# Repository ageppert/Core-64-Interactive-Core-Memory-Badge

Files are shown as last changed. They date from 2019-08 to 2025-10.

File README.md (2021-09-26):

# Core-64-Interactive-Core-Memory-Badge
Weave your own 64 bits of core memory over the top of LEDs to interact with directly using a magnetic wand.



Purchase: https://www.Core64.io

Follow this project at: https://hackaday.io/project/166155-core-64-interactive-core-memory-badge

You are in the development repository. Beta Kits and production version firmware is at https://github.com/ageppert/Core64/

# Hardware Version History (latest on top)

v0.5 Triple Board (added custom LED Matrix) - Beta Test Kits. Beta Kit Repo at https://github.com/ageppert/Core64/

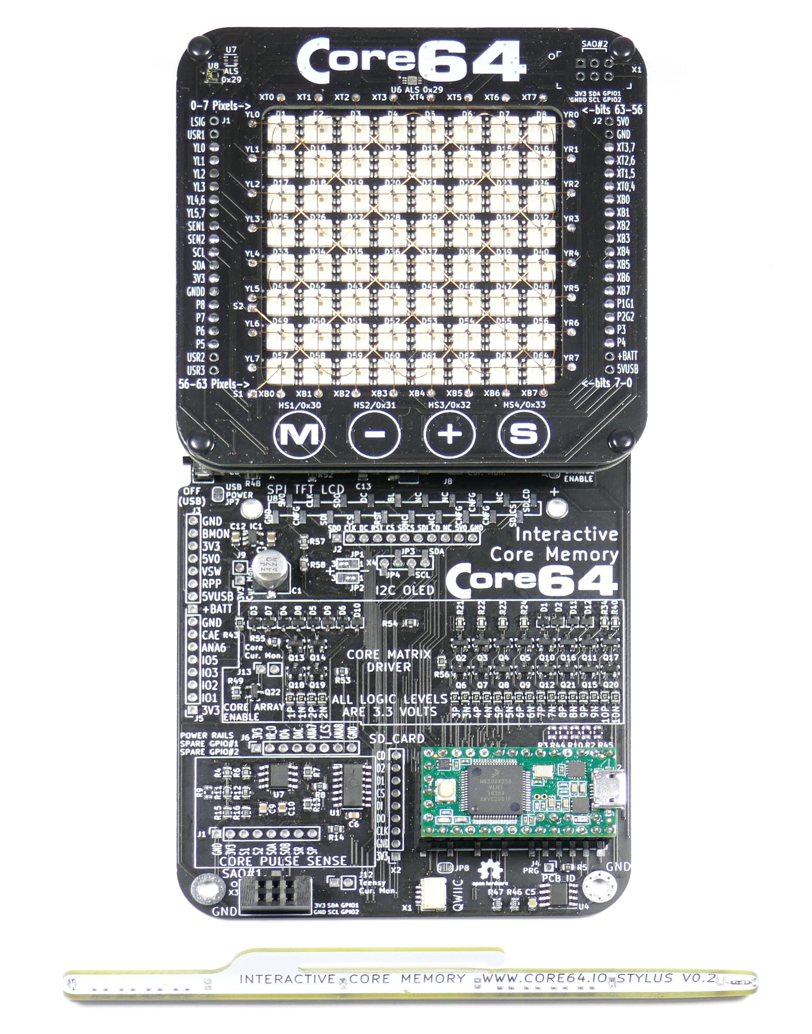
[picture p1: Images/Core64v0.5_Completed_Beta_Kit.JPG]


v0.4 Core Board - Neon Pixel Edition. Expanded Core Grid Array to work with [Neon Pixels](https://pierremuth.wordpress.com/2020/07/08/neon-pixel/)!

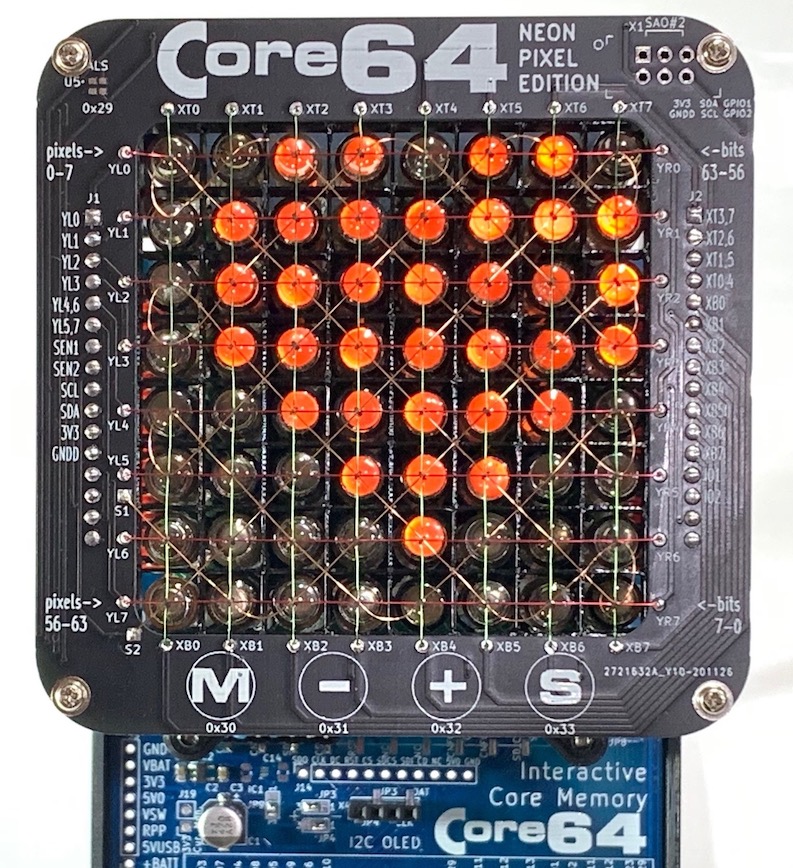
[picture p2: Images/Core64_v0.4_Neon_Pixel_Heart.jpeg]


v0.4 Dual Boards (Blue LB + Yellow CB), moved up to Teensy 3.2, removed IO Expanders, added more expansion/hacking headers.

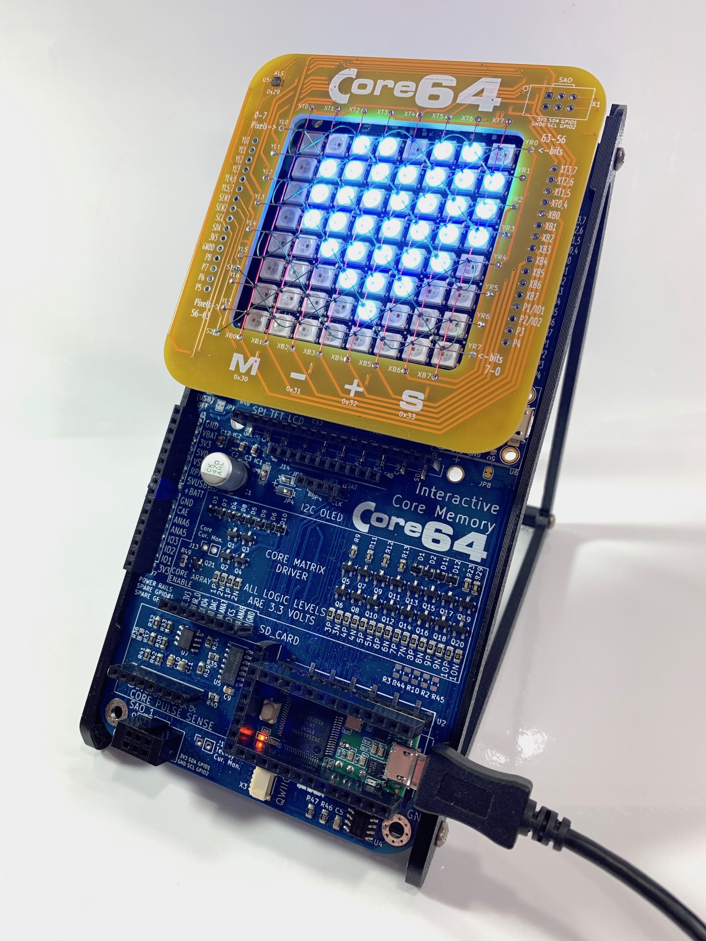
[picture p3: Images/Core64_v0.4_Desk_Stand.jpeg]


v0.3.1 Hand re-worked v0.3 with 5V0 and 3V3 regulators each seperately sourced after power switch to provide improved power supplies.

v0.3 Dual Boards (both Red) with Teensy LC. One core board, one logic board. Used IO Expanders to drive the Core matrix, which ended up being way too slow.

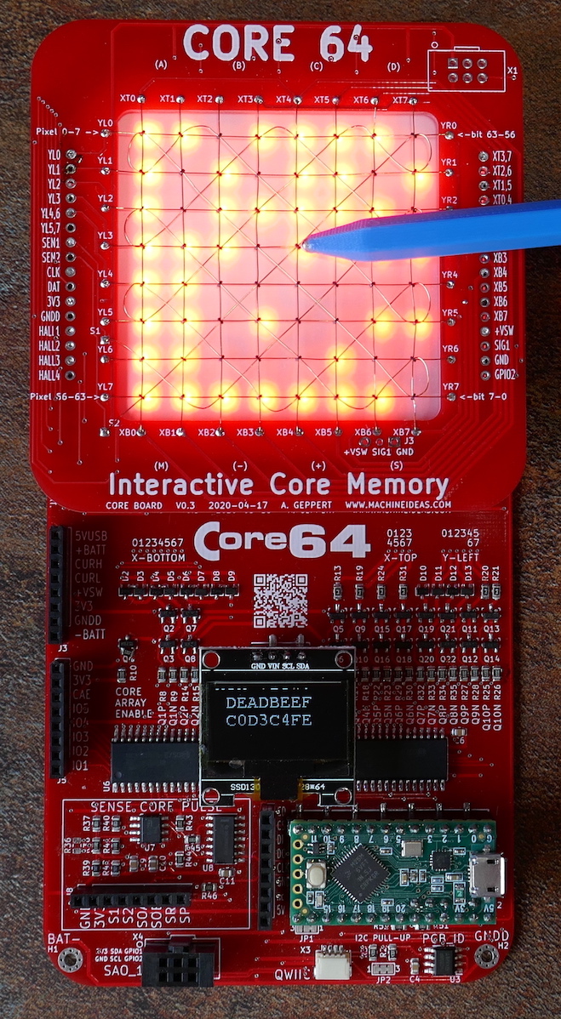
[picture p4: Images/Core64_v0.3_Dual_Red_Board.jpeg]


v0.2 Bug fixes learned from v0.1 applied. This version has not been made or tested, but should work.

v0.1.1 Single Green Board worked after I added missing OR gate circuitry!

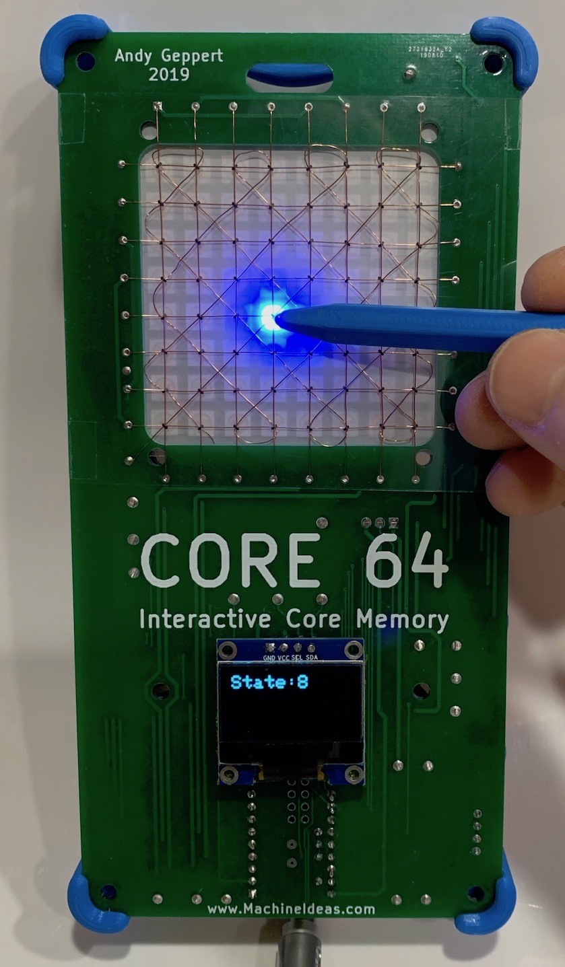
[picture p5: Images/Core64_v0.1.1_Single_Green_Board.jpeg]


v0.1 Single Green Board with Teensy LC. The first hand assembled prototype. Made one and it worked after I added missing circuitry!

Share-A-Hack version

Proof-Of-Concept version

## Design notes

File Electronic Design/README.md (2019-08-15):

# Electronic Design

Datasheets

Native KiCad files for the schematic and PCB. (KiCad Version: (5.1.2-1)-1, release build)

Teensy LC Pin Usage Mapping

BOM

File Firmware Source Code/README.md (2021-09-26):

# Firmware Source Code
Arduino project folder, sketches, libraries.

This firmware was used for development of Core64 V0.1 to V0.5.

It is now dead-ended here with V0.5, and further development is in https://github.com/ageppert/Core64/tree/master/Firmware

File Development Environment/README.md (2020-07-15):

# Development Environment
Everything is being run on a Mac
Arduino IDE 1.8.9 (firmware, see Core-64-Interactive-Core-Memory-Badge.ino for library dependencies)
Teensy Loader (interface between Arduino and Teensy development board)
Sublime Text (source code editor)
KiCad 5.1.2 (Schematic, PCB, BOM)
Inkscape (design sketches and silkscreen graphics)
Sourcetree 4.0.1 (local client for Github repository manager)

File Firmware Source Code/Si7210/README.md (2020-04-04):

# Si7210 Hall-effect sensor driver API
A portable driver written in C for Silicon Lab's Si7210 hall-effect sensor.

## Introduction
This package contains the Si7210 sensor driver.
The driver includes si7210.c, si7210.h, and si7210_defs.h files.

## Integration details
* Integrate si7210.c, si7210.h, and si7210_defs.h files into the project
* Include the si7210.h file in your code like below.

``` c
#include "si7210.h"
```

## File information
* si7210_defs.h : This header file contains definitions used by both the user and driver APIs.
* si7210.h : This header file contains the declarations of the driver APIs.
* lmt01.c : This source file contains the definitions of the driver APIs.

## Supported interfaces
* I2C

## User Guide

### Initialising the device
To intialise the device, the user must create a device structure. The user can do this by creating an instance of the structure si7210_dev. The user must then fill in the various parameters as shown below to initialise the device. THe usermust then choose the particular settings they wish to use, by filling in the 'settings' member of the device struct.

``` c
si7210_status rslt = SI7210_OK;

struct si7210_dev dev = {
    .dev_id   = SI7210_ADDRESS_0;
    .read     = usr_i2c_read;
    .write    = usr_i2c_write;
    .delay_ms = usr_delay_ms;
    .callback = callback;
};

if((rslt = si7210_init(&dev) != SI7210_OK)
    return rslt;

dev.settings.range        = SI7210_20mT;
dev.settings.compensation = SI7210_COMPENSATION_TEMP_NEO;
dev.settings.output_pin   = SI7210_OUTPUT_PIN_HIGH;
 
if((rslt = si7210_set_sensor_settings(&dev)) != SI7210_OK)
    return rslt;

if(rslt == SI7210_OK)
{
    float field;
    float temperature;

    /* Obtain field strength reading from device */
    si7210_get_field_strength(&dev, &field_strength);

    /* Obtain a temperature reading from the device */
    si7210_get_temperature(&dev, &temperature);

    printf("Field: %fmT\tTemperature: %f*C", field, temperature);
}
````

### Templates for function pointers
``` c
si7210_status usr_i2c_read(uint8_t dev_id, uint8_t reg_addr, uint8_t *data, uint16_t len)
{
    si7210_status rslt = SI7210_OK;

    /* User implemented I2C read function */

    return rslt;
}

si7210_status usr_i2c_write(uint8_t dev_id, uint8_t reg_addr, uint8_t *data, uint16_t len)
{
    si7210_status rslt = SI7210_OK;

    /* User implemented I2C write function */

    return rslt;
}

void usr_delay_ms(uint32_t period_ms)
{
    /* User implemented delay (ms) function */
}

```

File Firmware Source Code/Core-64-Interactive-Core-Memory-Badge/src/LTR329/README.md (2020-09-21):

thingTronics LTR303 Arduino Library
========================================
This is a Arduino Library for the LTR303ALS Luminiosity sensor.
This illumination sensor has a flat response across most of the visible spectrum and has an adjustable integration time. 
It communicates via I2C and runs at 3.3V. 

Repository Contents
-------------------

* **/examples** - Example sketches for the library (.ino). Run these from the Arduino IDE. 
* **/src** - Source files for the library (.cpp, .h).
* **library.properties** - General library properties for the Arduino package manager.
* **library.json** - General library properties for the Arduino package manager in JSON format
* **keywords.txt** - Contains the keywords for Arduino IDE.

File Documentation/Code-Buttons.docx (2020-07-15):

Code-Buttons

Core 64: Interactive Core Memory Badge, V0.3, Andrew Geppert, 2020-05-31

User Application

Use the cores to do something interesting

FreeRTOS

Facilitate running all task threads

HAL : Buttons.h

Buttons_Setup

Button1State

TODO:

HAL: Interact with the hardware in an abstract and conceptual way, using high level perspective. Such as visual and logical arrangements.

DRIVER: Control the signals to the hardware and the hardware itself. Control the pins of the microcontroller

Digital Write Fast

Sub-Functions

Digital Write Fast

Controls the electronics through #include HardwareIOmap.h, Arduino.h. Translates active/inactive to low/high for the IO signals.

BSP: Abstraction of MCU pin reference number to the physical pin on the chip

Arduino.c and .cpp in the Arduino IDE

Abstraction of MCU pin to integer pin reference number

Arduino.h

HAL

DRIVER

Hardware V0.1.0 through V0.2.0 the Digital Read Fast library in the LIBRARIES folder.

Hardware V0.3.0 IO Expander MCP2017

This is implemented to talk to the hardware and has many of its own layers and BSPs.

BSP

Combination of files buried in the FastLED Library, and Arduino.

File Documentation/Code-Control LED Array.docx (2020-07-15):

Code-Control LED Array

Core 64: Interactive Core Memory Badge, V0.1, Andrew Geppert, 2020-01-23

User Application

Use the cores to do something interesting

FreeRTOS

Facilitate running all task threads

LED_Array_HAL.h (with new API)

LED_Array_Init (create an instance)

LED_Array_Memory_Clear (all buffers)

LED_Array_Monochrome_Set_Color (color)

LED_Array_Test_Count_Binary

LED_Array_Test_Pixel_String

LED_Array_Test_Pixel_Matrix

LED_Array_Display_Binary ()

LED_Array_Write_Binary()

TODO:

Convert old write/display to new API

Cleanout unused functions

LED_Array_HAL.cpp

Interaction with the abstract memory buffers which define the LED Array for the user to view:

BINARY [64 bit data word, monochrome]

STRING [1D 64 pixel string, monochrome]

MATRIX_MONO [2D 8x8 pixel matrix, monochrome]

MATRIX_COLOR [2D 8x8 pixel matrix, color]

When the buffer is requested for display on the LED Array, appropriate translations are applied for correct orientation of the view to the user.

Enables user application to interact with any abstract LED Array (as a memory buffer) in order to set each real LED as desired.

Interaction is done in one of layouts:

Visual, 1D string, 2D matrix (x,y)

Binary, logical (bits, bytes, word)

And one of two color modes:

Monochrome

HSV

These functions ask the driver (in this case the FastLED library) to do the detailed work.

HAL: Interact with the hardware in an abstract and conceptual way, using high level perspective. Such as visual and logical arrangements.

FastLED.h

src/FastLED Library

Sub-Functions

Bit Banged SPI

FastLED_Config.h

Define my custom LED array params for the FastLED library.

DRIVER: Control the signals to the hardware and the hardware itself. Control the pins of the microcontroller

FastLed.c

Controls the electronics through #include HardwareIOmap.h, Arduino.h. Translates active/inactive to low/high for the IO signals.

BSP: Abstraction of MCU pin reference number to the physical pin on the chip

Arduino.c and .cpp in the Arduino IDE

Abstraction of MCU pin to integer pin reference number

Arduino.h

HAL

LED_ARRAY_HAL.h (defines the API)

LED_ARRAY_HAL.cpp (was LED_Array.cpp).

The application accesses the driver by calling API functions in the driver library.

Set each LEDs on/off or color state in a memory buffers.

Read each LEDs state from the memory buffers.

Clear the memory buffers.

Request a memory buffer to be displayed on the LEDs.

Test functions: cycle through all LEDs in order of 1D and 2D arrangements to confirm expected order of the LEDs.

The driver contains the LED Array memory buffer.

Monochrome 2D 8x8 image as viewed by the user.

Monochrome 1D 64 bit word, with LSB on lower right, MSB on left. First row is low byte of 64 bit word, top row is highest byte.

Color 2D 8x8 image as viewed by the user.

DRIVER

In this case, the FastLED-3.3.2 library in the LIBRARIES folder. Nothing I have to write custom.

This is implemented to talk to the hardware and has many of its own layers and BSPs.

BSP

Combination of files buried in the FastLED Library, and Arduino.

DEFINITIONS

THREE MONOCHROME SCREEN MEMORY BUFFERS

LED SCREEN MEMORY MONOCHROME 2D IMAGE: The LED array as viewed by the user with badge in hand, or looking at C source code array definitions, for the case of symbols drawn on the screen.

Was LEDArrayMonochromeMemory [y][x] : Monochrome version of the LED Screen RAM. Easy to visualize screen memory in the form of C Syntax array. Just make sure to use the proper y, x order because of the C syntax. Upper left is 0,0 and lower right is 7,7.

LED SCREEN MEMORY MONOCHROME 1D PIXEL STRING: A one-dimensional array addressable 0 to 63. Upper left is 0, lower right is 63. Ordered from left to right, then top to bottom.

LED SCREEN MEMORY MONOCHROME 1D DATA: The LED array as viewed by the user, representing 64 bits of data as 8 rows of 8 bits (or 8 rows of bytes) with the least significant bit on the right, and the least significant byte on the bottom. In other words, the whole data value is 64 bits and bit 0 is in the lower right, and bit 63 in the upper left. This is opposite of the LED SCREEN MEMORY MONOCHROME 1D STRING.

DISPLAY ONE OF THE MONOCHROME SCREEN MEMORY BUFFERS USING CORRESPONDING FUNCTIONS

DISPLAY LED SCREEN MONOCHROME 2D IMAGE: Copies the associated screen memory into the appropriate position of the leds[63] array and sends it to the LED array.

DISPLAY LED SCREEN MONOCHROME 1D PIXEL STRING: Copies the associated screen memory into the appropriate position of the leds[63] array and sends it to the LED array.

DISPLAY LED SCREEN MONOCHROME 1D DATA: Copies the associated screen memory into the appropriate position of the leds[63] array and sends it to the LED array.

LED SCREEN ARRAY FASTLED: A virtual two-dimensional array addressable as in the form of y, x with a range of 0 to 7 for both values. This is part of the FastLED example library (/Examples/FastLED/XYMAtrix), and this arrangement is converted to leds[63] with awareness of the serpentine electrical arrangement of the string of LEDs using the functions XY() or YX().

LED ARRAY PIXEL: A single pixel

leds[63]: The one-dimensional array that holds color values for the FastLED library to send to the string of LEDs. The lowest LED Array data level that is easily user accessible. This arrangement follows the serpentine electrical arrangement of the LEDs on the Pimoroni Unicorn Hat.

VisualLED2DMatrix, User LED Matrix [x,y] : The orientation of the LED array for the user.

*** To convert Array to Matrix use function YX(y,x). ***

CSyntaxCORELEDArray, C Syntax LED Array [y,x] : The orientation of the array which aligns with the C language array definition. Note the y position (row) is written first, followed by x position (column). The core matrix wires are labeled this way.

CSyntaxBINARYArray, Binary LED Array [y,x] : The orientation of the array which aligns with LSB in the lower right.

WriteOneBitToMonochromeLEDArrayMemory(uint8_t bit, bool value) : Update a single bit of LED screen Memory. Bit position is defined

LEDArrayMonochromeUpdate() : Read 64 bits of monochrome LED Screen memory and update the LED Array.

FastLED2DMatrix, FastLED (Unicorn Hat) LED Matrix [x,y] : The ordering of the LEDs defined in the FastLED library.

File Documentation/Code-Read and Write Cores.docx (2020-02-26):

Code-Read and Write Cores

Core 64: Interactive Core Memory Badge, V0.1, Andrew Geppert, 2020-02-17

User Application

Use the cores to do something interesting

FreeRTOS

Facilitate running all task threads

Core_Mem_HAL.h (with new API)

IMPLEMENTED

Core_Mem_Bit_Write (bit 0-63, 0/1)

Core_Mem_Bit_Read (bit 0-63)

Core_Mem_Array_Write()

Core_Mem_Array_Read()

Core_Mem_Array_Write_Test_Pattern()

Core_Mem_Monitor()

NOT YET FULLY IMPLEMENTED

Core_Mem_Init (create an instance)

Core_Mem_Test (read all, clear all, verify clear, rewrite original state, verify rewrite, return 0-no test pass, 1st passed, 2nd passed)

Core_Mem_Wipe (set all to 0 or 1)

Core_Mem_Visual_Write (x, y)

Core_Mem_Bit_Toggle (bit 0-63)

Core_Mem_Byte_Write (Byte 0-7, 0-255)

Core_Mem_Byte_Read (Byte 0-7)

Core_Mem_Word_Write (0x0-FFFFFFFF FFFFFFFF)

Core_Mem_Word_Read ()

Core_Mem_HAL.c

Enables user application to interaction with the abstract core memory space (as a buffer) and request read/write to the real core memory.

Interaction is done in one of two modes: Visual (x,y)

logical (bits, bytes, word).

These functions ask the driver to do the detailed work.

HAL: Interact with the hardware in an abstract and conceptual way, using high level perspective. Like visual and logical arrangements.

Core_Mem_Driver.h

AllDriveIoSafe()

AllDriveIoRead()

AllDriveIoWrite()

AllDriveIoSetBit(bit)

AllDriveIoClearBit(bit)

AllDriveIoEnable()

AllDriveIoDisable()

HAL: Control the logical array to access the array of cores

Core_Mem_Driver.c

Translate bit # to row/col position.

Functions to control the array of wires.

Function to read sense signal.

Indirectly controlling hardware as active and Inactive.

Core_Mem_Driver.h

AllDriveIoSafe()

AllDriveIoRead()

AllDriveIoWrite()

AllDriveIoSetBit(bit)

AllDriveIoClearBit(bit)

AllDriveIoEnable()

AllDriveIoDisable()

Sub-Functions

MatrixEnableTransistorInactive()

MatrixEnableTransistorActive()

MatrixDriveTransistorsInactive()

SetRowAndCol (uint8_t row, uint8_t col)

ClearRowAndCol (uint8_t row, uint8_t col)

Translate to New discrete functions:

Core_IO_Enable_Line (on, off)

Core_IO_XY_Lines_All_Safe

Core_IO_XY_Line_Pair (north, south)

Core_IO

DRIVER: Control the pins of the microcontroller

Core_Mem_Driver_Config.h

Define the size, layout, matrix to drive transistor to wire mapping, maybe the MCU memory buffer.

Core_Driver.c

Accesses the core memory bits by directly twiddling the IO lines in the core matrix. Controls the electronics (enable/drive transistors, read sense signal) through #include HardwareIOmap.h, Arduino.h. Translates active/inactive to low/high for the IO signals.

BSP: Abstraction of MCU pin reference number to the physical pin on the chip

Arduino.c and .cpp in the Arduino IDE

Abstraction of MCU pin to integer pin reference number

Arduino.h

2020-01-06 updated thinking on the layers above.

Top Levels as User Application and the FreeRTOS is OK.

Next level down is the DRIVER which has an API defined in it, and accessible from the Application.

Layer below that is the HAL and it reads and writes to the IO lines. But not directly.

BSP is the bottom layer of firmware, and it maps the friendly names of the IO lines in the HAL to the MCU specific pins. To keep things simple, this is effectively the Arduino layer.

Then there is the hardware.

EXAMPLE WITH LED ARRAY

DRIVER

LED_ARRAY_DRIVER.cpp (was LED_Array.cpp) and is in the DRIVERS folder. Includes LED_ARRAY_DRIVER.h.

The application accesses the driver by calling API functions in the driver.

Set each LEDs on/off or color state in a memory buffers.

Read each LEDs state from the memory buffers.

Clear the memory buffers.

Request a memory buffer to be displayed on the LEDs.

Test functions: cycle through all LEDs in order of 1D and 2D arrangements to confirm expected order of the LEDs.

The driver contains the LED Array memory buffer.

Monochrome 2D 8x8 image as viewed by the user.

Monochrome 1D 64 bit word, with LSB on lower right, MSB on left. First row is low byte of 64 bit word, top row is highest byte.

Color 2D 8x8 image as viewed by the user.

HAL

Hardware Abstraction Layer, or in this case, Library.

The FastLED-3.3.2 library in the LIBRARIES folder.

This is implemented to talk to the hardware and has many of its own layers and BSPs.

BSP

Combination of files buried in the FastLED Library, and Arduino.

Set – top end of the column wire and left end of row wire are positive (VMEM). Other ends negative (GNDPWR).

Clear - top end of the column wire and left end of row wire are negative (GNDPWR). Other ends positive (VMEM).

Each end of a single row or column wire can be connected to either VMEM (3-4V) or GNDPWR (0V). That means that two transistors must be enabled for a row or column wire to be energized. Since a core is set or cleared by the current from TWO wires, a total of 4 transistors must be enabled .

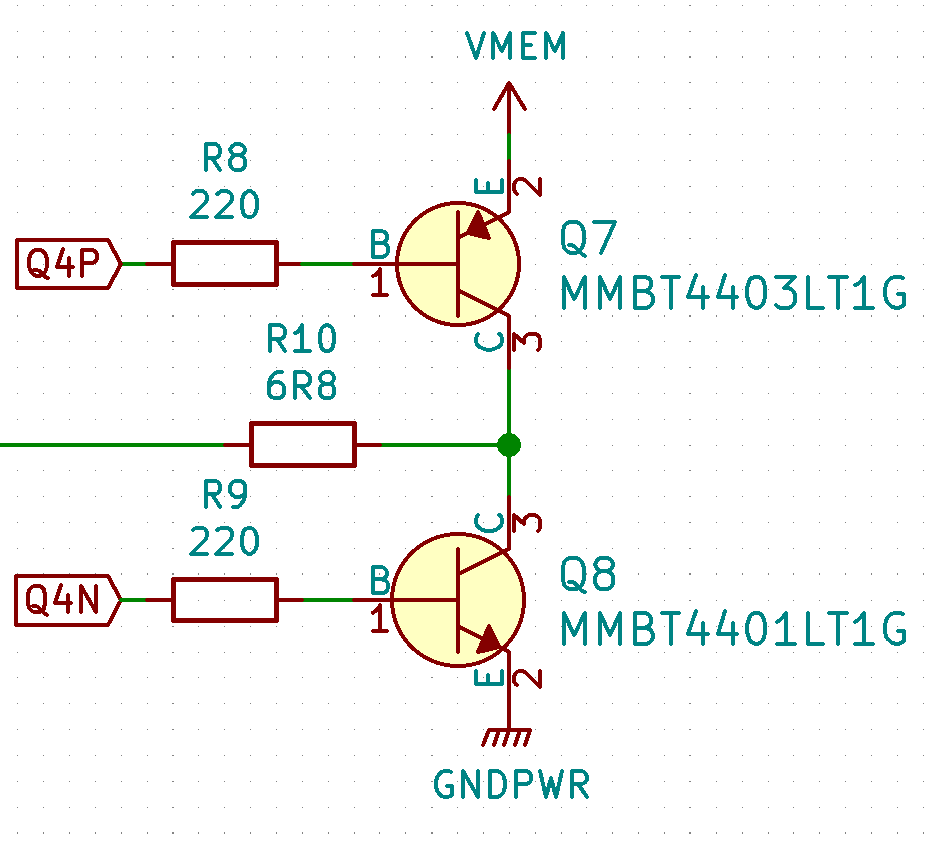
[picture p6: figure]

4403 PNP – Enabled with base LOW, or negative.

High side (sourcing) odd numbered matrix drive pins (7) with P suffix (Q4P). The load is connected to negative and the PNP transistor switches the positive voltage.

4401 NPN – Enabled with base HIGH, positive.

Low side (sinking) even numbered matrix pins (8) with N suffix (Q4N). The load is connected to positive and the NPN transistor switches the negative (low) side.

Safe state, all transistors inactive:

Enable Pin = LOW

Matrix Drive 1, 3, 5, 7, 9, 11, 13, 15, 17, 19 = HIGH

Matrix Drive 2, 4, 6, 8, 10, 12, 14, 16, 18, 20 = LOW

This outline of how it works could be shown as three indented levels. Level one is DRIVER, level two is HAL, level three is HARDWARE.

1. Since the output lines used to address the matrix may have other functions (like 17 is shared with the onboard Teensy LC LED), need to check all of the lines to see if any are not in the safe state for addressing the matrix.
  1.1. If a line is set other than safe [future work]
  1.2. save the state for later reference [future work]
  1.3. set all matrix lines and the enable line to safe states.
2. Set a core to 1 (bit 0, upper left corner)
  2.1. Set column (X0)
    2.1.1. Connect top end of column (XT0) to VMEM
      2.1.1.1. Activate top transistor (Q3P), Pin_Matrix_Drive_5, LOW
    2.1.2. Connect bottom end of column (XB0) to GNDPWR
      2.1.2.1. Activate bottom transistor (Q1N), Pin_Matrix_Drive_2, HIGH
  2.2. Set row (Y0)
    2.2.1. Connect left end of row (YL0) to VMEM
      2.2.1.1. Activate left transistor (Q7P), Pin_Matrix_Drive_13, LOW
    2.2.2. Connect right end of row (YR0=YR4=YL4=YL6) to GNDPWR
      2.2.2.1. Activate right transistor (Q9N), Pin_Matrix_Drive_17, HIGH
  2.3. Set Enable
    2.3.1. HIGH
    2.3.2. Wait ?? ns to lock in the magnetized state.
    2.3.3. Clear enable
  2.4. Return 4 transistors to safe states
  2.5. Return any other shared lines that weren’t initially safe, to the state they were at.
  2.6. End
3. Clear a core to 0 (bit 0, upper left corner)

Decode bit position (0…63) to matrix drive transistors (1…20)

Each row of this array corresponds to the bit #. First row is bit 0, last row is bit 63.

Row contains four matrix drive #s, each followed by the corresponding low/high needed to activated the transistor.

Odd numbered drive line transistors are active LOW

Even numbered drive line transistors are active HIGH

uint8_t CoreMemoryMatrixDriveSetBitTransistors[] = {

{ 5,0,2,1, 13,0,17,1},

…

{ }

};

Store core value as:

uint64_t CoreMemorySixtyFourBit = 0b0000…1111;

-AND-

bool CoreMemoryArray[] = {

{ 0, 1, 2, 3, 4, 5, 6, 7, 8},

…

{55,56,57,58,59,60,61,62,63}

};

Core Library Basics

1. CoreWriteBit (position #, value)
  1.1. Position # is 0 to 63 for the 64 bits. Starting upper left as 0, left to right, top to bottom, ending with bit 63 in the lower right.
  1.2. Value is Boolean 0 or 1
  1.3. Returns nothing
2. CoreReadBit (position #)
  2.1. Returns value Boolean 0 or 1
3. CoreWriteByte (position #, value)
  3.1. Position # is 0 for the top row, 7 for bottom row. MSb is left.
  3.2. Value is uint8_t 0-255
  3.3. Returns nothing
4. CoreReadByte (position#)
  4.1. See above
5. CoreWrite64bits (value)
  5.1. Value is uint64_t
  5.2. Returns nothing
6. CoreRead64bits (void)
  6.1. Return uint64_t

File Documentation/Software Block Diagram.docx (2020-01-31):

Core 64: Software Block Diagram

User Application

Speaker

Expansion Port

FreeRTOS

Process Monitor

Serial Debug Port Update

Memory Monitor

Button Detect

Battery Voltage

Heartbeat Blink

LED Array

HAL

Core Memory

HAL

LED Array

Driver

Core Memory

Driver

OLED

3rd Party Libraries (FastLED …)

Arduino Libraries

Hardware

LAYERS | SYSTEM | LED ARRAY EXAMPLE | CORE MEMORY EXAMPLE
Application | Task_Top_Level_State_Machine: The user application. Initially this a few different demo and test modes of operation, using different combinations of Middleware Functionality.
RTOS | Arduino_FreeRTOS.h: manages everything else which are all running as tasks in the RTOS.
Middleware
HAL | | | Core_Mem_Driver (rename this to Core_Mem_HAL):
Drivers and Board Support | Arduino hidden includes HardwareIOMap.h
Hardware | Teensy MCU GPIO | Teensy MCU GPIO

Considering changing the paradigm to HAL over DRIVER instead of the other way I was thinking about it.

Reading the book: Reusable Firmware Development by Jacob Beningo

HAL over DRIVER

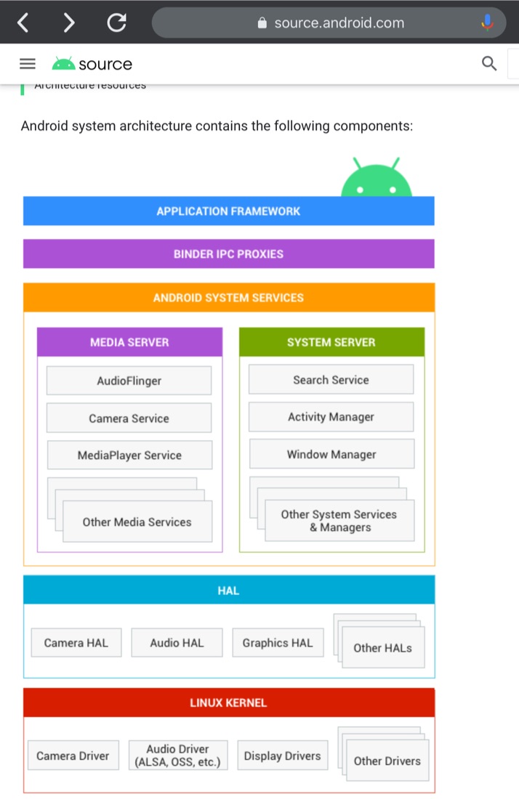
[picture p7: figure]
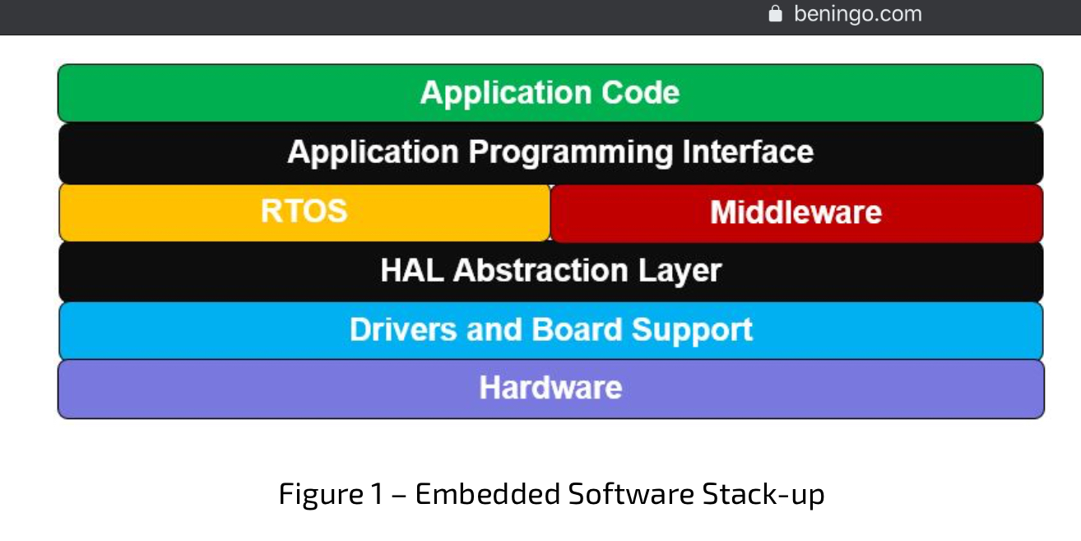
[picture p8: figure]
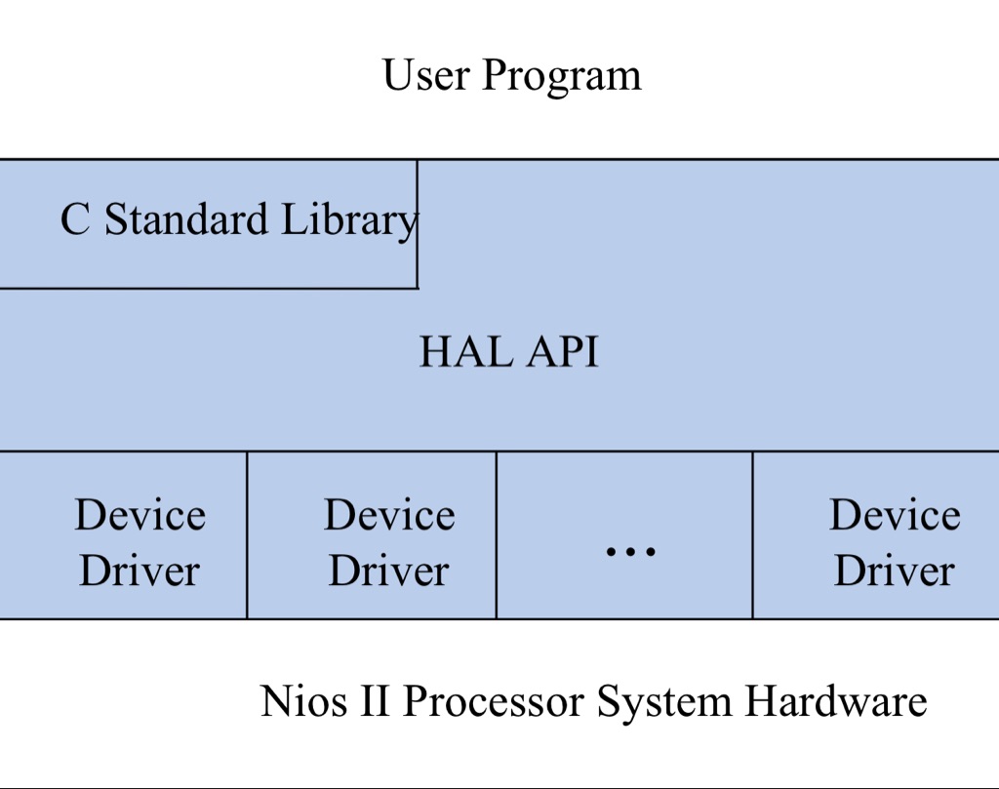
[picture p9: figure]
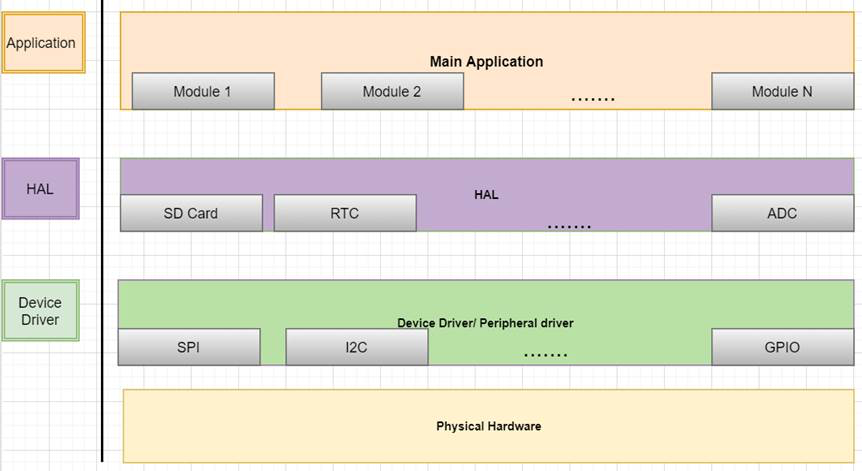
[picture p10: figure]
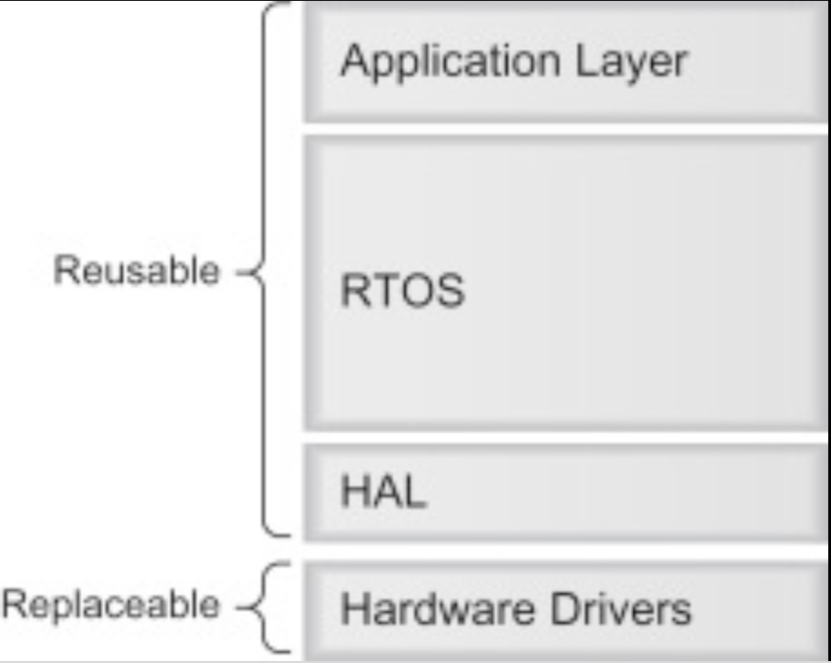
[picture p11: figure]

DRIVER over HAL

DRIVER IN the HAL

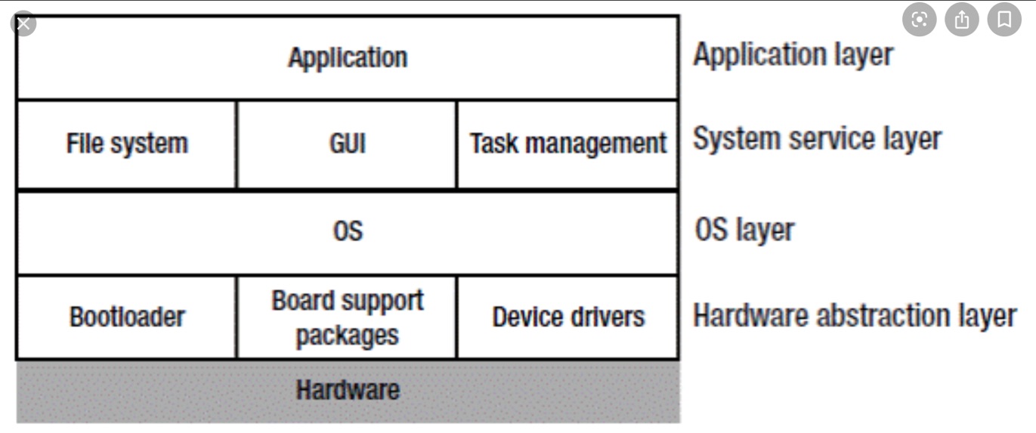
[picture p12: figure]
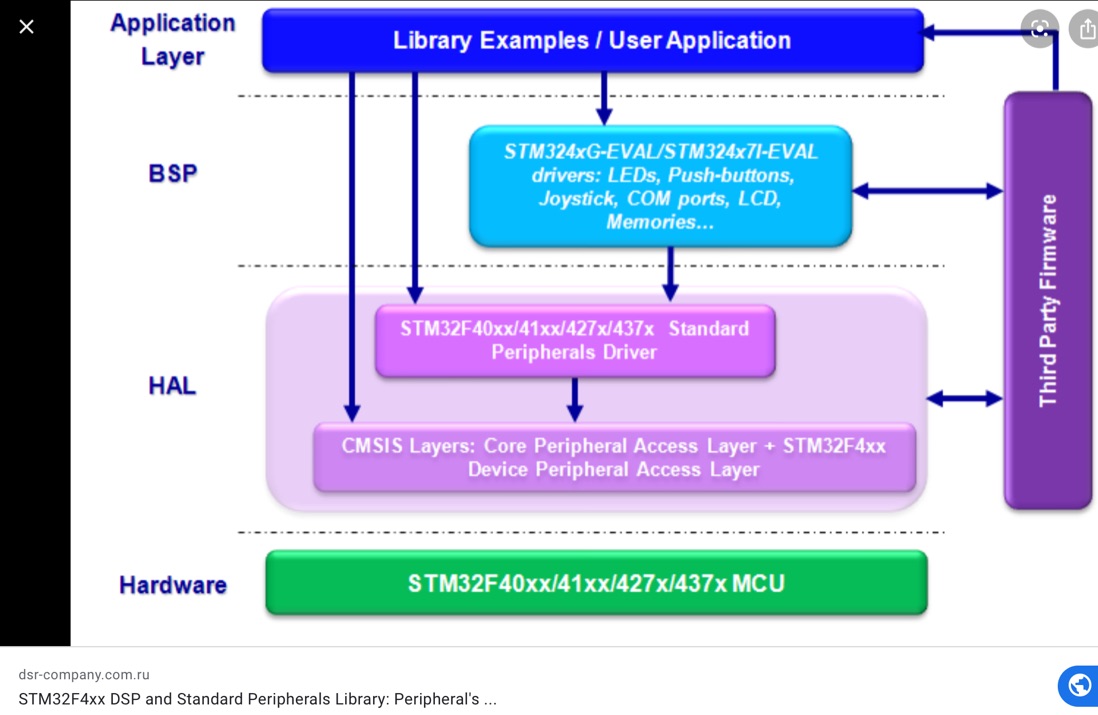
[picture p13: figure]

NO DRIVER

NO HAL

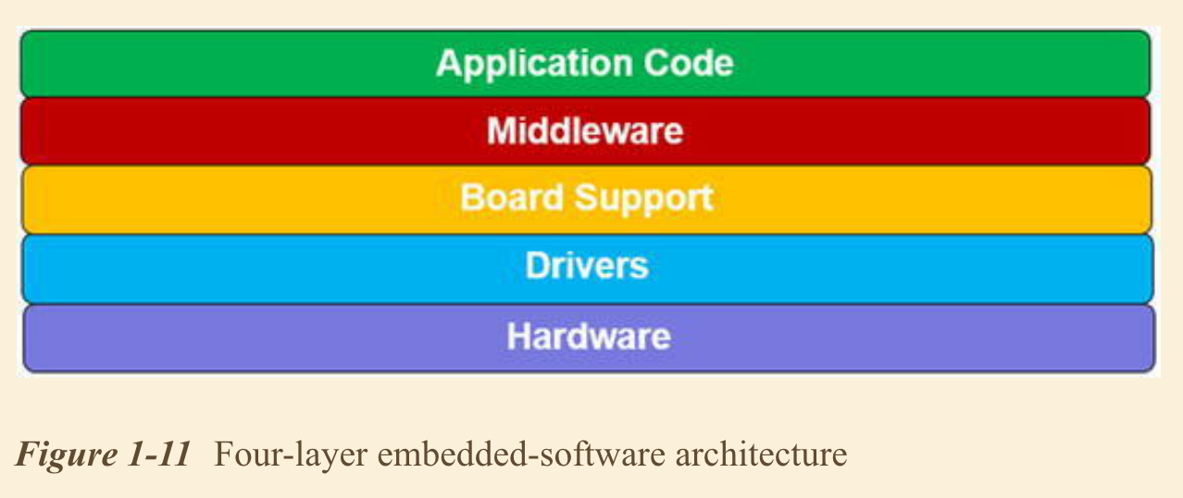
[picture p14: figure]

Directory Structure Ideas

The following figure shows the top-level source tree:

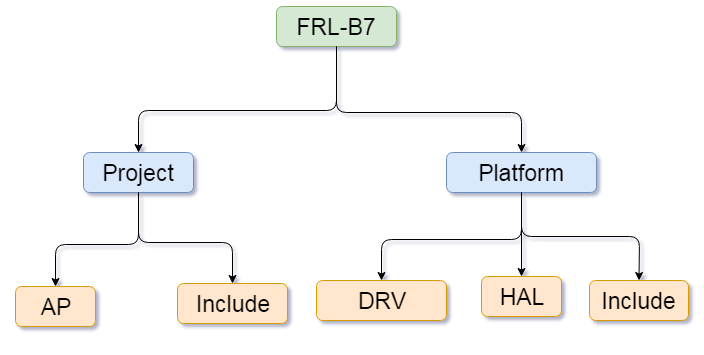
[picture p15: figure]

Project: It holds main application layer only.

I. AP : Application related all .c files are placed under the AP directory
II. Include: It holds .h files of application layer

Platform: It is divided into two sub-directory.

I. DRV: Drivers related APIs
II. HAL: Hardware application related APIs
III. Include: It holds .h files of DRV and HAL layer

1 Core 64: Interactive Core Memory Badge, v0.1, Andrew Geppert2020-01-08

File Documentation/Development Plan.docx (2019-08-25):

Development Plan

Core 64: Interactive Core Memory Badge, Andrew Geppert, 2019-08-24

2019

Jan : Proof-of-concept with 4x8

Feb :

Mar :

Apr :

May : Maker Faire Bay Area, Share-A-Hack

Jun : gathering feedback

Jul : Design 8x8 initial prototype, initial sourcing

Aug : Prototype v0.1

Sep : Establish full demo functionality, consider retail paths

Oct : Share, gather feedback, revise design to v0.2

Nov : Prototype v0.2

Dec : Distribute prototypes to a wider audience and gather feedback

Refine design for a pre-production batch

2020

Jan : Select manufacturing partners, agreements

Feb : Pre-production build, test

Mar :

Apr :

May : For sale

Jun :

Jul :

Aug :

Sep :

Oct :

Nov :

Dec :

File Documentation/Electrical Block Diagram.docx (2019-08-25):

Electrical Block Diagram

Core 64: Interactive Core Memory Badge, v0.1, Andrew Geppert, 2019-08-24

RGB LED Array

On/Off

Battery

Micro USB

Power/Program

Speaker

OLED Display

Expansion Port

Core Sensing

Circuit

Hall Switch

Battery Manager

Teensy LC

Y-Wire Drive Circuit

X-Wire Drive Circuit

Hall Switch

Hall Switch

Hall Switch

Core Memory Array

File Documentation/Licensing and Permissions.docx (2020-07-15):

Licensing and Permissions

Core 64: Interactive Core Memory Badge, Andrew Geppert, 2019-08-24

References:

https://choosealicense.com/

Inspirations:

http://www.corememoryshield.com by Ben North and Oliver Nash (http://shieldlist.org/north-and-nash/core-memory

open source hardware license links)

http://www.tindie.com/products/kilpelaj/core-memory-shield-for-arduino/ by Jussi Kilpeläinen

http://rolfebozier.com/archives/113 by Rolfe Bozier

https://sites.google.com/site/wayneholder/one-bit-ferrite-core-memory by Wayne Holder

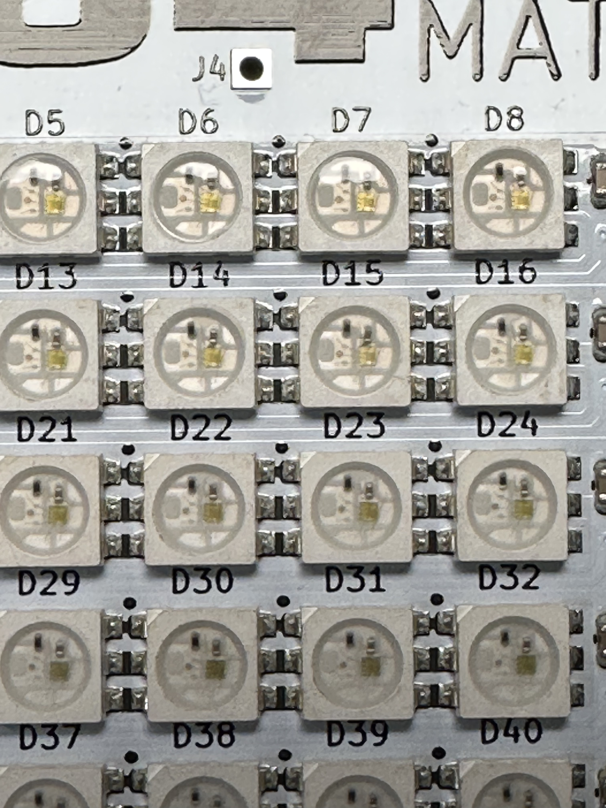
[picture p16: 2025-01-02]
Electronic Design/Core64 LM v1.0/Pictures/LED_PCB_V1.0_Batch.jpg

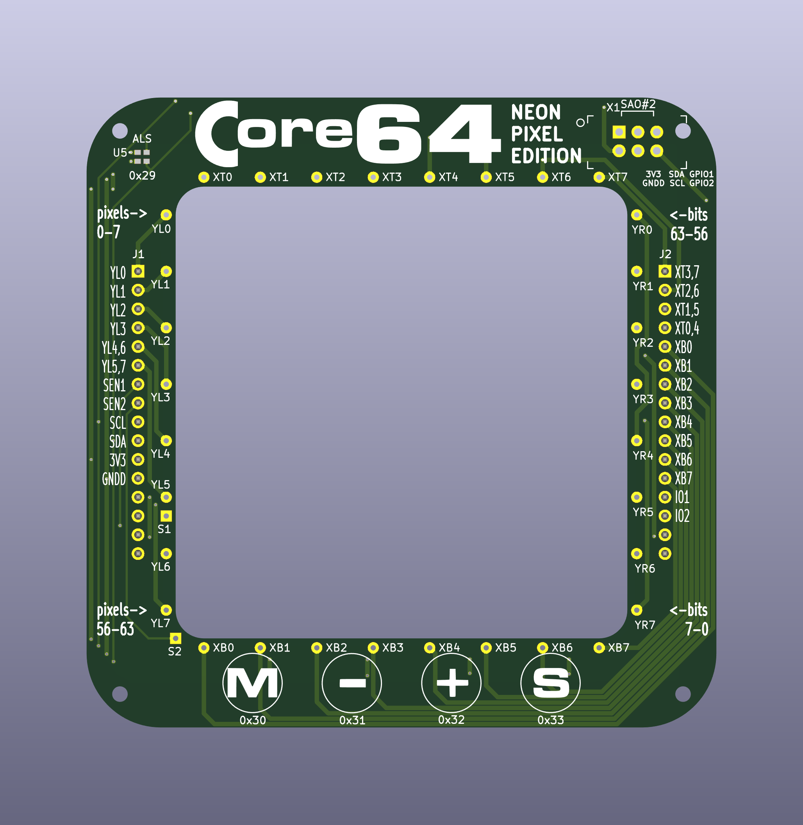
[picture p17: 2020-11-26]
Electronic Design/Core64 CB v0.4-NP/Core64 CB v0.4-NP render front.png

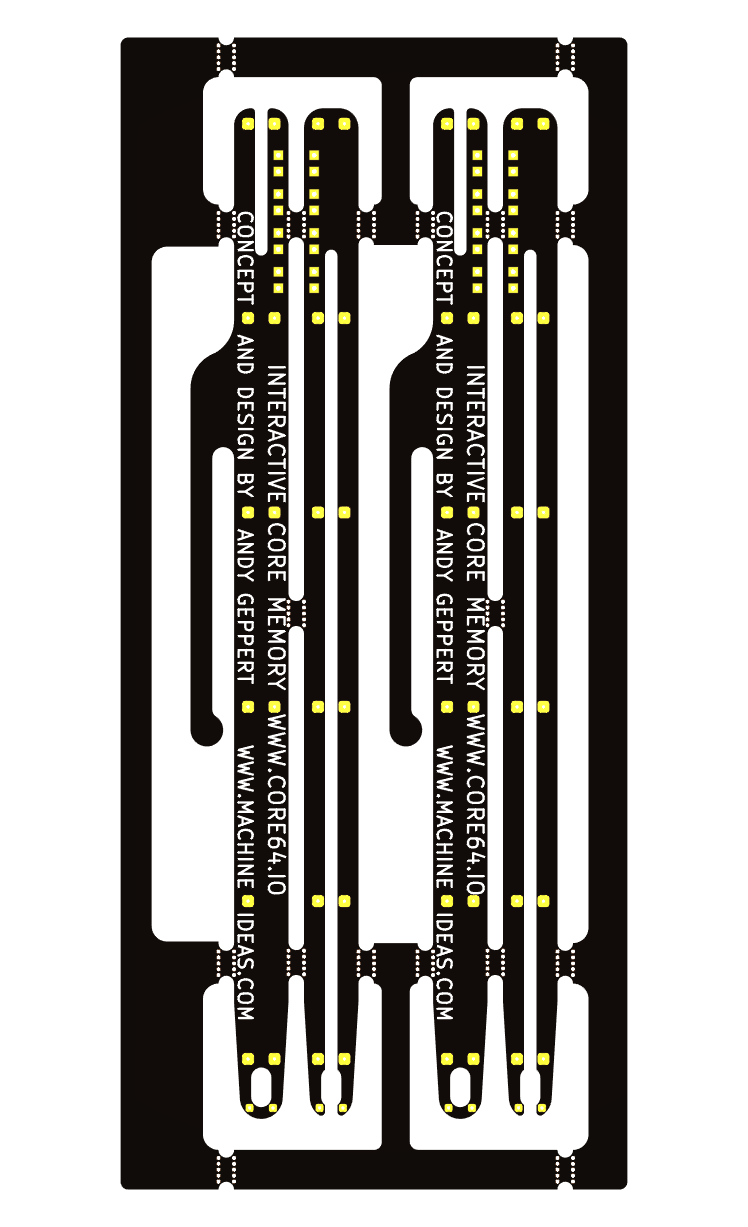
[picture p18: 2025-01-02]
Electronic Design/Core64 Stylus v0.5/Core64 Stylus Render Back.png

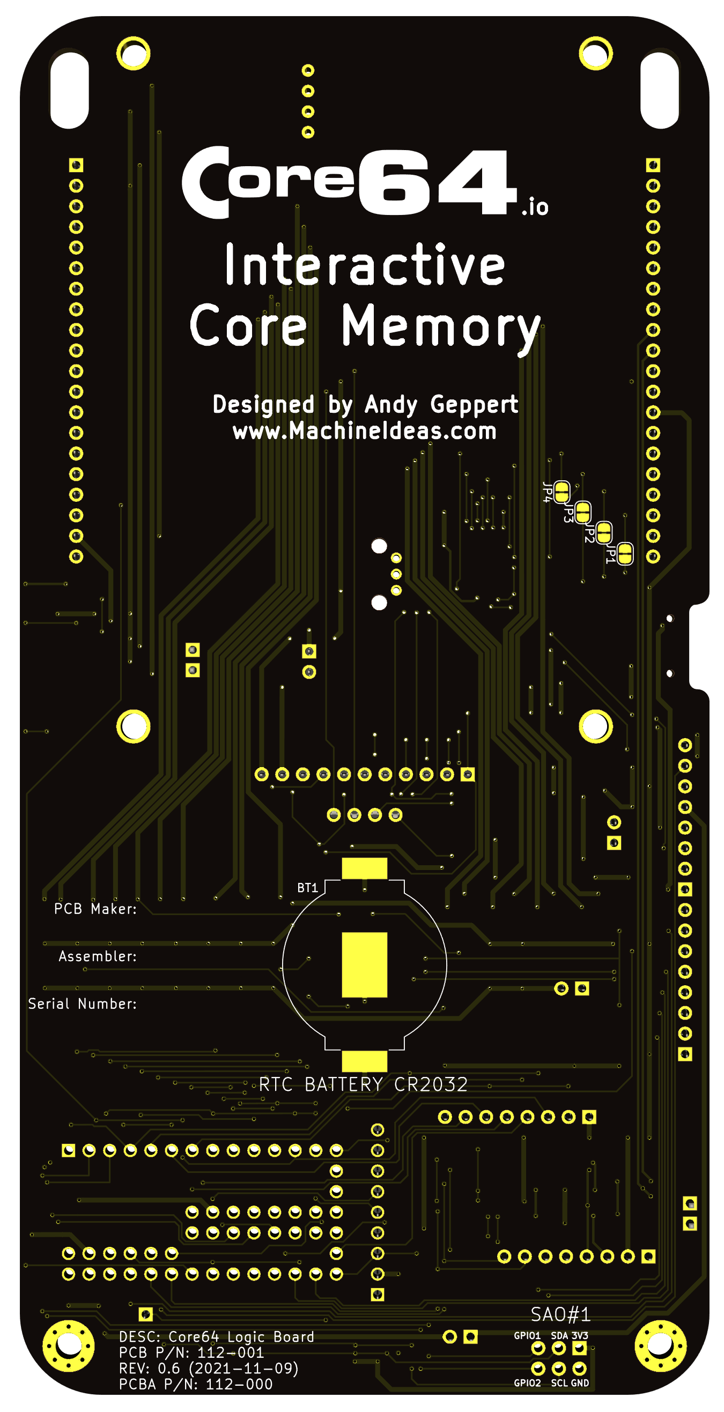
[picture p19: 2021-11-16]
Electronic Design/Core64 LB v0.6/Core64 LB v0.6 Render Bottom.png

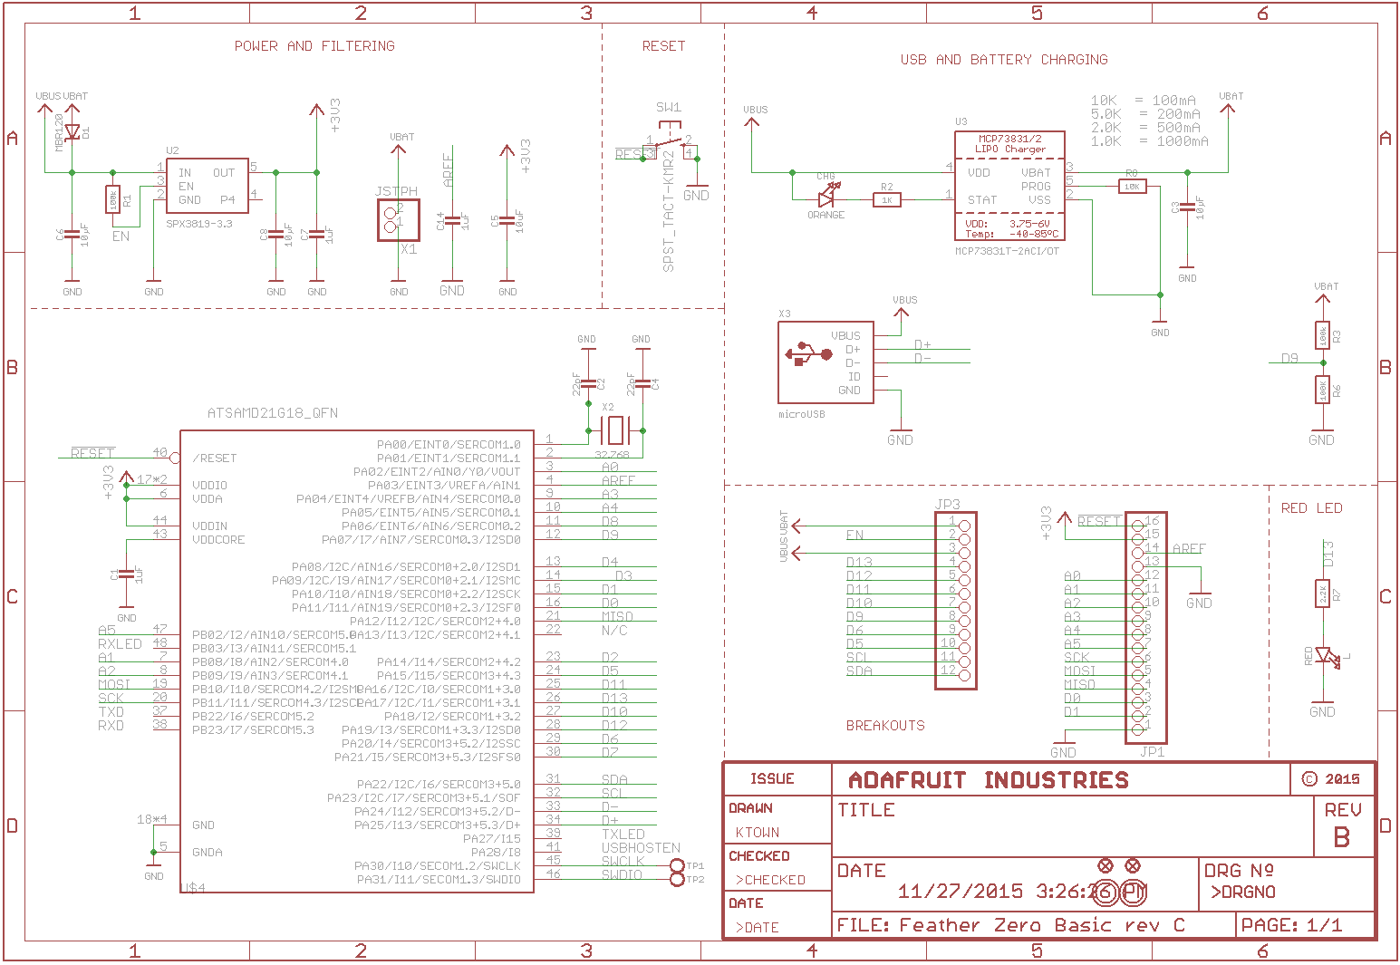
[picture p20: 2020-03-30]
Datasheets/Adafruit Feather M0 Schematic.png

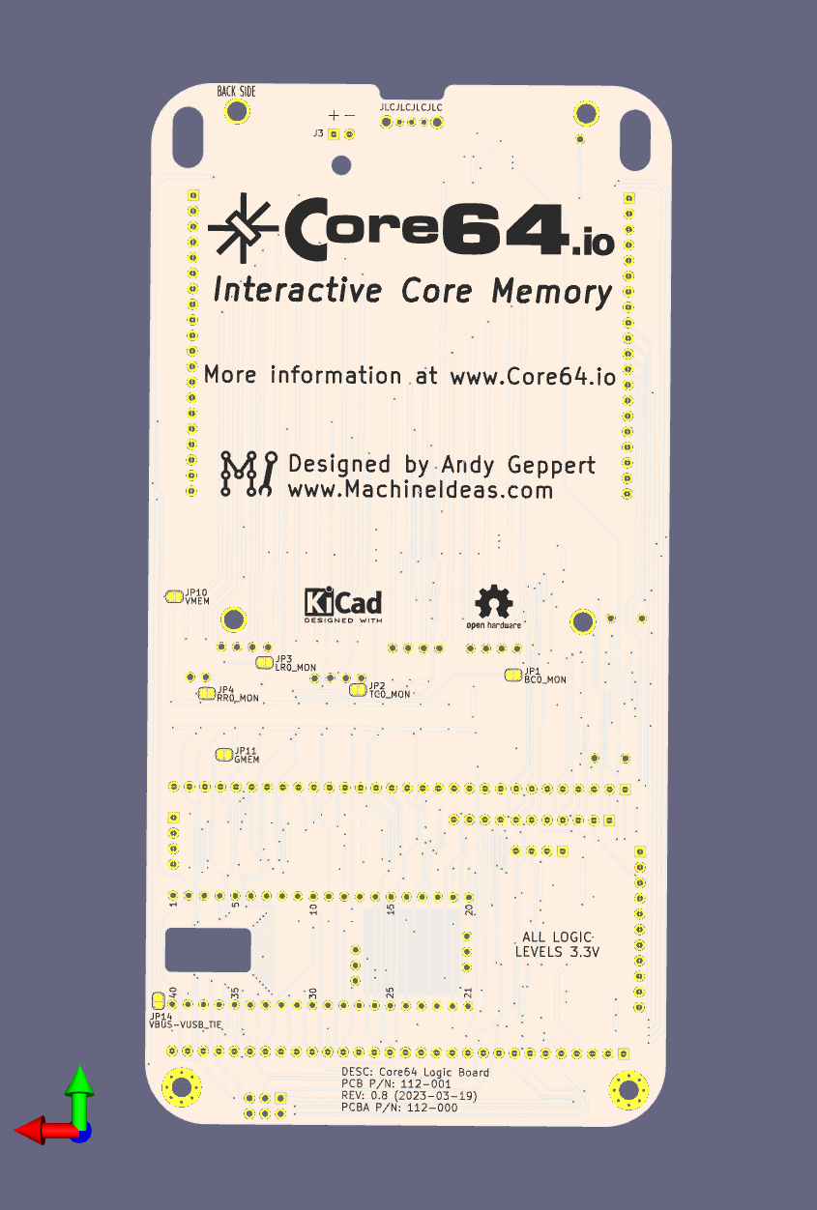
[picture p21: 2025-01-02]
Electronic Design/Core64 LB v0.8 KiCAD 6/Core64_LB_Outputs/Core64 LB V0.8 Render Bottom.png

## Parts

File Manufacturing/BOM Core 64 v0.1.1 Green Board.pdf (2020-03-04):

Source: | /Interactive Core Memory Badge v0.1/Interactive Core Memory Badge v0.1.sch
Date: | Saturday, August 10, 2019 at 07:24:35 PM
Tool: | Eeschema (5.1.2-1)-1
Generator: | kicad.app/Contents/SharedSupport/plugins/bom_csv_grouped_by_value.py
Component Count: | 88
Component Cost Per unit - > | $ 67.33 | $ 65.77 | $ 45.04 | $ 36.88
Quantity of Assemblies - > | 1 | 10 | 100 | 1000
Jellybean components from Digi-key | Extended | Extended | Extended | Extended
Digi-Key Part Number | Manufacturer Manufacturer Part Number Description | Quantity | Price | Quantity | Price | Quantity | Price | Quantity | Price
MMBT4403LT1GOSCT-ND ON SEMICONDUCTOR (VA) MMBT4403LT1G TRANS PNP 40V 0.6A SOT23 | 10 0.07350 | $ | 0.74 | 10 0.07350 | $ | 7.35 | 10 0.03084 | $ | 30.84 | 10 0.03084 | $ | 308.40
MMBT4401LT1GOSCT-ND ON SEMICONDUCTOR (VA) MMBT4401LT1G TRANS NPN 40V 0.6A SOT23 | 11 0.07270 | $ | 0.80 | 11 0.07270 | $ | 8.00 | 11 0.03049 | $ | 33.54 | 11 0.03049 | $ | 335.39
497-1593-1-ND | STMICROELECTRONICS (VA) LM393DT IC COMPARATOR LP DUAL 8-SOIC | 1 0.28100 | $ | 0.28 | 1 0.28100 | $ | 2.81 | 1 0.17530 | $ | 17.53 | 1 0.09228 | $ | 92.28
401-2002-1-ND | C&K (VA) JS202011SCQN SWITCH SLIDE DPDT 300MA 6V | 1 0.46300 | $ | 0.46 | 1 0.46300 | $ | 4.63 | 1 0.38580 | $ | 38.58 | 1 0.00000 | $ | -
507-1815-1-ND | BEL FUSE INC (VA) 0ZCK0100FF2E PTC RESET FUSE 6V 1A 0805 | 1 0.30400 | $ | 0.30 | 1 0.30400 | $ | 3.04 | 1 0.25270 | $ | 25.27 | 1 0.17784 | $ | 177.84
620-1519-1-ND | ALLEGRO MICROSYSTEMS, LLC (VA) A3214ELHLT-T MAGNETIC SWITCH OMNIPOLAR SOT23W | 1 | 1.01900 | $ | 1.02 | 1 1.01900 | $ | 10.19 | 1 0.68970 | $ | 68.97 | 1 0.51728 | $ | 517.28
478-8926-1-ND | AVX CORPORATION (VA) TAJR104K035RNJ CAP TANT 0.1UF 10% 35V 0805 | 1 0.56100 | $ | 0.56 | 1 0.56100 | $ | 5.61 | 1 0.38450 | $ | 38.45 | 1 0.30438 | $ | 304.38
338-1099-ND | CORNELL DUBILIER ELECTRONICS (CDE) MC08CA100D-F CAP MICA 10PF 0.5PF 100V 0805 | 1 | 1.87000 | $ | 1.87 | 1 1.87000 | $ | 18.70 | 1 1.42800 | $ 142.80 | 1 0.95200 | $ | 952.00
306-1428-1-ND | COTO TECHNOLOGY (VA) CT10-1025-G1 SWITCH REED SPST-NO 250MA 100V | 0 | 1.16600 | $ | - | 0 1.16600 | $ | - | 0 1.02560 | $ | - | 0 0.72261 | $ | -
P6.8ACT-ND | PANASONIC ELECTRONIC COMPONENTS (VA) ERJ-6GEYJ6R8V RES SMD 6.8 OHM 5% 1/8W 0805 | 6 0.02490 | $ | 0.15 | 6 0.02490 | $ | 1.49 | 6 0.01120 | $ | 6.72 | 6 0.00000 | $ | -
A126352CT-ND | TE CONNECTIVITY PASSIVE PRODUCT (VA) CRG0805F22R RES SMD 22 OHM 1% 1/8W 0805 | 2 0.02100 | $ | 0.04 | 2 0.02100 | $ | 0.42 | 2 0.00943 | $ | 1.89 | 2 0.00000 | $ | -
A129741CT-ND | TE CONNECTIVITY PASSIVE PRODUCT (VA) CRGCQ0805F220R CRGCQ 0805 220R 1% | 21 0.02060 | $ | 0.43 | 21 0.02060 | $ | 4.33 | 21 0.00927 | $ | 19.47 | 21 0.00927 | $ | 194.67
RNCP0805FTD10K0CT-ND STACKPOLE ELECTRONICS INC (VA) RNCP0805FTD10K0 RES 10K OHM 1% 1/4W 0805 | 3 0.07200 | $ | 0.22 | 3 0.07200 | $ | 2.16 | 3 0.02770 | $ | 8.31 | 3 0.01220 | $ | 36.60
A106057CT-ND | TE CONNECTIVITY PASSIVE PRODUCT (VA) CRG0805F1K5 RES SMD 1.5K OHM 1% 1/8W 0805 | 3 0.05200 | $ | 0.16 | 3 0.05200 | $ | 1.56 | 3 0.02100 | $ | 6.30 | 3 0.00819 | $ | 24.57
A126348CT-ND | TE CONNECTIVITY PASSIVE PRODUCT (VA) CRG0805F1K8 RES SMD 1.8K OHM 1% 1/8W 0805 | 2 0.05200 | $ | 0.10 | 2 0.05200 | $ | 1.04 | 2 0.02100 | $ | 4.20 | 2 0.00943 | $ | 18.86
311-4.70KCRCT-ND | YAGEO (VA)RC0805FR-074K7L RES SMD 4.7K OHM 1% 1/8W 0805 | 5 0.04200 | $ | 0.21 | 5 0.04200 | $ | 2.10 | 5 0.01700 | $ | 8.50 | 5 0.00000 | $ | -
BAT54AW-FDICT-ND | DIODES INCORPORATED (VA) BAT54AW-7-FDIODE ARRAY SCHOTTKY 30V SOT323 | 6 | 0.22100 | $ | 1.33 | 6 0.22100 | $ | 13.26 | 6 0.07726 | $ | 46.36 | 6 0.00000 | $ | -
BAT54CW-FDICT-ND | DIODES INCORPORATED (VA) BAT54CW-7-FDIODE ARRAY SCHOTTKY 30V SOT323 | 6 | 0.19400 | $ | 1.16 | 6 0.19400 | $ | 11.64 | 6 0.06762 | $ | 40.57 | 6 0.00000 | $ | -
408-1544-1-ND | SUSUMU (VA) KRL1220E-M-R010-F-T5 RES 0.01 OHM 1% 1/2W 0805 | 1 | 0.44800 | $ | 0.45 | 1 0.44800 | $ | 4.48 | 1 0.18820 | $ | 18.82 | 1 0.10384 | $ | 103.84
1276-6170-1-ND | SAMSUNG ELECTRO-MECHANICS AMERICA, INC (VA) RUT2012FR100CS RES 0.1 OHM 1% 1/4W 0805 | 0 0.25700 | $ | - | 0 0.25700 | $ | - | 0 0.10060 | $ | - | 0 0.04211 | $ | -
SAM1008-03-ND | SAMTEC INC (VA) BCS-103-L-D-TE CONN RCPT 6POS 0.1 GOLD PCB | 1 | 0.83400 | $ | 0.83 | 1 0.83400 | $ | 8.34 | 1 0.71910 | $ | 71.91 | 1 0.58838 | $ | 588.38
Other components
Stylus magnet tip | 1 $ | 0.05 $ | 0.05 | 1 $ | 0.05 $ | 0.50 | 1 $ | 0.05 $ | 5.00 | 1 $ | 0.05 $ | 50.00
Stylus (3D printed) | 1 | $ | 1.00 | $ | 1.00 | 1 $ | 0.75 $ | 7.50 | 1 $ | 0.50 $ | 50.00 | 1 $ | 0.25 $ | 250.00
Chassis (3D printed) | 1 | $ | 2.00 | $ | 2.00 | 1 $ | 1.75 $ | 17.50 | 1 $ | 1.25 $ 125.00 | 1 $ | 1.00 $ 1,000.00
Micro_LiPo_Charger | 1 | $ | 6.95 | $ | 6.95 | 1 $ | 6.95 $ | 69.50 | 1 $ | 5.56 $ 556.00 | 1 $ | 4.00 $ 4,000.00
Teensy-LC | 1 | $ 11.65 | $ | 11.65 | 1 $ 11.65 $ 116.50 | 1 $ 10.00 $ 1,000.00 | 1 $ | 8.00 $ 8,000.00
LED_Array | 1 | $ 26.14 | $ | 27.20 | 1 $ 26.14 $ 261.40 | 1 $ 16.00 $ 1,600.00 | 1 $ 16.00 $ 16,000.00
OLED_DISPLAY | 1 | $ | 5.00 | $ | 5.00 | 1 $ | 5.00 $ | 50.00 | 1 $ | 4.00 $ 400.00 | 1 $ | 3.00 $ 3,000.00
Cores | 64 $ | 0.01 $ | 0.32 | 64 $ | 0.01 $ | 3.20 | 64 $ | 0.01 $ | 34.75 | 64 $ 0.0018 $ | 112.00
Magnet wire (inches) | 70 $ 0.0006 $ | 0.04 | 70 $ 0.0006 $ | 0.42 | 70 $ 0.0006 $ | 4.17 | 70 $ 0.0006 $ | 41.67
PCB | 1 $ | 2.00 $ | 2.00 | 1 $ | 2.00 $ | 20.00 | 1 $ | 1.00 $ 100.00 | 1 $ | 0.77 $ | 770.00
TOTAL BATCH COST -> | $ | 67.33 | $ 657.66 | $ 4,503.94 | $ 36,878.16

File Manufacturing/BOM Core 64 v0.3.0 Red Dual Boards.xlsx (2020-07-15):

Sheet: Concept Estimate
ESTIMATED V0.3 DUAL BOARD COSTS MARCH 17, 2020 BEFORE DESIGN WORK
Same base component spec as V0.1 and V0.2,
Removed lipo charger, added battery pack
No case
 |  |  |  | Component Cost Per unit - > |  | $87.71 |  |  | $83.26 |  |  | $59.87 |  |  | $51.89
 |  |  |  | Quantity of Assemblies - > | 1 |  |  | 10 |  |  | 100 |  |  | 1000
LOGIC BOARD | Jellybean components from Digi-key |  |  |  |  |  | Extended |  |  | Extended |  |  | Extended |  |  | Extended
 | Digi-Key Part Number | Manufacturer | Manufacturer Part Number | Description | Quantity | Price |  | Quantity | Price |  | Quantity | Price |  | Quantity | Price
 | MMBT4403LT1GOSCT-ND | ON SEMICONDUCTOR (VA) | MMBT4403LT1G | TRANS PNP 40V 0.6A SOT23 | 10 | 0.07350 | $0.73 | 10 | 0.07350 | $7.35 | 10 | 0.03084 | $30.84 | 10 | 0.03084 | $308.40
 | MMBT4401LT1GOSCT-ND | ON SEMICONDUCTOR (VA) | MMBT4401LT1G | TRANS NPN 40V 0.6A SOT23 | 11 | 0.07270 | $0.80 | 11 | 0.07270 | $8.00 | 11 | 0.03049 | $33.54 | 11 | 0.03049 | $335.39
 | 497-1593-1-ND | STMICROELECTRONICS (VA) | LM393DT | IC COMPARATOR LP DUAL 8-SOIC | 1 | 0.28100 | $0.28 | 1 | 0.28100 | $2.81 | 1 | 0.17530 | $17.53 | 1 | 0.09228 | $92.28
 | 401-2002-1-ND | C&K (VA) | JS202011SCQN | SWITCH SLIDE DPDT 300MA 6V | 1 | 0.46300 | $0.46 | 1 | 0.46300 | $4.63 | 1 | 0.38580 | $38.58 | 1 | 0.00000 | $0.00
 | 507-1815-1-ND | BEL FUSE INC (VA) | 0ZCK0100FF2E | PTC RESET FUSE 6V 1A 0805 | 1 | 0.30400 | $0.30 | 1 | 0.30400 | $3.04 | 1 | 0.25270 | $25.27 | 1 | 0.17784 | $177.84
 | 620-1519-1-ND | ALLEGRO MICROSYSTEMS, LLC (VA) | A3214ELHLT-T | MAGNETIC SWITCH OMNIPOLAR SOT23W | 4 | 1.01900 | $4.08 | 4 | 1.01900 | $40.76 | 4 | 0.68970 | $275.88 | 4 | 0.51728 | $2069.12
 | 478-8926-1-ND | AVX CORPORATION (VA) | TAJR104K035RNJ | CAP TANT 0.1UF 10% 35V 0805 | 1 | 0.56100 | $0.56 | 1 | 0.56100 | $5.61 | 1 | 0.38450 | $38.45 | 1 | 0.30438 | $304.38
 | 338-1099-ND | CORNELL DUBILIER ELECTRONICS (CDE) | MC08CA100D-F | CAP MICA 10PF 0.5PF 100V 0805 | 1 | 1.87000 | $1.87 | 1 | 1.87000 | $18.70 | 1 | 1.42800 | $142.80 | 1 | 0.95200 | $952.00
 | 306-1428-1-ND | COTO TECHNOLOGY (VA) | CT10-1025-G1 | SWITCH REED SPST-NO 250MA 100V | 0 | 1.16600 | $0.00 | 0 | 1.16600 | $0.00 | 0 | 1.02560 | $0.00 | 0 | 0.72261 | $0.00
 | P6.8ACT-ND | PANASONIC ELECTRONIC COMPONENTS (VA) | ERJ-6GEYJ6R8V | RES SMD 6.8 OHM 5% 1/8W 0805 | 6 | 0.02490 | $0.15 | 6 | 0.02490 | $1.49 | 6 | 0.01120 | $6.72 | 6 | 0.00000 | $0.00
 | A126352CT-ND | TE CONNECTIVITY PASSIVE PRODUCT (VA) | CRG0805F22R | RES SMD 22 OHM 1% 1/8W 0805 | 2 | 0.02100 | $0.04 | 2 | 0.02100 | $0.42 | 2 | 0.00943 | $1.89 | 2 | 0.00000 | $0.00
 | A129741CT-ND | TE CONNECTIVITY PASSIVE PRODUCT (VA) | CRGCQ0805F220R | CRGCQ 0805 220R 1% | 21 | 0.02060 | $0.43 | 21 | 0.02060 | $4.33 | 21 | 0.00927 | $19.47 | 21 | 0.00927 | $194.67
 | RNCP0805FTD10K0CT-ND | STACKPOLE ELECTRONICS INC (VA) | RNCP0805FTD10K0 | RES 10K OHM 1% 1/4W 0805 | 3 | 0.07200 | $0.22 | 3 | 0.07200 | $2.16 | 3 | 0.02770 | $8.31 | 3 | 0.01220 | $36.60
 | A106057CT-ND | TE CONNECTIVITY PASSIVE PRODUCT (VA) | CRG0805F1K5 | RES SMD 1.5K OHM 1% 1/8W 0805 | 3 | 0.05200 | $0.16 | 3 | 0.05200 | $1.56 | 3 | 0.02100 | $6.30 | 3 | 0.00819 | $24.57
 | A126348CT-ND | TE CONNECTIVITY PASSIVE PRODUCT (VA) | CRG0805F1K8 | RES SMD 1.8K OHM 1% 1/8W 0805 | 2 | 0.05200 | $0.10 | 2 | 0.05200 | $1.04 | 2 | 0.02100 | $4.20 | 2 | 0.00943 | $18.86
 | 311-4.70KCRCT-ND | YAGEO (VA) | RC0805FR-074K7L | RES SMD 4.7K OHM 1% 1/8W 0805 | 5 | 0.04200 | $0.21 | 5 | 0.04200 | $2.10 | 5 | 0.01700 | $8.50 | 5 | 0.00000 | $0.00
 | BAT54AW-FDICT-ND | DIODES INCORPORATED (VA) | BAT54AW-7-F | DIODE ARRAY SCHOTTKY 30V SOT323 | 6 | 0.22100 | $1.33 | 6 | 0.22100 | $13.26 | 6 | 0.07726 | $46.36 | 6 | 0.00000 | $0.00
 | BAT54CW-FDICT-ND | DIODES INCORPORATED (VA) | BAT54CW-7-F | DIODE ARRAY SCHOTTKY 30V SOT323 | 6 | 0.19400 | $1.16 | 6 | 0.19400 | $11.64 | 6 | 0.06762 | $40.57 | 6 | 0.00000 | $0.00
 | 408-1544-1-ND | SUSUMU (VA) | KRL1220E-M-R010-F-T5 | RES 0.01 OHM 1% 1/2W 0805 | 1 | 0.44800 | $0.45 | 1 | 0.44800 | $4.48 | 1 | 0.18820 | $18.82 | 1 | 0.10384 | $103.84
 | 1276-6170-1-ND | SAMSUNG ELECTRO-MECHANICS AMERICA, INC (VA) | RUT2012FR100CS | RES 0.1 OHM 1% 1/4W 0805 | 0 | 0.25700 | $0.00 | 0 | 0.25700 | $0.00 | 0 | 0.10060 | $0.00 | 0 | 0.04211 | $0.00
 | SAM1008-03-ND | SAMTEC INC (VA) | BCS-103-L-D-TE | CONN RCPT 6POS 0.1 GOLD PCB | 1 | 0.83400 | $0.83 | 1 | 0.83400 | $8.34 | 1 | 0.71910 | $71.91 | 1 | 0.58838 | $588.38
 | Other components
 |  |  |  | LED Diffuser | 1 | $0.05 | $0.05 | 1 | $0.05 | $0.50 | 1 | $0.05 | $5.00 | 1 | $0.05 | $50.00
 |  |  |  | Lanyard, double ended | 1 | $1.00 | $1.00 | 1 | $1.00 | $10.00 | 1 | $0.75 | $75.00 | 1 | $0.50 | $500.00
 |  |  |  | Stylus magnet tip | 1 | $0.05 | $0.05 | 1 | $0.05 | $0.50 | 1 | $0.05 | $5.00 | 1 | $0.05 | $50.00
 |  |  |  | Stylus (3D printed) | 1 | $1.00 | $1.00 | 1 | $0.75 | $7.50 | 1 | $0.50 | $50.00 | 1 | $0.25 | $250.00
 |  |  |  | NO CASE
 | 36-2478CN-ND | Keystone |  | Battery Box | 1 | $2.41 | $2.41 | 1 | $2.41 | $24.10 | 1 | $2.14 | $214.00 | 1 | $1.27 | $1270.00
 |  |  |  | Teensy-LC | 1 | $11.65 | $11.65 | 1 | $11.65 | $116.50 | 1 | $10.00 | $1000.00 | 1 | $8.00 | $8000.00
 |  |  |  | Teensy-LC headers | 2 | $2.08 | $4.16 | 2 | $2.08 | $41.60 | 2 | $1.50 | $300.00 | 2 | $1.50 | $3000.00
 |  |  |  | Teensy-LC sockets | 2 | $3.65 | $7.30 | 2 | $2.08 | $41.60 | 2 | $2.58 | $516.00 | 2 | $2.58 | $5160.00
 |  |  |  | LED_Array | 1 | $26.14 | $27.20 | 1 | $26.14 | $261.40 | 1 | $16.00 | $1600.00 | 1 | $16.00 | $16000.00
 |  |  |  | OLED_DISPLAY | 1 | $5.00 | $5.00 | 1 | $5.00 | $50.00 | 1 | $4.00 | $400.00 | 1 | $3.00 | $3000.00
 |  |  |  | Fem. Connectors to Core Board | 2 | $2.55 | $5.10 | 2 | $2.55 | $51.00 | 2 | $1.85 | $370.00 | 2 | $1.8500 | $3700.00
 |  |  |  | Male Connectors from Core board | 2 | $2.08 | $4.16 | 2 | $2.08 | $41.60 | 2 | $1.85 | $370.00 | 2 | $1.8500 | $3700.00
 |  | JLCPCB |  | PCB | 1 | $2.00 | $2.00 | 1 | $2.00 | $20.00 | 1 | $1.00 | $100.00 | 1 | $0.77 | $770.00
 |  |  |  |  | SUBTOTAL |  | $85.25 |  |  | $808.02 |  |  | $5840.93 |  |  | $50656.33
CORE BOARD |  |  |  |  | Cost Each |  | $85.25 |  |  | $80.80 |  |  | $58.41 |  |  | $50.66
 |  |  |  | Cores | 64 | $0.01 | $0.32 | 64 | $0.01 | $3.20 | 64 | $0.01 | $32.00 | 64 | $0.01 | $320.00
 |  |  |  | Magnet wire (inches) | 70 | $0.0006 | $0.04 | 70 | $0.0006 | $0.42 | 70 | $0.0006 | $4.17 | 70 | $0.0006 | $41.67
 |  | JLCPCB |  | PCB | 1 | $2.00 | $2.00 | 1 | $2.00 | $20.00 | 1 | $1.00 | $100.00 | 1 | $0.77 | $770.00
 |  |  |  | Magnetic Hall Switch included in main kit
 |  |  |  | Bag | 1 | $0.05 | $0.05 | 1 | $0.05 | $0.50 | 1 | $0.05 | $5.00 | 1 | $0.05 | $50.00
 |  |  |  | Sticker | 1 | $0.05 | $0.05 | 1 | $0.05 | $0.50 | 1 | $0.05 | $5.00 | 1 | $0.05 | $50.00
 |  |  |  |  | SUBTOTAL |  | $2.46 |  |  | $24.62 |  |  | $146.17 |  |  | $1231.67
 |  |  |  |  | Cost Each |  | $2.46 |  |  | $2.46 |  |  | $1.46 |  |  | $1.23
 |  |  |  | TOTAL BATCH COST -> |  |  | $87.71 |  |  | $832.63 |  |  | $5987.10 |  |  | $51888.00
 |  |  |  |  | Cost Each |  | $87.71 |  |  | $83.26 |  |  | $59.87 |  |  | $51.89

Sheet: Core Board V0.3
Raw BOM from PCBNEW (since EESCHEMA lost it's BOM scripts)
Core Board V0.3
2020-05-19 | (PCB fabrication release day!) |  |  |  |  |  |  |  |  |  |  |  | PROTOTYPE MINIMUM QUANTITIES
 |  |  |  |  |  |  |  |  | ORDERED | RECEIVED
 | ASSEMBLY COMPLETED | COMPONENT VALIDATED (GOOD OR MAKE NOTES IF IT'S NOT) | VALIDATED |  | VALIDATED |  |  | Before V0.3 first proto assemble | To complete 1st build | After order I have | After V0.3 first proto assemble | To build 4 more (- is excess) | QUANTITY PURCHASE BREAK | COST AT BREAK | COST PER UNIT
Id | Designator | Package | Quantity | Units | Value | Supplier and ref | Optional? | Qty On Hand May 20, 2020 | Need to buy | Have | Qty on hand | Need to buy | QTY | $ | $/UNIT
4 | C1,C3,C5,C7,C9,C10,C11,C12 | C_0805_2012Metric | 8 | ea | 0.1uF | 732-8045-1-ND | n | 2 | 6 | 8 | 0 | 32 |  |  | #DIV/0!
5 | C2,C4,C6,C8 | C_0805_2012Metric | 4 | ea | 10pF | ‎732-7814-1-ND‎ | n | 0 | 10 | 10 | 6 | 10 |  |  | #DIV/0!
103 | CM1 - cores | Cores | 70 | ea | Core 1mm | 1000+ DDR RAW MAGNETIC FERRITE CORES 5221.3-2113.35 FOR CORE MEMORY BOARD (ebay 302773538905 SOLD BY lci_electronics ) | n | 930 | 0 | 930 | 860 | -580 |  |  | #DIV/0!
102 | CM1 - wire | Core Grid wire | 0.8 | m | Magnetic wire, copper enamel color. Grid 16x100mm + sense 750mm = 2350 mm (92 in.) | Enameled Wire 32AWG 120g, 0.2mm, 430m (1400ft) Enameled copper coil, Magnet Wire (ebay 161981317634 SOLD BY elecmall ) | n | 427 | 0 | 427 | 426.2 | -423 | 430 |  | $0.000
103 | CM1 - wire | Core Grid wire | 0.8 | m | Magnetic wire, red enamel color. | US 100M Magnet Wire 0.2mm QA Enameled Copper Wire Magnetic Coil Winding Wire, (ebay 202976367512 supergame-us) | n | 0 | 100 | 100 | 99.2 | -96 | 100 | $6.49 | $0.065
103 | CM1 - wire | Core Sense wire | 0.75 | m | Magnetic wire, green enamel color. | Magnet Wire 32 Gauge AWG Enameled Copper 2450 Feet Coil Winding 155°C Green (ebay 182012326389 tech-fixx) | n | 0 | 746.7235599 | 746.7235599 | 745.9735599 | -742.9735599 | 747 | $17.78 | $0.024
19 | J1,J2 | PinHeader_1x16_P2.54mm_Vertical_SMD_and_TH_Pin1Right | 2 | ea | TSM-116-03-T-SV |  | n | 0 | 2 | 2 | 0 | 8 |  |  | #DIV/0!
1 | J3 | LED_Matrix_Header_3pin_0.9_holes | 1 | ea | LED ARRAY 3 pin Header |  | y | 1 | 0 | 1 | 0 | 4 |  |  | #DIV/0!
101 | PCB | Blank board | 1 | ea | PCB | JLCPCB.com | n | 5 | 0 | 5 | 4 | 0 |  |  | #DIV/0!
6 | R1,R2,R3,R4 | R_0805_2012Metric | 4 | ea | 4K7 |  | n | 4 | 0 | 4 | 0 | 16 |  |  | #DIV/0!
11 | U1 | SOT-23_Handsoldering | 1 | ea | A3214ELHL-T |  | n | 1 | 0 | 1 | 0 | 4 |  |  | #DIV/0!
12 | U2, U4 | SOT-23_Handsoldering | 2 | ea | DRV5032FADBZR |  | n | 2 | 0 | 2 | 0 | 8 |  |  | #DIV/0!
14 | U3 | SOT-23_Handsoldering | 1 | ea | DRV5032DUDBZR |  | n | 1 | 0 | 1 | 0 | 4 |  |  | #DIV/0!
7 | U5 | SOT-23-5 | 1 | ea | SI7210-B-01 |  | y | 1 | 0 | 1 | 0 | 4 |  |  | #DIV/0!
8 | U6 | SOT-23-5 | 1 | ea | SI7210-B-02 |  | y | 1 | 0 | 1 | 0 | 4 |  |  | #DIV/0!
9 | U7 | SOT-23-5 | 1 | ea | SI7210-B-03 |  | y | 1 | 0 | 1 | 0 | 4 |  |  | #DIV/0!
10 | U8 | SOT-23-5 | 1 | ea | SI7210-B-04 |  | y | 1 | 0 | 1 | 0 | 4 |  |  | #DIV/0!
2 | X1 | Badgelife-SAOv169-BADGE-2x3 | 1 | ea | SFH11-NBPC-D03-ST-BK |  | y | 1 | 0 | 1 | 0 | 4 |  |  | #DIV/0!
15
3
13
16
17
18
20

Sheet: Logic Board V0.3
Source: | /Users/ageppert/Dropbox/Electronics/Core 64 Interactive Badge/Core-64-Interactive-Core-Memory-Badge/Electronic Design/Interactive Core Memory Badge (Logic) v0.3/Interactive Core Memory Badge (Logic) Main v0.3.sch
Date: | Thursday, May 21, 2020 at 07:06:58 AM
Tool: | Eeschema (5.1.2-1)-1
Generator: | /private/var/folders/kh/1q_kd4hn7cq821df7xpmdhbw0000gn/T/AppTranslocation/C0C9017D-E73E-48F9-99F9-451879B2E2B1/d/kicad.app/Contents/SharedSupport/plugins/bom_csv_grouped_by_value.py
Component Count: | 122
Core Logic Board V0.3
 |  |  |  |  |  |  |  |  |  |  |  |  | PROTOTYPE MINIMUM QUANTITIES
Collated Components: |  |  |  |  |  |  |  |  | IN CART | RECEIVED
 | ASSEMBLY COMPLETED | COMPONENT VALIDATED (GOOD OR MAKE NOTES IF IT'S NOT) | VALIDATED |  | VALIDATED |  |  | Before V0.3 first proto assemble | To complete 1st build | After order I have | After V0.3 first proto assemble | To build 4 more (- is excess) | QUANTITY PURCHASE BREAK | COST AT BREAK | COST PER UNIT
ID | Designator | Footprint | Qty | Units | Value | Supplier and ref | OPTIONAL | Qty On Hand May 20, 2020 | Need to buy | Have | Qty on hand | Need to buy | QTY | $ | $/UNIT | LibPart | Datasheet | Category | DK_Datasheet_Link | DK_Detail_Page | Description | Family | Height | MPN | Manufacturer | Manufacturer_Name | Manufacturer_Part_Number | Status
1 | C1, C8 | Capacitor_SMD:CP_Elec_10x10 | 2 | ea | 1000uF | 493-2254-1-ND | n | 0 | 2 | 2 | 0 | 8 |  |  | #DIV/0! | Device:CP1_Small | ~
2 | C2, C4, C5, C6, C7, C9, C11 | Capacitor_SMD:C_0805_2012Metric | 7 | ea | 0.1uF | 732-8045-1-ND | n | 0 | 7 | 7 | 0 | 28 |  |  | #DIV/0! | Device:CP1_Small | ~
3 | C3, C10 | Capacitor_SMD:C_0805_2012Metric | 2 | ea | 10uF | 1276-6455-1-ND | n | 0 | 10 | 10 | 8 | 0 |  |  | #DIV/0! | Device:CP1_Small | ~
4 | D1 | Diode_SMD:D_SOD-123F | 1 | ea | MBR120 CHANGE?? S1M-13-F | MBR120VLSFT1GOSCT-ND | n | 1 | 0 | 1 | 0 | 4 | 430 |  | $0.000 | Diode:MBR0520 | https://www.digikey.com/product-detail/en/on-semiconductor/MBR120VLSFT1G/MBR120VLSFT1GOSCT-ND/893874
5 | D2, D4, D6, D8, D10, D12 | Package_TO_SOT_SMD:SOT-323_SC-70 | 6 | ea | BAT54AW | BAT54AW-FDICT-ND | n | 4 | 2 | 6 | 0 | 24 | 100 |  | $0.000 | Diode:BAT54AW | https://assets.nexperia.com/documents/data-sheet/BAT54W_SER.pdf
6 | D3, D5, D7, D9, D11, D13 | Package_TO_SOT_SMD:SOT-323_SC-70 | 6 | ea | BAT54CW | BAT54CW-FDICT-ND | n | 4 | 2 | 6 | 0 | 24 | 747 |  | $0.000 | Diode:BAT54CW | https://assets.nexperia.com/documents/data-sheet/BAT54W_SER.pdf
7 | F1 | Fuse:Fuse_0805_2012Metric | 1 | ea | Polyfuse | 507-1815-1-ND | n | 1 | 0 | 1 | 0 | 4 |  |  | #DIV/0! | Device:Polyfuse | ~
8 |  |  |  |  |  |  |  |  |  |  |  |  |  |  | #DIV/0! |  | ~
9 |  |  |  |  |  |  |  |  |  |  |  |  |  |  | #DIV/0! |  | ~
10 | J1 | JST_BM03B-PASS-1-TFT:BM03BPASS1TFTLFSN | 1 | ea | BM03B-PASS-1-TFT__LF__SN_ | 455-2638-1-ND | n | 1 | 0 | 1 | 0 | 4 |  |  | #DIV/0! | BM03B-PASS-1-TFT__LF__SN_:BM03B-PASS-1-TFT__LF__SN_ | http://www.jst-mfg.com/product/pdf/eng/ePA-F.pdf |  |  |  | Conn Shrouded Header HDR 3 POS 2mm Solder ST SMD T/R |  | 8.8 |  |  | JST (JAPAN SOLDERLESS TERMINALS) | BM03B-PASS-1-TFT (LF)(SN)
11 | J2 | Connector_PinSocket_2.54mm:PinSocket_1x02_P2.54mm_Vertical_SMD_Pin1Left | 1 | ea | Conn_01x02_Male | cut a header | y | 1 | 0 | 1 | 0 | 4 |  |  | #DIV/0! | Connector:Conn_01x02_Male | ~
12 | J3, J5, J8, X2 | Connector_PinSocket_2.54mm:PinSocket_1x08_P2.54mm_Vertical | 4 | ea | Conn_01x08_Female | cut a socket | y | 4 | 0 | 4 | 0 | 16 |  |  | #DIV/0! | Connector:Conn_01x08_Female | ~
13 | J4 | Connector_PinHeader_2.54mm:PinHeader_2x06_P2.54mm_Vertical_SMD_and_TH | 1 | ea | TSM-106-03-T-DV | ‎SAM12249-ND‎ | y | 0 | 1 | 1 | 0 | 4 |  |  | #DIV/0! | Connector_Generic:Conn_02x06_Odd_Even | ~
14 | J6, J7 | Connector_PinHeader_2.54mm:PinHeader_1x16_P2.54mm_Vertical_SMD_and_TH_Pin1Left | 2 | ea | SSW-116-22-F-S-VS | TSM-116-01-T-SV-P-ND | n | 2 | 0 | 2 | 0 | 8 |  |  | #DIV/0! | Connector:Conn_01x16_Female | ~
15 |  |  |  |  |  |  |  |  |  |  |  |  |  |  | #DIV/0!
16 |  |  |  |  |  |  |  |  |  |  |  |  |  |  | #DIV/0!
17 |  |  |  |  |  |  |  |  |  |  |  |  |  |  | #DIV/0!
18 |  |  |  |  |  |  |  |  |  |  |  |  |  |  | #DIV/0!
19
20
21 | Q1 | Digikey:SOT-23-3 | 1 | ea | IRLML6344TRPBF | IRLML6344TRPBFCT-ND | n | 1 | 0 | 1 | 0 | 4 |  |  |  | Transistor_FET:IRLML2060 | https://www.digikey.com/product-detail/en/infineon-technologies/IRLML6344TRPBF/IRLML6344TRPBFCT-ND/2538168
22 | Q2, Q5, Q7, Q9, Q11, Q13, Q15, Q17, Q19, Q21 | Digikey:SOT-23-3 | 10 | ea | MMBT4403LT1G | MMBT4403LT1GOSCT-ND | n | 2 | 10 | 12 | 2 | 38 |  |  |  | Digikey-Transistors:MMBT4403LT1G | http://www.onsemi.com/pub/Collateral/MMBT4403LT1-D.PDF | Discrete Semiconductor Products | http://www.onsemi.com/pub/Collateral/MMBT4403LT1-D.PDF | /product-detail/en/on-semiconductor/MMBT4403LT1G/MMBT4403LT1GOSCT-ND/1139820 | TRANS PNP 40V 0.6A SOT23 | Transistors - Bipolar (BJT) - Single |  | MMBT4403LT1G | ON Semiconductor |  |  | Active
23 | Q3, Q4, Q6, Q8, Q10, Q12, Q14, Q16, Q18, Q20, Q22 | Digikey:SOT-23-3 | 11 | ea | MMBT4401LT1G | MMBT4401LT1GOSCT-ND | n | 2 | 10 | 12 | 1 | 43 |  |  |  | Digikey-Transistors:MMBT4401LT1G | http://www.onsemi.com/pub/Collateral/MMBT4401LT1-D.PDF | Discrete Semiconductor Products | http://www.onsemi.com/pub/Collateral/MMBT4401LT1-D.PDF | /product-detail/en/on-semiconductor/MMBT4401LT1G/MMBT4401LT1GOSCT-ND/1139819 | TRANS NPN 40V 0.6A SOT23 | Transistors - Bipolar (BJT) - Single |  | MMBT4401LT1G | ON Semiconductor |  |  | Active
24 | R1 | Resistor_SMD:R_0805_2012Metric | 1 | ea | 0.1 |  | n | 1 | 0 | 1 | 0 | 4 |  |  |  | Device:R | ~
25 | R2, R3 | Resistor_SMD:R_0805_2012Metric | 2 | ea | 4K7 | 311-4.70KCRCT-ND | n | 0 | 10 | 10 | 8 | 0 |  |  |  | Device:R | ~
26 | R5 | Resistor_SMD:R_0805_2012Metric | 1 | ea | 300 | SUB 470 OHM ??? | n | 0 |  | 0 | -1 | 5 |  |  |  | Device:R | ~
27 | R8, R9, R10, R11, R12, R14, R15, R17, R18, R22, R23, R25, R26, R27, R28, R29, R30, R32, R33, R34, R35 | Resistor_SMD:R_0805_2012Metric | 21 | ea | 470 | RMCF0805JG470RCT-ND | n | 11 | 20 | 31 | 10 | 74 |  |  |  | Device:R | ~
28 | R13, R19, R20, R21, R24, R31 | Resistor_SMD:R_0805_2012Metric | 6 | ea | 6R8 | P6.8ACT-ND | n | 4 | 10 | 14 | 8 | 16 |  |  |  | Device:R | ~
29 | R36, R39, R42 | Resistor_SMD:R_0805_2012Metric | 3 | ea | 1K5 | A106057CT-ND | n | 8 | 0 | 8 | 5 | 7 |  |  |  | Device:R | ~
30 | R37, R40 | Resistor_SMD:R_0805_2012Metric | 2 | ea | 1K8 | A126348CT-ND | n | 8 | 0 | 8 | 6 | 2 |  |  |  | Device:R | ~
31 | R38, R41 | Resistor_SMD:R_0805_2012Metric | 2 | ea | 11 | 311-11.0CRCT-ND | n | 0 | 10 | 10 | 8 | 0 |  |  |  | Device:R | ~
32 | R43, R44, R45, R46, R51, R52 | Resistor_SMD:R_0805_2012Metric | 6 | ea | 10k | RNCP0805FTD10K0CT-ND | n | 6 | 0 | 6 | 0 | 24 |  |  |  | Device:R | ~
33 | SW1 | Button_Switch_SMD:SW_SPDT_CK-JS102011SAQN | 1 | ea | JS102011SAQN | 401-1999-1-ND | n | 1 | 0 | 1 | 0 | 4 |  |  |  | Switch:SW_SPDT | ~
34 | U1 | Package_TO_SOT_SMD:SOT-223-3_TabPin2 | 1 | ea | LD1117S33TR_SOT223 | 497-1241-1-ND | n | 1 | 0 | 1 | 0 | 4 |  |  |  | Regulator_Linear:LD1117S33TR_SOT223 | http://www.st.com/st-web-ui/static/active/en/resource/technical/document/datasheet/CD00000544.pdf
35 | U2 | Teensy:Teensy30_31_32_LC_SMD_SOCKETS | 1 | ea | Teensy-LC |  | n | 1 | 0 | 1 | 0 | 4 |  |  |  | Teensy:Teensy-LC
36 | U3 | Package_SO:SOIC-8_3.9x4.9mm_P1.27mm | 1 | ea | M24C01-RMN | 497-8556-ND | n | 0 | 1 | 1 | 0 | 4 |  |  |  | Memory_EEPROM:M24C01-RMN | http://www.st.com/content/ccc/resource/technical/document/datasheet/b0/d8/50/40/5a/85/49/6f/DM00071904.pdf/files/DM00071904.pdf/jcr:content/translations/en.DM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
37 | U4 | Package_TO_SOT_SMD:SOT-23-5 | 1 | ea | SN74LV1T125DBVR | 296-37172-1-ND | n | 1 | 0 | 1 | 0 | 4 |  |  |  | Logic_LevelTranslator:SN74LV1T125DBVR | http://www.ti.com/lit/ds/symlink/sn74lv1t125.pdf
38 | U5, U6 | Package_SO:SOIC-28W_7.5x17.9mm_P1.27mm | 2 | ea | MCP23017_SO | MCP23017T-E/SOCT-ND | n | 2 | 0 | 2 | 0 | 8 |  |  |  | Interface_Expansion:MCP23017_SO | http://ww1.microchip.com/downloads/en/DeviceDoc/20001952C.pdf
39 | U7 | Digikey:SOIC-8_W3.9mm | 1 | ea | LM393 | 497-1593-1-ND | n | 1 | 0 | 1 | 0 | 4 |  |  |  | Comparator:LM393 | http://www.ti.com/lit/ds/symlink/lm393-n.pdf
40 | U8 | Package_SO:SOIC-14_3.9x8.7mm_P1.27mm | 1 | ea | 74HC02 | 296-1188-1-ND | n | 1 | 0 | 1 | 0 | 4 |  |  |  | 74xx:74HC02 | http://www.ti.com/lit/gpn/sn74hc02
41 | X1 | Connector_PinSocket_2.54mm:PinSocket_1x04_P2.54mm_Vertical_SMD_and_TH_Pin1Left | 1 | ea | SSW-104-22-L-S-VS | 612-SSW-104-22-L-S-VS-ND | y | 1 | 0 | 1 | 0 | 4 |  |  |  | Connector:Conn_01x04_Female | ~
42 | X3 | Connector_JST:JST_SH_SM04B-SRSS-TB_1x04-1MP_P1.00mm_Horizontal | 1 | ea | Conn_01x04_Male | 455-1804-1-ND | y | 1 | 0 | 1 | 0 | 4 |  |  |  | Connector:Conn_01x04_Male | ~
43 | X4 | badgelife_sao_v169bis:Badgelife-SAOv169-BADGE-2x3 | 1 | ea | SAO_conn_SFH11-NBPC-D03-ST-BK |  | y | 1 | 0 | 1 | 0 | 4 |  |  |  | badgelife_shitty_addon_v169bis:SAO_conn_SFH11-NBPC-D03-ST-BK
101 | Not labeled - for Adafruit MicroSD Breakout |  | 1 |  | ADAFRUIT MICROSD CARD BREAKOUT 5V OR 3V | 1528-1462-ND | y | 0 | 1 | 1 | 0 | 4
102 | C1, C8 | Capacitor_SMD:CP_Elec_10x10 | 2 | ea | 470uF | ‎565-4318-1-ND‎ | y | 0 | 2 | 2 | 0 | 8
103 | not labeled - for Teensy sockets | Connector_PinHeader_2.54mm:PinHeader_1x16_P2.54mm_Vertical_SMD_and_TH_Pin1Left | 2 | ea | SSW-116-22-F-S-VS | TSM-116-01-T-SV-P-ND | n | 2 | 0 | 2 | 0 | 8 |  |  |  | Connector:Conn_01x16_Female | ~
104 | not labeled - for Teensy sockets | CONN RCPT 12POS 0.1 GOLD SMD | 1 | ea | SSM-106-LM-DV | SSM-106-LM-DV-ND | n | 1 | 0 | 1 | 0 | 4
105 | PCB |  | 1 | ea |  | JLCPCB.COM | n | 5 | 0 | 5 | 4 | 0
106 | not labeled | Lanyard, or alligator clip test leads. 26-28" OAL w/clips | 1 | ea
107 | Solder paste |  |  |  |  |  |  |  | 0 | 0 | 0 | 0
108 | Solder paste, Syringe |  |  |  |  |  |  |  | 0 | 0 | 0 | 0
109 | Solder paste, Syringe Tip |  |  |  |  |  |  |  | 0 | 0 | 0 | 0

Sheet: Middle Layers
Raw BOM from PCBNEW (since EESCHEMA lost it's BOM scripts)
Core Board V0.3
2020-05-19 | (PCB fabrication release day!) |  |  |  |  |  |  |  |  |  |  |  | PROTOTYPE MINIMUM QUANTITIES
 |  |  |  |  |  |  |  |  | ORDERED | RECEIVED
 | ASSEMBLY COMPLETED | COMPONENT VALIDATED (GOOD OR MAKE NOTES IF IT'S NOT) | VALIDATED |  | VALIDATED |  |  | Before V0.3 first proto assemble | To complete 1st build | After order I have | After V0.3 first proto assemble | To build 4 more (- is excess) | QUANTITY PURCHASE BREAK | COST AT BREAK | COST PER UNIT
Id | Designator | Package | Quantity | Units | Value | Supplier and ref | Optional? | Qty On Hand May 20, 2020 | Need to buy | Have | Qty on hand | Need to buy | QTY | $ | $/UNIT
301 | not labeled | 4xAAA Battery Holder | 1 | ea |  | 36-2482CN-ND | n | 1 | 0 | 1 | 0 | 4
302 | not labeled | Stylus | 1 | ea |  |  | n
303 | not labeled | Stylus magnet sphere | 1 | ea |  |  | n
~~304~~ | ~~not labeled~~ | ~~Stylus plug~~ | ~~1~~ | ~~ea~~ |  |  | ~~n~~
305 | not labeled | 3D printed LED Array holder | 1 | ea |  |  | n
~~306~~ | ~~not labeled~~ | ~~stylus rention magnet~~ | ~~1~~ | ~~ea~~ |  |  | ~~n~~
~~307~~ | ~~not labeled~~ | ~~stylus friction o-ring~~ | ~~1~~ | ~~ea~~ |  |  | ~~n~~
308 | not labeled | LED Array | 1 | ea |  | Pimoroni Unicorn Hat | n | 4 | 0 | 4 | 3 | 1
309 | not labeled | Diffuser layer | 1 | ea | user cuts to size 85x85mm |  | n
310 | not labeled | Screen protector layer | 1 | ea | user cuts to size 85x85mm |  | n
311 | not labeled | Glue magnet to stylus |  |  | user glues it |  | n
312 | not labeled | AAA batteries | 1 | ea | user installs |  | n

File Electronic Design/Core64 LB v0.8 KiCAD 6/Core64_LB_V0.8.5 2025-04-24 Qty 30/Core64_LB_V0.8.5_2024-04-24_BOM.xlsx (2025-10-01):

Comment | Designator | Footprint | LCSC Part Number
0.1uF | C1,C2,C3,C4, C16, C17, C19 | Capacitor_SMD:C_0805_2012Metric | C28233
1uF | C5, C6, C10, C12 | Capacitor_SMD:C_0805_2012Metric | C28323
220uF | C7, C8, C9, C13, C14, C15 | Capacitor_SMD:C_1206_3216Metric | C412252
0.01uF | C11 | Capacitor_SMD:C_0805_2012Metric | C1710
10uF | C18 | Capacitor_SMD:C_0805_2012Metric | C17024
BAT54AW | D2, D4, D6, D8, D10, D12 | Package_TO_SOT_SMD:SOT-323_SC-70 | C78261
BAT54CW | D1, D3, D5, D7, D9, D11 | Package_TO_SOT_SMD:SOT-323_SC-70 | C57891
MMBT4401LT1G | Q1, Q2, Q3, Q4, Q5, Q6, Q7, Q8, Q9, Q10 | digikey-kicad-library-master:SOT-23-3 | C31776
MMBT4403LT1G | Q11, Q12, Q13, Q14, Q15, Q16, Q17, Q18, Q19, Q20 | digikey-kicad-library-master:SOT-23-3 | C78864
NVTR4503NT1G_NMOS_GSD | Q21 | digikey-kicad-library-master:SOT-23-3 | C20917
SL3401A | Q22, Q23 | digikey-kicad-library-master:SOT-23-3 | C350311
8R2-1% | R21, R22, R23, R24, R25, R26 | Resistor_SMD:R_0805_2012Metric | C17830
470 | R1, R2, R3, R4, R5, R6, R7, R8, R9, R10, R11, R12, R13, R14, R15, R16, R17, R18, R19, R20, R28, R46 | Resistor_SMD:R_0805_2012Metric | C17710
1K2 | R30, R31, R54, R55 | Resistor_SMD:R_0805_2012Metric | C17379
68 | R32, R33 | Resistor_SMD:R_0805_2012Metric | C17802
10k | R27, R29, R36, R37, R38, R39, R40, R44, R45 | Resistor_SMD:R_0805_2012Metric | C17414
1k2 | R41, R42, R43 | Resistor_SMD:R_0805_2012Metric | C17379
1K5-1% | R47, R50, R53 | Resistor_SMD:R_0805_2012Metric | C4310
1K8-1% | R48, R51 | Resistor_SMD:R_0805_2012Metric | C17398
11-1% | R49, R52 | Resistor_SMD:R_0805_2012Metric | C17430
SK12D07L4B | SW1 | Switch_XKB_SK12D07VG4_SK12D07L4B:SK12D07VG4 | C480340
M24C02-RMN | U2 | Package_SO:SOIC-8_3.9x4.9mm_P1.27mm | C7562
74HC595D | U3, U4, U5 | digikey-kicad-library-master:SOIC-16_W3.90mm | C5947
LP38693MP-5.0 | U6 | Package_TO_SOT_SMD:SOT-223-5 | C140294
SSP9193-33M5R | U7 | Package_TO_SOT_SMD:SOT-23-5 | C411022
SN74LV1T125DBVR | U8 | Package_TO_SOT_SMD:SOT-23-5 | C473338
LM393 | U9 | digikey-kicad-library-master:SOIC-8_W3.9mm | C7955
SN74HC02DR | U10 | Package_SO:SOIC-14_3.9x8.7mm_P1.27mm | C350559
QWIIC | X9 | Connector_JST:JST_SH_SM04B-SRSS-TB_1x04-1MP_P1.00mm_Horizontal | C160404

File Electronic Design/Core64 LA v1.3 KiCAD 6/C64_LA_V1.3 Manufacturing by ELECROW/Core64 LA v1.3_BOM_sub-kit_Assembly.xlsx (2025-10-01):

Core64 Part Number | Indent Level | Revision | Description | Manufacturer | Manufacturer Part Number | Quantity | Unit | Original | Purchase Link | Purchase Link, Alternate | Substitute Notes
130-000 | 1 | v1.3 | CORE64-LA-KIT | - | - | 1 | ea | - | - | - | -
131-000 | 2 | A | LED ARRAY PACKAGING MATERIALS | - | - | 1 | ea | - | - | - | -
131-001 | 3 | A | Label, 2"x3", or similar | Avery | 36461 | 1 | ea | N | https://www.amazon.com/AVERY-Rectangle-Labels-Glossy-36461/dp/B08KJNNF2K/ | - | Any with same specifications.
131-002 | 3 | C | Bag, Antistatic, Closure, Clear or Blue, 5x8 inch | Desco | 13881 | 1 | ea | N | https://www.productionsupplystore.com/p/bag-statfree-clear-zip-5x8-100-ea-pack/ | https://www.digikey.com/en/products/detail/desco/13881/405665 | Any with same specifications.
131-003 | 3 | A | Tape, securing diffuser grid to PCBA for shipping (10-20mm wide) | - | - | 10 | cm | N | https://www.digikey.com/en/products/detail/olimex-ltd/KAPTON-TAPE10MM/19204468 | - | Any with same specifications.
132-000 | 2 | v1.3 | LED ARRAY BOARD PCBA (MANUFACTURER ASSEMBLED) | - | - | 1 | ea | N | - | - | -
133-000 | 2 | A | LED ARRAY COMPONENTS (USER ASSEMBLED) | - | - | 1 | ea | - | - | - | -
133-001 | 3 | A | Header, Male, 2.54mm (0.1inch) spacing, 1 row X 8 pins long, tin plated, overall length 18.54 mm. Alternate lengths: Contact Length - Mating 0.520" (13.21mm) or between 13 and 16 mm. Contact Length - Post 0.110" (2.79mm) or between 2 and 5 mm. Overall Contact Length 0.730" (18.54mm) or between 17.5 and 23.5 mm. Insulation Height 0.100" (2.54mm) | Samtec Inc. | TSW-108-15-T-S | 1 | ea | N | https://www.mouser.com/ProductDetail/Samtec/TSW-108-15-T-S?qs=rU5fayqh%252BE362Wn4H2IZhQ%3D%3D | https://www.digikey.com/product-detail/en/samtec-inc/TSW-108-15-T-S/SAM15389-ND/6691728 | Any with same specifications.
133-002 | 3 | A | Diffuser Grid, 3D Printed, SLS Nylon Black | - | - | 1 | ea | N | - | - | 3D Print
133-003 | 3 | A | 4x AAA Battery Holder with 6 inch flying leads | Keystone | 2482 | 1 | ea | N | https://www.mouser.com/ProductDetail/Keystone-Electronics/2482?qs=3CbvriavsLBQbNnN0ogSzA%3D%3D | https://www.digikey.com/product-detail/en/keystone-electronics/2482/36-2482-ND/303827 | Any with same specifications.
133-004 | 3 | A | AAA Battery | - | - | 4 | ea | N | https://www.amazon.com/AmazonBasics-Performance-Alkaline-Batteries-100-Pack/dp/B07VNMTPBR/ | - | Any with same specifications.
133-005 | 3 | A | Double Sided Tape, 1 to 2 mm (0.63 inch) thick, 25-50mm (1 to 2 inch) square | - | - | 1 | ea | N | https://www.amazon.com/fowong-Foam-Tape-White-Insulation/dp/B08BNLDDQ5/ | https://www.amazon.com/Art3d-Double-Sided-Transparent-Removable-Mounting/dp/B09K7SJ9CQ/?th=1 | Any with same specifications.

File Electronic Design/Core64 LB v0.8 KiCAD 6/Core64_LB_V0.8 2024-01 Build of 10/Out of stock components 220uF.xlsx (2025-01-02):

Designator | Comment | Footprint | Quantity
C7,C8,C9,C13,C14,C15 | 220uF | Capacitor_SMD:C_1206_3216Metric | 6

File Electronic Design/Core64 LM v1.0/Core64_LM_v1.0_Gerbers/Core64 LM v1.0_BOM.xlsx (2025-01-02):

Comment | Designator | Footprint | LCSC Part #（optional）
100nF | C1-8 | 0603_C | C14663
WS2813C | D1-64 | 5050 | C194323

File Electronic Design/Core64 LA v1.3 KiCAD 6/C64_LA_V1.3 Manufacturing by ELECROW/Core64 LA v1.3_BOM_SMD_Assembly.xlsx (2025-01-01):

*Reference | *Manufacturer Part number | *QTY | *Original | Description | Purchase Link
C1-8 | CC0603KRX7R9BB104 | 8 | N | 50V 100nF X7R ±10% 0603 Multilayer Ceramic Capacitors MLCC | https://jlcpcb.com/partdetail/Yageo-CC0603KRX7R9BB104/C14663
D1-64 | WS2813C | 64 | Y | WorldSemi WS2813C, SMD5050-6P | https://jlcpcb.com/partdetail/Worldsemi-WS2813CV3/C5359034

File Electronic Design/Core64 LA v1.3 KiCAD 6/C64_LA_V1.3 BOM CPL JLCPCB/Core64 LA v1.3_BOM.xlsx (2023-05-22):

Comment | Designator | Footprint | LCSC Part #（optional）
100nF | C1-8 | 0603_C | C14663
WS2813C | D1-64 | 5050 | C5359034

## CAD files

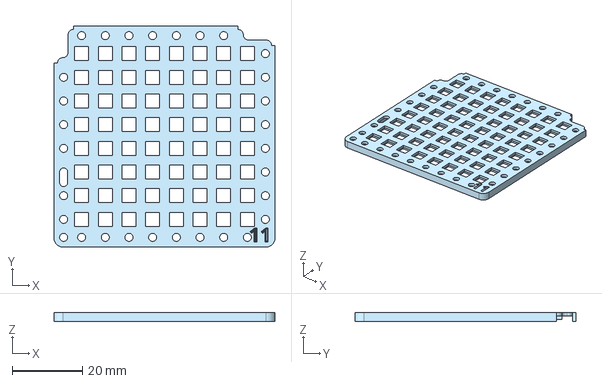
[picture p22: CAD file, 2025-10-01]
Electronic Design/Core64 LA v1.3 KiCAD 6/C64_LA_V1.3 Manufacturing by ELECROW/Core64 LA Diffuser Grid V11 Square 6/Core64 LA Diffuser Grid V11 Square 6.75mm centers.step
63.0 x 63.0 x 2.60 mm

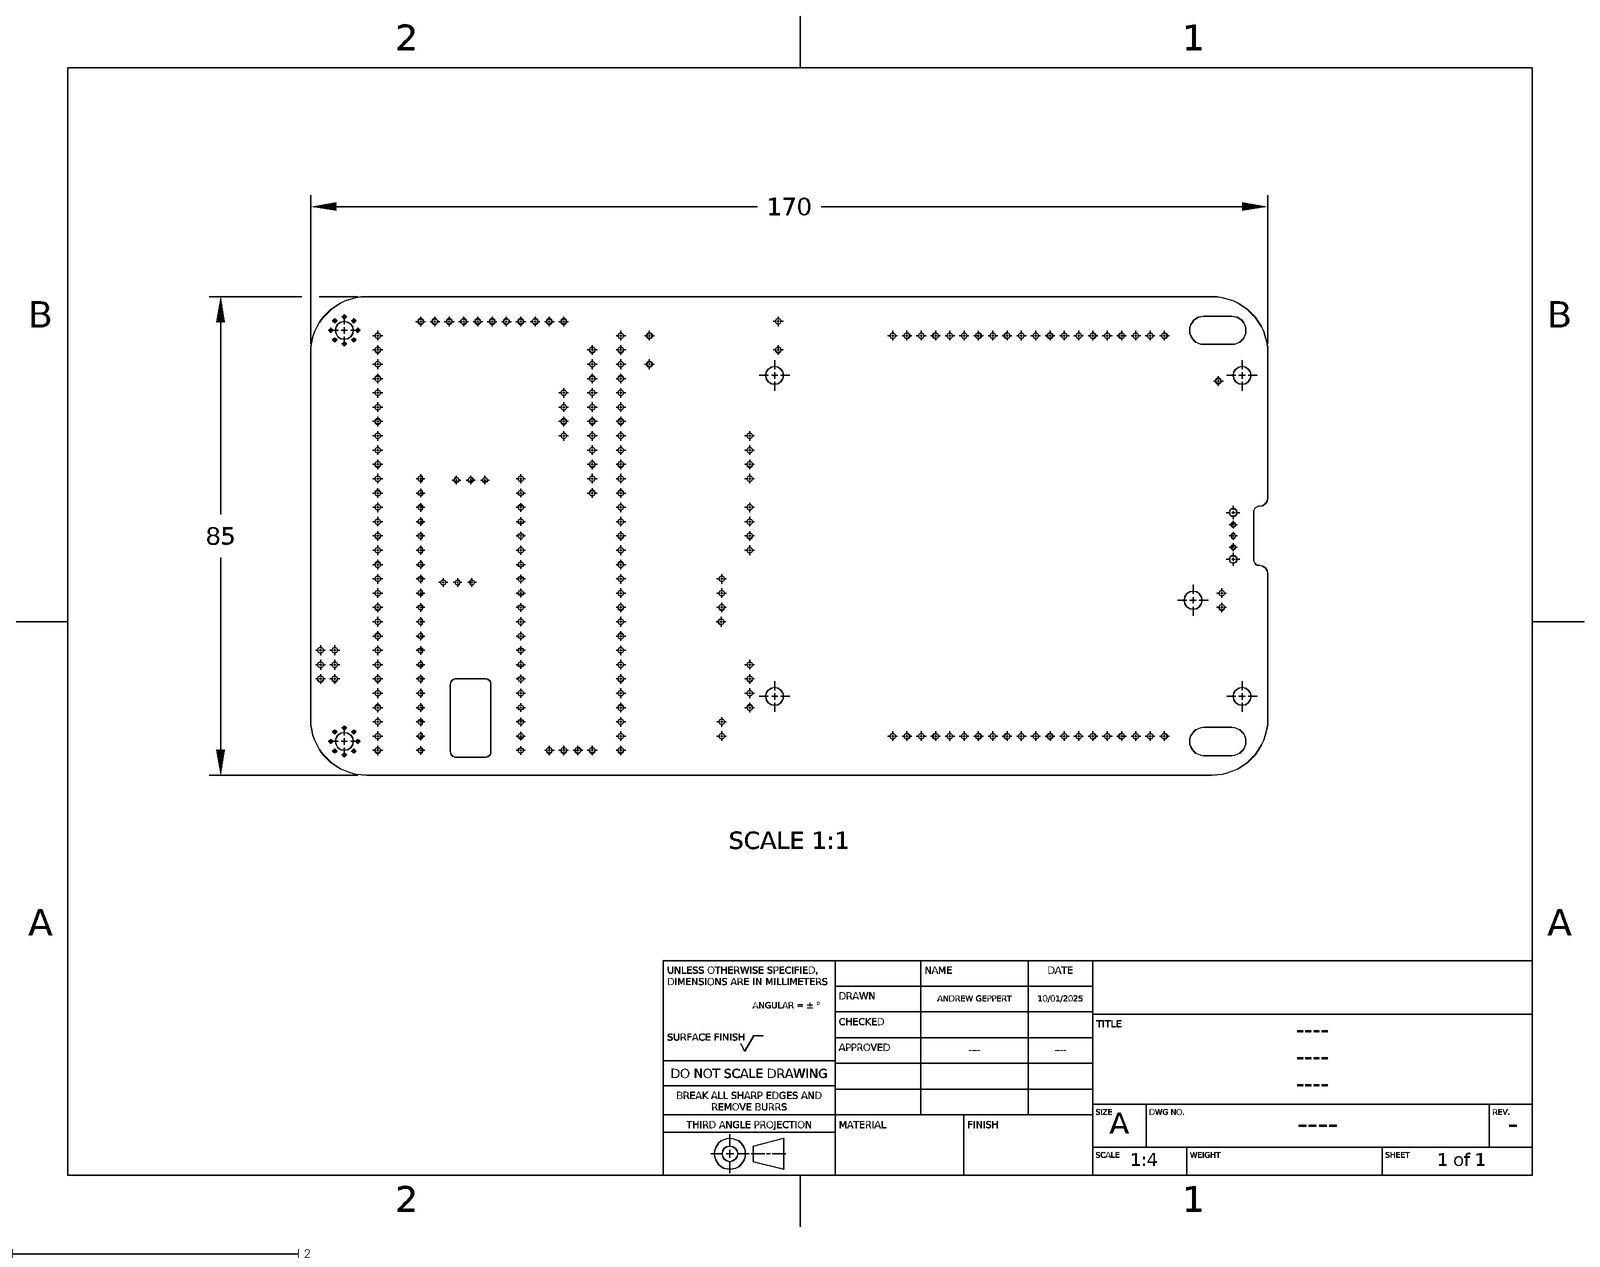
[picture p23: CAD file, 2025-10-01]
Mechanical Design/Core64 LB_PCB V0.8 Drawing.dxf
2
1
A
B
UNLESS OTHERWISE SPECIFIED, DIMENSIONS ARE IN MILLIMETERS
ANGULAR = ± °
SURFACE FINISH
DO NOT SCALE DRAWING
BREAK ALL SHARP EDGES AND REMOVE BURRS
THIRD ANGLE PROJECTION
NAME
DATE
DRAWN
ANDREW GEPPERT
10/01/2025
CHECKED
APPROVED
----
MATERIAL
FINISH
TITLE
SIZE
DWG NO.
REV.
-
SCALE
1:4
WEIGHT
SHEET
1 of 1
SCALE 1:1
170
85

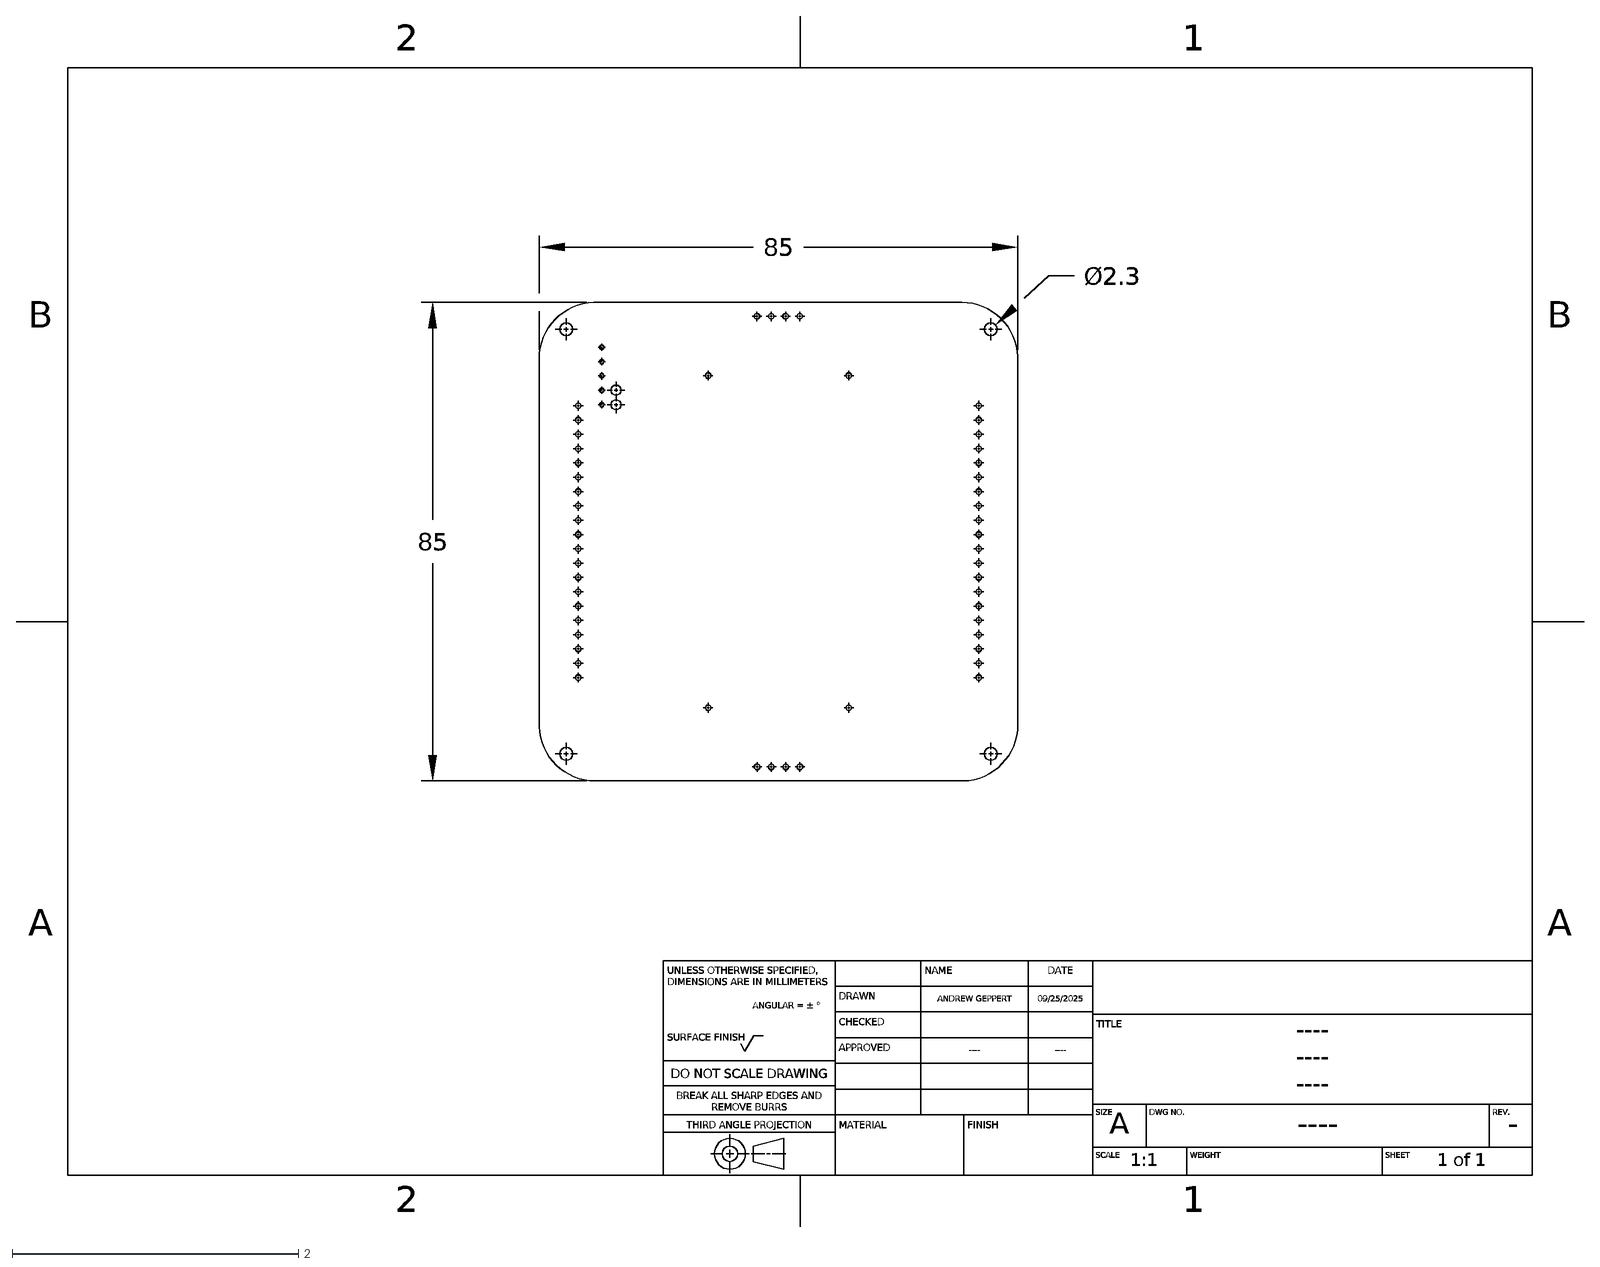
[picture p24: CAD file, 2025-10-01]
Mechanical Design/Core64 LED Array V1.3 Drawing.dxf
2
1
A
B
UNLESS OTHERWISE SPECIFIED, DIMENSIONS ARE IN MILLIMETERS
ANGULAR = ± °
SURFACE FINISH
DO NOT SCALE DRAWING
BREAK ALL SHARP EDGES AND REMOVE BURRS
THIRD ANGLE PROJECTION
NAME
DATE
DRAWN
ANDREW GEPPERT
09/25/2025
CHECKED
APPROVED
----
MATERIAL
FINISH
TITLE
SIZE
DWG NO.
REV.
-
SCALE
1:1
WEIGHT
SHEET
1 of 1
85
Ø2.3

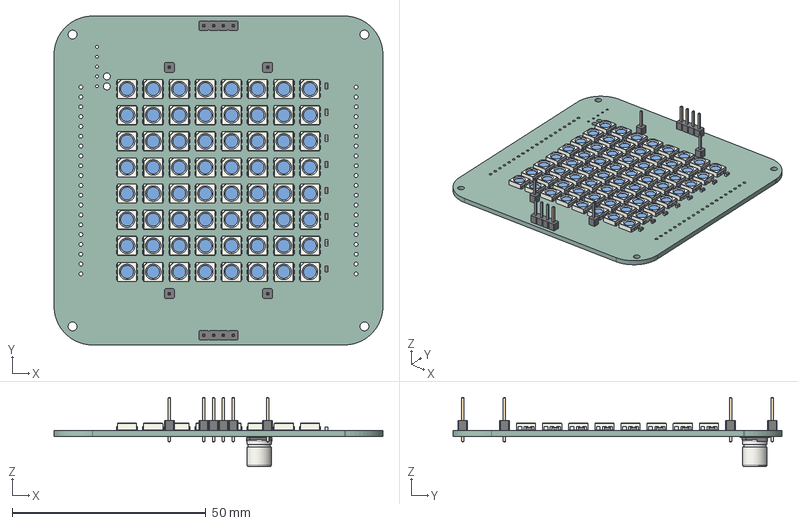
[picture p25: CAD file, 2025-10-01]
Mechanical Design/Core64 LED Array V1.3.step
85.0 x 85.0 x 17.9 mm
C_0603_1608Metric x 8
LED_WS2812_PLCC6_50x50mm_P16mm x 64
PinHeader_1x04_P254mm_Vertical x 2
PinHeader_1x01_P254mm_Vertical x 4
CP_Elec_63x77
Core64 LA_PCB

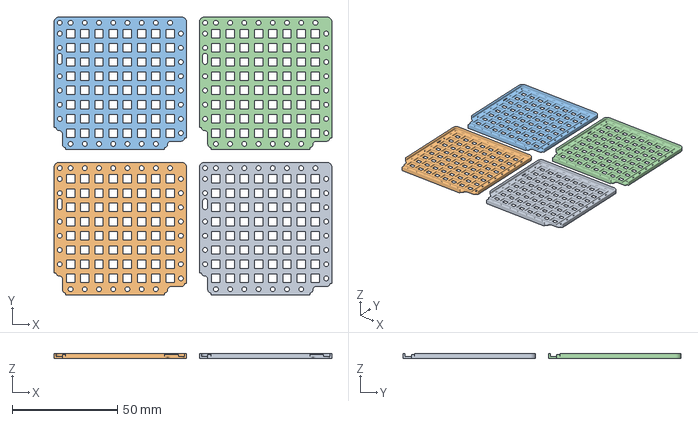
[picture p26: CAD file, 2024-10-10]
Mechanical Design/Diffuser Grid V11 Square 6.75mm centers.3mf
132.0 x 132.0 x 2.60 mm

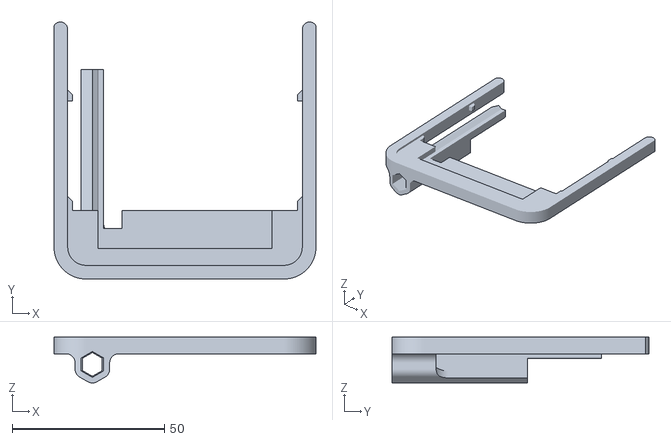
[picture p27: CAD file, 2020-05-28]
Mechanical Design/v0.3.28B LED Holder.stl
86.0 x 84.4 x 15.1

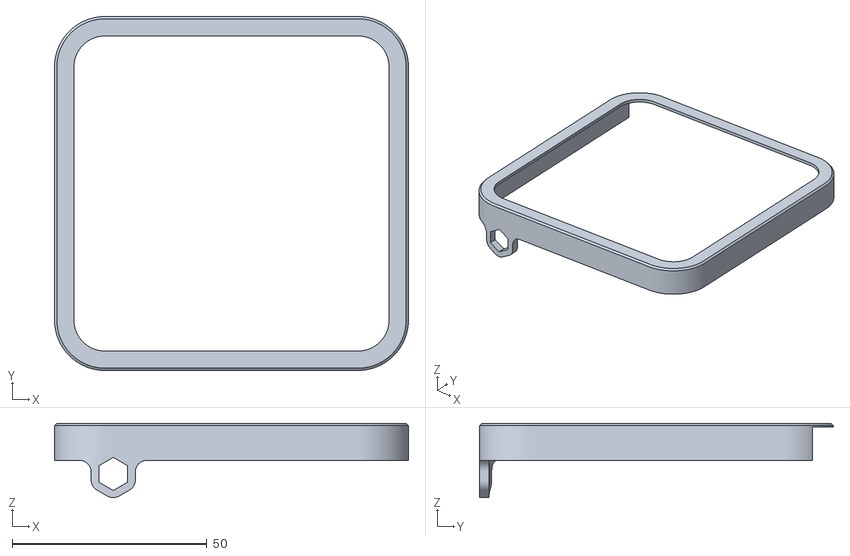
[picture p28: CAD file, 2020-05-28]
Mechanical Design/v0.3.28A LED Holder.stl
91.0 x 91.0 x 19.1

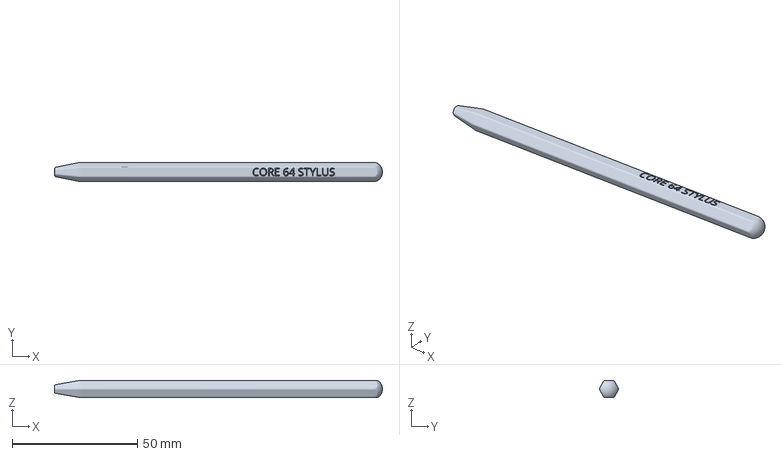
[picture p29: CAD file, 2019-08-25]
Mechanical Design/Core 64 Stylus V0.1.3mf
131.0 x 7.70 x 6.87 mm

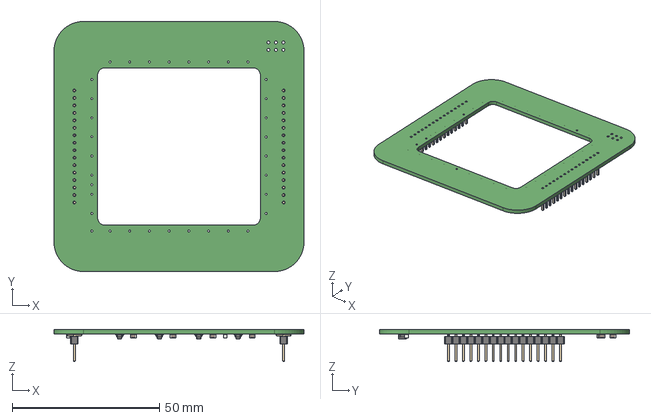
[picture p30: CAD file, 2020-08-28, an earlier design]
Electronic Design/Core64 CB v0.4/Core64 CB v0.4 Model.stp
85.0 x 85.0 x 11.0 mm

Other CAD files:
Mechanical Design/v0.3.28B LED Holder PLA (Z-1.190).3mf
Mechanical Design/v0.3.28A LED Holder PLA (Z-1.190).3mf
Electronic Design/Core64 LA v1.3 KiCAD 6/C64_LA_V1.3 Manufacturing by ELECROW/Core64 LA Diffuser Grid V11 Square 6/Core64 LA Diffuser Grid V11 Square 6.75mm centers.iges
Electronic Design/Core64 LA v1.3 KiCAD 6/C64_LA_V1.3 Manufacturing by ELECROW/Core64 LA Diffuser Grid V11 Square 6/Core64 LA Diffuser Grid V11 Square 6.75mm centers.stl
Electronic Design/Core64 LA v1.3 KiCAD 6/C64_LA_V1.3 Manufacturing by ELECROW/Core64 LA Diffuser Grid V11 Square 6/Core64 LA Diffuser Grid V11 Square 6.75mm centers.x_t
Mechanical Design/Core 64 Stylus V0.1.stl

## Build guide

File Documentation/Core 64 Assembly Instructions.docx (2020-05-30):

Core 64 Assembly Instructions

For Dual Board hardware version v0.3

2020-05-21 Draft Assembly Instructions Version v0.3.1

Inventory

Two major component kits are brought together to make one complete Core 64 Badge.

The kits is sold in three configurations:

1. Core 64 Core Board Only Starter Kit
2. Core 64 Logic Board and Finisher Kit
3. Core 64 Complete Kit (the Starter and Finished Kits together)
1) Core PCB Frame Assembly (all components needed to make the Core Board layer ready fore use)

Item No. | Description | Qty | Core 64 P/N
1 | Core 64 Frame Board (PCB 85x85mm) with all SMD components pre-assembled | 1 pc
2 | Magnet wire (grid 16x100mm + sense 750mm) RED COLOR: GREEN COLOR: COPPER COLOR: | 2350 mm (92 in.)
3 | Cores (64 needed, 6 spares included) | 70 pcs
4 | Header Pins 1 row x 16 pin 0.1” SMD or TO | 2 pcs
5
| * Solder, flux, and other tools are not included

2) Logic PCB (SMD is complete, some assembly required)
  a. Includes everything else (3D-printed LED Array holder, diffuser, screen protector, battery pack, headers, lanyard, stylus, magnet, Teensy LC, Pimoroni Unicorn Hat)

Tools Required

Ruler, scissors, wire cutter, forceps (tweezers or small needle nose pliers), soldering pencil, small gauge solder, flux pen, isopropyl alcohol, q-tips, kim wipes, multimeter,

Optional: magnifier, circuit board holder, flux remover,

Preparation

Clean all of the wire with IPA and a soft lint free wipe. This ensures there are no sticky spots or bits of fuzz that will make threading and weaving difficult. It’s a delicate process and you don’t want to tug hard to overcome sticky spots.

Cut 16 pcs of magnet wire, each 100 mm long. These are the grid wires.

Set aside the long uncut piece to be used as the sense wire later.

The first step, horizontal grid wires, is relatively simple. You will become familiar with how sensitive the wire is to be kinked, and how light the cores are. If you let go of one and it isn’t securely on the wire… it’s gone. Poof. Keep the wires straight, clean, and kink free.

The second step, vertical grid wires, is the hardest step. Plan to have a lot of patience in this step.

The third step is relatively easy compare to the second step, and the result will be very satisfying if you take your time and keep the wires aligned.

Core Board Assembly Procedure

Horizontal Grid Wires

For each grid wire, using your fingers, bend one end, at 1 cm long, at a right angle to the other 9 cm of wire. A soft bend is preferred instead of a sharp bend which can lead to the wire breaking off. This allows the board to be held up-side-down and the wires won’t fall out during solder. This also provides a length of wire to pull on during the last step of assembly, which is to straighten and tighten all of the grid wires. Don’t cut the extra wire off until all assembly is complete!

Place the Core 64 Frame Board up-side-down in a PCB work holder. The components will be facing up.

Insert the long end of the bent grid wire in hole YL0. The long end of the wire hangs straight down from the top face of the board for now, which is facing down.

The YL0 to 7 wires are all round solder pads. Skip the square sense wire solder pads for now. Those will be used after the 8x8 grid wires and cores are assembled.

Repeat this step for all YL# wires.

Solder the YL0 to 7 grid wires from the backside. Use flux and enough heat to ensure a good electrical connection is made and the burnt enamel on the magnet wire is displaced out of the solder joint. Plan to dwell with the solder pencil at the join for 5 seconds to ensure the enamel is burned away. We will verify the continuity later, and we will be reheating the some of the joints to tighten the grid of wires later.

Flip the board over so the top is up and the long ends of the grid wires are standing up. Clean any fuzz off the wires by gently pinching at the bottom of the wire and sliding your fingers up. You could also use IPA and q-tip to make sure there is no tape residue. This makes it easier to slide the cores on.

Sort the cores in groups of 8. I suggest two small groups of 4 to make the groups of 8. Carefully thread 8 cores onto each wire that is standing up. After each wire has 8 cores, carefully bend it over at the solder joint to head toward the YR0-7 holes. Count the cores on each wire to make sure there are 8 on each wire. Then insert the free end of the grid wire into the corresponding YR0-7 holes.

Admire your abacus.

Count the cores again. Make sure there are 8 on each wire, suspended in the middle and not caught under the wire near the first solder joint. It’s going to become difficult to back track from here forward. Take a break.

Flip the board over so you can solder on the back side again. Count ‘em again.

On the soldered end of the wire, push the wire down to be flush with the top of the board to prevent any cores from being able to slide on the wire and get caught between the top of the board and the wire.

Solder all 8 of the remaining wire ends. The initial soldering for all 8 can be “close enough.” Then go back and apply gentle tension with your fingers to pull the wire taught while reheating the solder joints to ensure a good connection. Continue to hold the wire 5 seconds after you remove the soldering pencil to avoid cold joints.

This is a good time to make grid wires look straight and tight (but not too tight or the wire will break). Aim for about 70% good enough because you will probably want to re-tighten them after the rest of the threading is completed. It is difficult to maintain tension during the rest of the process because the wire is so soft and if you bump it the tiniest bit, it’ll be deformed. That why the final tightening step is at the very end, just before cutting the excess grid wire.

Continuity check. From the solder joint at each end of each of the grid wires. Or at header pin holes.

Vertical Grid Wires

Now is where it starts to get interesting. We’re going to thread each vertical wire through 8 cores, with the cores in a specific pattern.

Clean the 8 vertical grid wires with IPA. Straighten them carefully. ANY kink in the wire will be a hinderance to thread the wire through the column. There is barely enough room for the wires to fit through the cores if they are all on-axis and it is made more difficult by the fact that the cores are off-axis. Use very little force, and a combination of pushing and pulling the wire to thread it.

Gently rotate the wire as you push it through the to help it overcome any sticky spots.

Solder one end of each wire without concern of a long dwell to burn the enamel.

Solder the opposite end of each wire, taking care to burn away the enamel and make a good connection.

Go back to the first end, tighten the wires with your fingers as you re-heat the joint and burn away the enamel.

Verify continuity from end to end, like the horizontal grid wires.

Take the time to make the grid nice and straight. If you get through the sense wire threaded smoothly, you won’t need to retighten the grid wires.

Sense Wire

Starting with a straight, smooth, and clean sense wire will be very rewarding at this stage. It prevents pulling the grid wires out of alignment. As you clean the wire, pay attention to ripples or wrinkles or kinks in the wire. Smooth out the entire length of the wire carefully because you will be pulling it through a lot of cores over and over. The upside is that you’ll be doing the pulling and pushing on-axis, and that makes up for the long and carefully weaving that is needed.

Start at the S2 sense pad [square] and thread the wire diagonally up and to the right, following the pattern shown here.

Keep the wire in a flat plane parallel to the core board when you turn around at the ends. Take care to prevent cross-over kinks as you pull the wire into the final position. The top of a ball point pen or mechanical pencil is very helpful to keep the wire going straight into the core as you pull it across the cores.

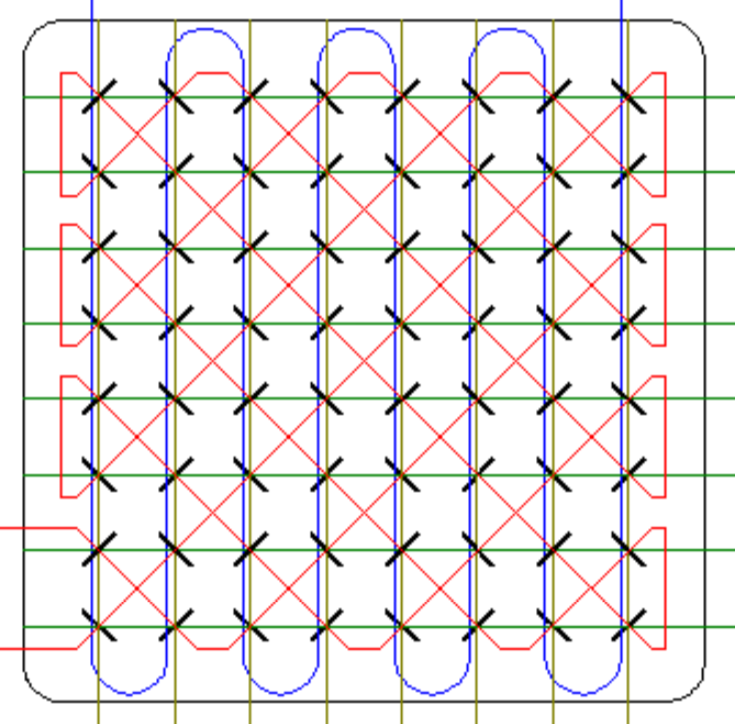
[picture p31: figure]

Continuity check. From the solder joint at each end of each of the grid wires. Or at header pin holes.

LED Array Holder Assembly Procedure

A

B

CORE LOGIC BOARD ASSEMBLY

IMPORTANT: Before installing the TEENSY LC you must cut the Vin-Vusb jumper trace on the bottom of the board.

Installing and aligned the sockets.

Trim the SMT sockets to length

Use the extra from the short side to make a 4-pin header for the OLED X1 connector if you’d like.

OPTIONAL HEADERS

Cut the excess length off the pins before soldering the headers to the board to leave a smooth backside to the badge. Better to have the pins slightly recessed before they are soldered so the solder doesn’t stick out.

Core Logic Board,

X1, I2C OLED: Configure JP3 and JP4 to provide power to the proper pins for your OLED display.

X2, SD CARD: requires Adafruit _____

X3, QWIIC: for the Sparkfun Qwiic product line

X4, SAO_1:

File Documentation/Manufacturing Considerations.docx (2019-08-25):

Manufacturing Considerations

Core 64: Interactive Core Memory Badge, Andrew Geppert, 2019-08-24

* Highest risk items.

General

No tooling investment factored in. Any plastic components are 3D printed.

Sourcing

PCB(s): www.OSHPARK.com

At least the main board.

* Maybe the LED array board, pending licensing of Pimoroni, but the retail cost is quite high. May need to create this board on my own, and possible source lower cost LEDs at the same time.

* COREs: eBay sellers indicate limited quantities in the 1000s of NOS. (https://www.ebay.com/i/302520781100) Need to find out how deep this inventory, the demand, and if anyone is still manufacturing cores.

Teensy LC. Need to contact PJRC to understand availability.

Adafruit Micro Lipo Charger. Need to contact PJRC to understand availability.

Enamel coated wire (must be meltable during soldering), jellybean components, commodity items.

Assembly

Assembly does NOT include wiring of the core array. That is left to the user.

Assemble and test PCBAs in the US. Consider Adafruit, Sparkfun.

Somewhere warm so I can get away from the Minnesota winter, conveniently.

Easy to remove connection between main board and LED array to allow different diffuser layer experiments.

Consider

Test

Standard/shippable firmware will have built-in test mode.

Test fixture will exercise all I/O and verify

All units will be versioned and serialized with a label, and in the emulated Teensy LC EEPROM

Kitting

64 plus 6 spares in bag, total of 70 cores per kit.

Enamel wire approximately 70 inches, rolled, plastic bag.

Consider tools: precision tweezers, forcepts

Shipping

Both boards will be joined together for secure shipping.

Support

Github documentation and Wiki will be the primary resource.

Possibly a forum to share projects and ideas and ask questions (community and/or I will answer as we are able to).

Estimated Cost

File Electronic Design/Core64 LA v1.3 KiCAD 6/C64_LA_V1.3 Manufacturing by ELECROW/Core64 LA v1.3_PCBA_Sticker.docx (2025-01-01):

QC: Passed

MFR: Elecrow YYWW

PCBA VER: 1.3

LED: WS2813C

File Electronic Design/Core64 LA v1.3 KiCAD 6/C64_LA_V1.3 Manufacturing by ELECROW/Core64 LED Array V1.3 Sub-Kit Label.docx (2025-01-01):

LED ARRAY KIT 130-000 CORE64-LA-KIT V1.3 [ ] Qty 1, LED Array PCBA, WS2813C [ ] Qty 1, Diffuser Grid 3D Print (Welcome Sheet has Diffuser Paper) [ ] Qty 1, 1x8 pin TH 0.1” male headers, >0.5” lg [ ] Qty 1, Battery Holder 4x “AAA” [ ] Qty 1, Double-sided Tape Square [ ] Qty 4, “AAA” Battery | LED ARRAY KIT 130-000 CORE64-LA-KIT V1.3 [ ] Qty 1, LED Array PCBA, WS2813C [ ] Qty 1, Diffuser Grid 3D Print (Welcome Sheet has Diffuser Paper) [ ] Qty 1, 1x8 pin TH 0.1” male headers, >0.5” lg [ ] Qty 1, Battery Holder 4x “AAA” [ ] Qty 1, Double-sided Tape Square [ ] Qty 4, “AAA” Battery
LED ARRAY KIT 130-000 CORE64-LA-KIT V1.3 [ ] Qty 1, LED Array PCBA, WS2813C [ ] Qty 1, Diffuser Grid 3D Print (Welcome Sheet has Diffuser Paper) [ ] Qty 1, 1x8 pin TH 0.1” male headers, >0.5” lg [ ] Qty 1, Battery Holder 4x “AAA” [ ] Qty 1, Double-sided Tape Square [ ] Qty 4, “AAA” Battery | LED ARRAY KIT 130-000 CORE64-LA-KIT V1.3 [ ] Qty 1, LED Array PCBA, WS2813C [ ] Qty 1, Diffuser Grid 3D Print (Welcome Sheet has Diffuser Paper) [ ] Qty 1, 1x8 pin TH 0.1” male headers, >0.5” lg [ ] Qty 1, Battery Holder 4x “AAA” [ ] Qty 1, Double-sided Tape Square [ ] Qty 4, “AAA” Battery
LED ARRAY KIT 130-000 CORE64-LA-KIT V1.3 [ ] Qty 1, LED Array PCBA, WS2813C [ ] Qty 1, Diffuser Grid 3D Print (Welcome Sheet has Diffuser Paper) [ ] Qty 1, 1x8 pin TH 0.1” male headers, >0.5” lg [ ] Qty 1, Battery Holder 4x “AAA” [ ] Qty 1, Double-sided Tape Square [ ] Qty 4, “AAA” Battery | LED ARRAY KIT 130-000 CORE64-LA-KIT V1.3 [ ] Qty 1, LED Array PCBA, WS2813C [ ] Qty 1, Diffuser Grid 3D Print (Welcome Sheet has Diffuser Paper) [ ] Qty 1, 1x8 pin TH 0.1” male headers, >0.5” lg [ ] Qty 1, Battery Holder 4x “AAA” [ ] Qty 1, Double-sided Tape Square [ ] Qty 4, “AAA” Battery
LED ARRAY KIT 130-000 CORE64-LA-KIT V1.3 [ ] Qty 1, LED Array PCBA, WS2813C [ ] Qty 1, Diffuser Grid 3D Print (Welcome Sheet has Diffuser Paper) [ ] Qty 1, 1x8 pin TH 0.1” male headers, >0.5” lg [ ] Qty 1, Battery Holder 4x “AAA” [ ] Qty 1, Double-sided Tape Square [ ] Qty 4, “AAA” Battery | LED ARRAY KIT 130-000 CORE64-LA-KIT V1.3 [ ] Qty 1, LED Array PCBA, WS2813C [ ] Qty 1, Diffuser Grid 3D Print (Welcome Sheet has Diffuser Paper) [ ] Qty 1, 1x8 pin TH 0.1” male headers, >0.5” lg [ ] Qty 1, Battery Holder 4x “AAA” [ ] Qty 1, Double-sided Tape Square [ ] Qty 4, “AAA” Battery
LED ARRAY KIT 130-000 CORE64-LA-KIT V1.3 [ ] Qty 1, LED Array PCBA, WS2813C [ ] Qty 1, Diffuser Grid 3D Print (Welcome Sheet has Diffuser Paper) [ ] Qty 1, 1x8 pin TH 0.1” male headers, >0.5” lg [ ] Qty 1, Battery Holder 4x “AAA” [ ] Qty 1, Double-sided Tape Square [ ] Qty 4, “AAA” Battery | LED ARRAY KIT 130-000 CORE64-LA-KIT V1.3 [ ] Qty 1, LED Array PCBA, WS2813C [ ] Qty 1, Diffuser Grid 3D Print (Welcome Sheet has Diffuser Paper) [ ] Qty 1, 1x8 pin TH 0.1” male headers, >0.5” lg [ ] Qty 1, Battery Holder 4x “AAA” [ ] Qty 1, Double-sided Tape Square [ ] Qty 4, “AAA” Battery

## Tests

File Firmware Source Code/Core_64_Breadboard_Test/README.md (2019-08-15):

The hardware configuration for this test is:

1) Teensy LC powered via USB.
2) Pimoroni Unicorn Hat connected to Digital Pin 17 (driven at Vin).
3) OLED display to I2C SCL0 and SDA0 on pins 19/18.

See HardwareIOMap.h

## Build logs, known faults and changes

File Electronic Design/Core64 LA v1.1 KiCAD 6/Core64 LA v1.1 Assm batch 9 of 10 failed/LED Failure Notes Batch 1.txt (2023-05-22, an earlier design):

I received 10 completely assembled PCBs. There are problems with 9 of them. The problem is that some of the LEDs do not work. Somewhere between 1 and 5 LEDs do not work. Some of the LEDs do not light up at all. Some partially work with one or two colors out of the three RGB colors. I have ordered many of these from JLCPCB before, and have almost no problems. In one case, one LED was not completely soldered down, but after I reflowing it with hot air, it worked just fine. I tried reflowing several of the LEDs in this batch, but that did not fix the ones that did not work at all. It would also not fix LEDs that were partially working because even for them to partially work, all solder joints must be completed so it can receive the properly encoded signals. The bad LEDs do not follow a pattern - they are randomly distributed around the boards. Because of this troubleshooting, I think there were several defective LEDs in this batch. 

FIXED: 1A 3 dead, 1 no green. Replaced D18, 23, 33, 46
Donor: 1B 1 no green, 1 no red. Donor board. Flux it first. Heat with 315°C on the backside, wide square nozzle.
FIXED: 1C 2 dead, 1 (43) no blue or green. Flakey behavior. Replaced 18, 43. 43 fixed all the columns of vertical flakiness.
WORKS: 1D ALL GOOD
FIXED: 1E 2 without blue (19 and 42?)
FIXED: 1F 2 dead (2, 57),  1 no blue (13) (reflowed 2 and 13 and that alone didn't work). Then 17 failed, but came back as it cooled. Replaced 17.
FIXED: 1G 1 dead. Reworked D4.
FIXED: 1H 1 dead. Reworked D61.
FIXED: 1I 4 dead, 1 no green. Replaced 7,31,35,55,57
FIXED: 1J 4 dead, replace 15, 17, 42, 61, Then 49,56 needed replacement.

--------------

Hello sir or madam,

Thanks for your feedback and sorry for any inconvenience caused.
We have checked your order information and notice that the LED you used C194323 is a moisture-sensitive part.
For this kind of part, it is suggested to bake the parts before assembly. And if you use many LEDs in your design, we suggest you proceed function test before delivery. There is some notice on our website. Kindly check the attachment. https://jlcpcb.com/help/article/61-Terms-and-Conditions-of-JLCPCB-Assembly-Service
For these boards, could you please check how many leds in total are affected? And would it be possible that you get some replacements at your local and replace them on the boards? We would apply some coupon as compensation. Would it be acceptable?

Best regards,
Emma

-----------------

So I baked them on the 3d Printer hot plate. No change. Number of dead LEDs confirmed:
A 4
B 3
C 3 and a lot of flakey behavior
D 0
E 2
F 3
G 1
H 1
I 5
J 4

Total of 26 out of 640 dead. 4% failure rate.

------------------

Hi Emma, thank you for your quick response.

I understand the LED is a moisture sensitive component. Did the facility which performed the assembly follow the moisture precautions?

After I tested the assembled boards, I baked them and re-tested them. There was no change in behavior. There are 26 failed LEDs out of the total 640 (10 boards X 64 LEDs per board). My previous orders from JLCPCB Assembly service had no problems. All boards worked.

Do you have any others ideas about what might be different between this order SMT02303081158784 and the last order SMT0220915965060? Did a different company manufacture them?

I have just placed another sample order W202303171122582 using a newer version of the LED (P/N C5359034, WS2813C-V3) and I hope those LEDs will be just as reliable as my previous orders. If you could add 30 of that LED part as to this existing order when it ships to me, I can try replacing the LEDs on the PCBAs which have failed LEDs.

I would also appreciate a coupon for my next assembly order. If my sample order W202303171122582 turns out OK, I will need to follow-up and order 45 more of the same PCBAs right away. 

Respectfully,
Andy

-------------------

Hello Andy,

Thanks for your reply and great effort.
1-The parts should be baked before assembly. If there is some vapor in the part inside, after reflowing the part functionality would be affected. Baking after assembly would not help. The parts are kept in our warehouse in good condition. But when the parts are unpacked, there may be some time before assembly, and during which it may cause some moisture into the part. If you inform us to bake the boards, then we will bake them for 48 hours and take them out of the oven when they are ready for assembly.
2-There is some risk of malfunction if the parts are not baked. Therefore, some can work normally, and some have a certain number of components damaged, which is normal. It does not mean that the components we received are not good.JLC totally understand that parts are so important to working boards, so all our parts are from reliable supplier and are quality-assured. Please do not worry about that.
3-We are sorry that we cannot send more parts with assembly with the boards, since it may cause some custom clearance trouble. And also, when we get the parts from our warehouse, we can only get the same quantity as the order requires. Could you please try to get some parts at your local? We would apply a $10 coupon for you. Would it be acceptable?
4-For your new order, I will send you an email for further confirmation. Kindly check it later.

Best regards,
Emma

-----------------------

So my next order will bake the LEDs...

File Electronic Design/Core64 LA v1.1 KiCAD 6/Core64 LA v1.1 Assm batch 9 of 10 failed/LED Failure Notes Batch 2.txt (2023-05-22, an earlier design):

I received 5 completely assembled PCBs. 2 of 5 failed.

WORKS: 2K OK
WORKS: 2L OK
WORKS: 2M OK
FIXED: 2N D24 out. Replaced from batch 1 LEDs

FIXED: 2O Flakey D13, 15. Dead 23, 33, 38, 44, 48, bottom two rows.
Replaced 13. That fixed flakey 15 as well.
Reflowed 48, 49 to see if 50 and beyond would work. That did not help.
Replaced 23,33,38,44,48. That fixed all but 3 in the bottom two rows.
Replaced 49, 60, 62. Now it all works.

330°F with the 3/8 round nozzle was just hot enough to get the job done, but not yellow the boards.
Even 5° more would yellow them.

A hot plate at 300°F would have been ideal.

Conclusion is that the LEDs are a bad batch. I don't want to use those any more!

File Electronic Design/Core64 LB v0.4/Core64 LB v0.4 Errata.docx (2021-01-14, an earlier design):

Core64 Logic Board (LB) v0.4 Errata.docx

Updated 2021-01-12

FRONT SIDE

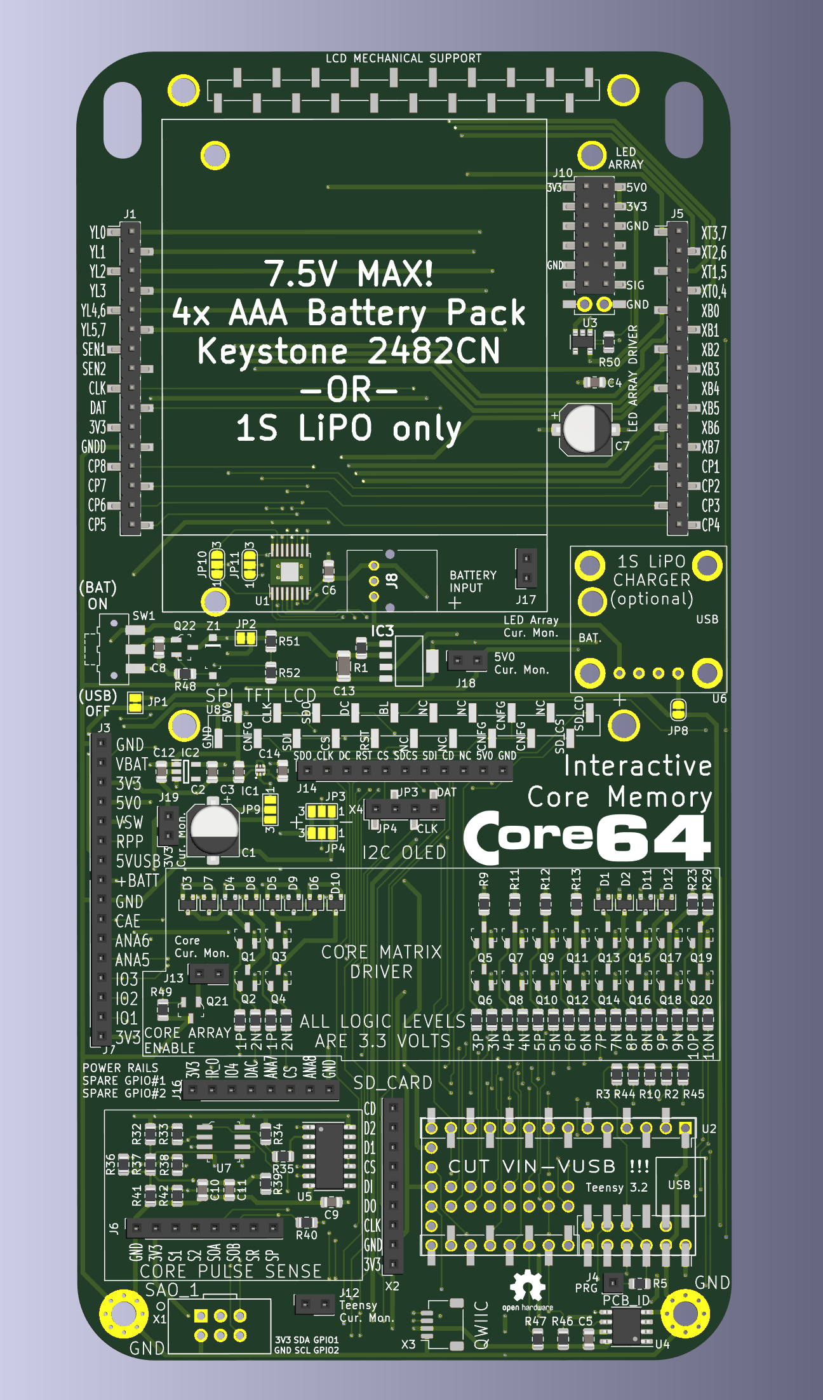
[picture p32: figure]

Silkscreen error. 3V3 should be 5V0.

Q22 footprint

is wrong

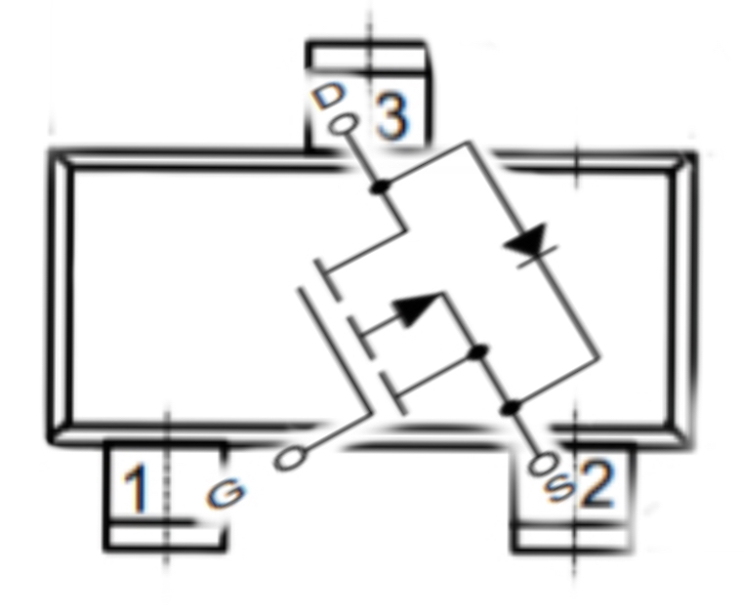
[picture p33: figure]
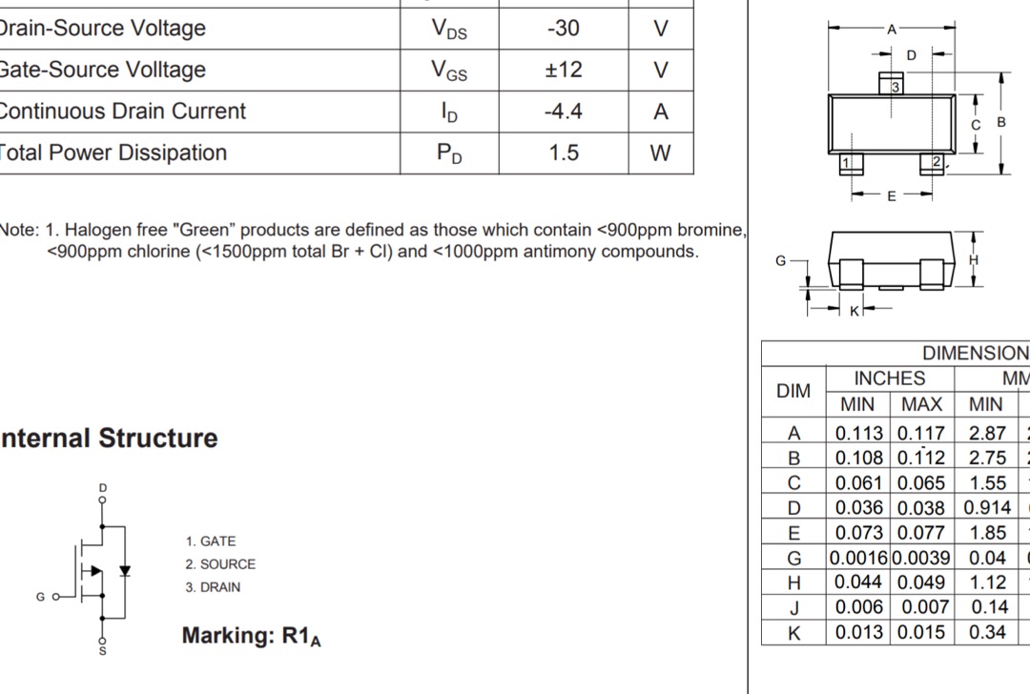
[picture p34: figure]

Q21 footprint

is wrong

Silkscreen error, should be, left-to-right: 1P 1N 2P 2N

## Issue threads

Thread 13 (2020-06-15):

Lines in OLED screen intermittent

ageppert, 2020-06-15:
Since beginning to add more I2C functionality in V0.3 there are interference lines showing up intermittently.

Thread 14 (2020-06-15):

Hall sensor I2C takes to reads to get a value

ageppert, 2020-06-15:
As I add I2C IO Expander commands to bring up the core memory functionality, specifically the enable transistor for the array, now I need to read the hall sensor twice in a row to get a response. Seems like interference with all the I2C stuff?

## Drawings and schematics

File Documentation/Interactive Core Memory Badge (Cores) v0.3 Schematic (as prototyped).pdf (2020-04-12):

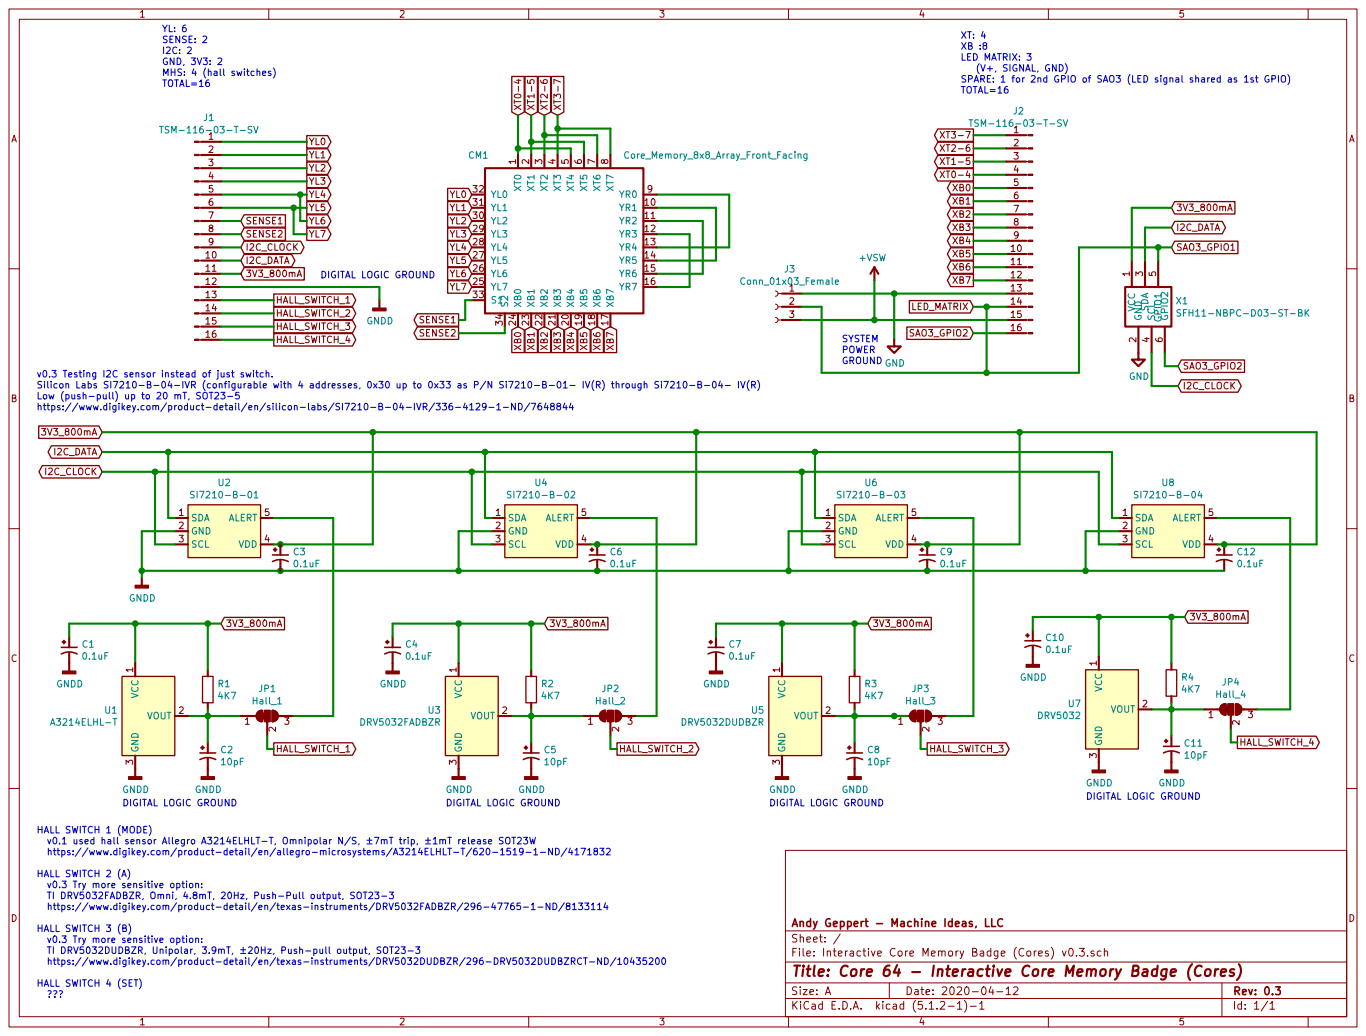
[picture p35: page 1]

I2C: 2 GND, 3V3: 2 MHS: 4 (hall switches) TOTAL=16

SPARE: 1 for 2nd GPIO of SAO3 (LED signal shared as 1st GPIO) TOTAL=16 GNDD

https://www.digikey.com/product-detail/en/silicon-labs/SI7210-B-04-IVR/336-4129-1-ND/7648844 DIGITAL LOGIC GROUND

6 X1SFH11-NBPC-D03-ST-BK GND

v0.3 Testing I2C sensor instead of just switch.
Silicon Labs SI7210-B-04-IVR (configurable with 4 addresses, 0x30 up to 0x33 as P/N Si7210-B-01- IV(R) through Si7210-B-04- IV(R)
Low (push-pull) up to 20 mT, SOT23-5

HALL SWITCH 1 (MODE)
v0.1 used hall sensor Allegro A3214ELHLT-T, Omnipolar N/S, ±7mT trip, ±1mT release SOT23W
https://www.digikey.com/product-detail/en/allegro-microsystems/A3214ELHLT-T/620-1519-1-ND/4171832

HALL SWITCH 2 (A)
v0.3 Try more sensitive option:
TI DRV5032FADBZR, Omni, 4.8mT, 20Hz, Push-Pull output, SOT23-3
https://www.digikey.com/product-detail/en/texas-instruments/DRV5032FADBZR/296-47765-1-ND/8133114
HALL SWITCH 3 (B)
TI DRV5032DUDBZR, Unipolar, 3.9mT, ±20Hz, Push-pull output, SOT23-3
https://www.digikey.com/product-detail/en/texas-instruments/DRV5032DUDBZR/296-DRV5032DUDBZRCT-ND/10435200

Id: 1/1 Title: Core 64 - Interactive Core Memory Badge (Cores)

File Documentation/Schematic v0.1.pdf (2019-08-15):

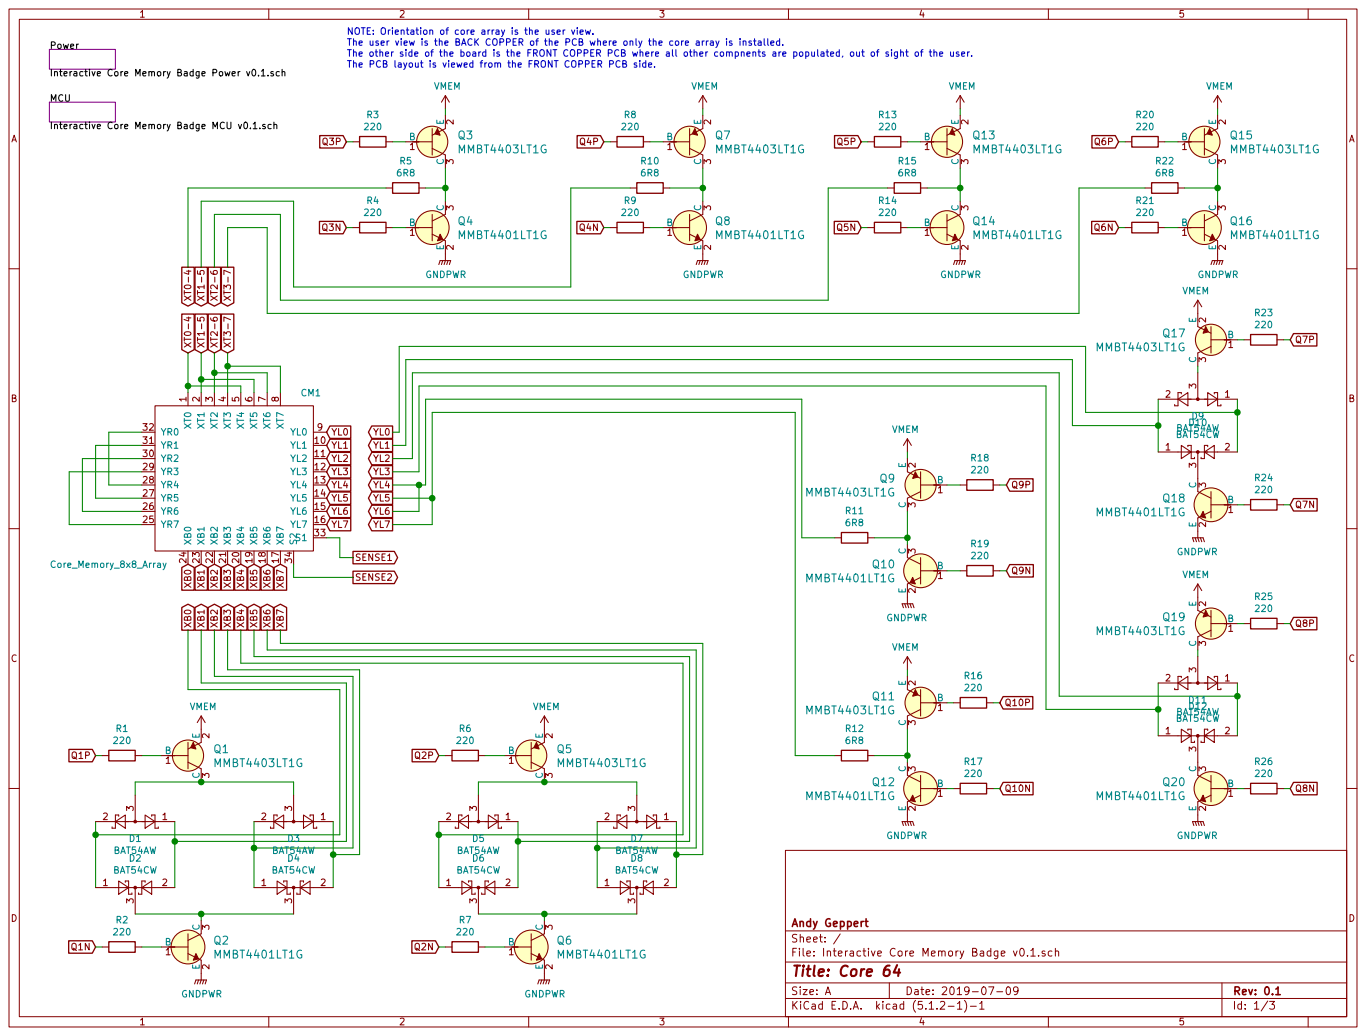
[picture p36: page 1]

NOTE: Orientation of core array is the user view.
The user view is the BACK COPPER of the PCB where only the core array is installed.
The other side of the board is the FRONT COPPER PCB where all other compnents are populated, out of sight of the user.

Power
Interactive Core Memory Badge Power v0.1.sch MCU

Interactive Core Memory Badge MCU v0.1.sch XB0 XB1 XB2 XB3 XB4 XB5 XB6 XB7 XT0-4 XT1-5 XT2-6 XT3-7 XT0

File: Interactive Core Memory Badge v0.1.sch Sheet: / Andy Geppert

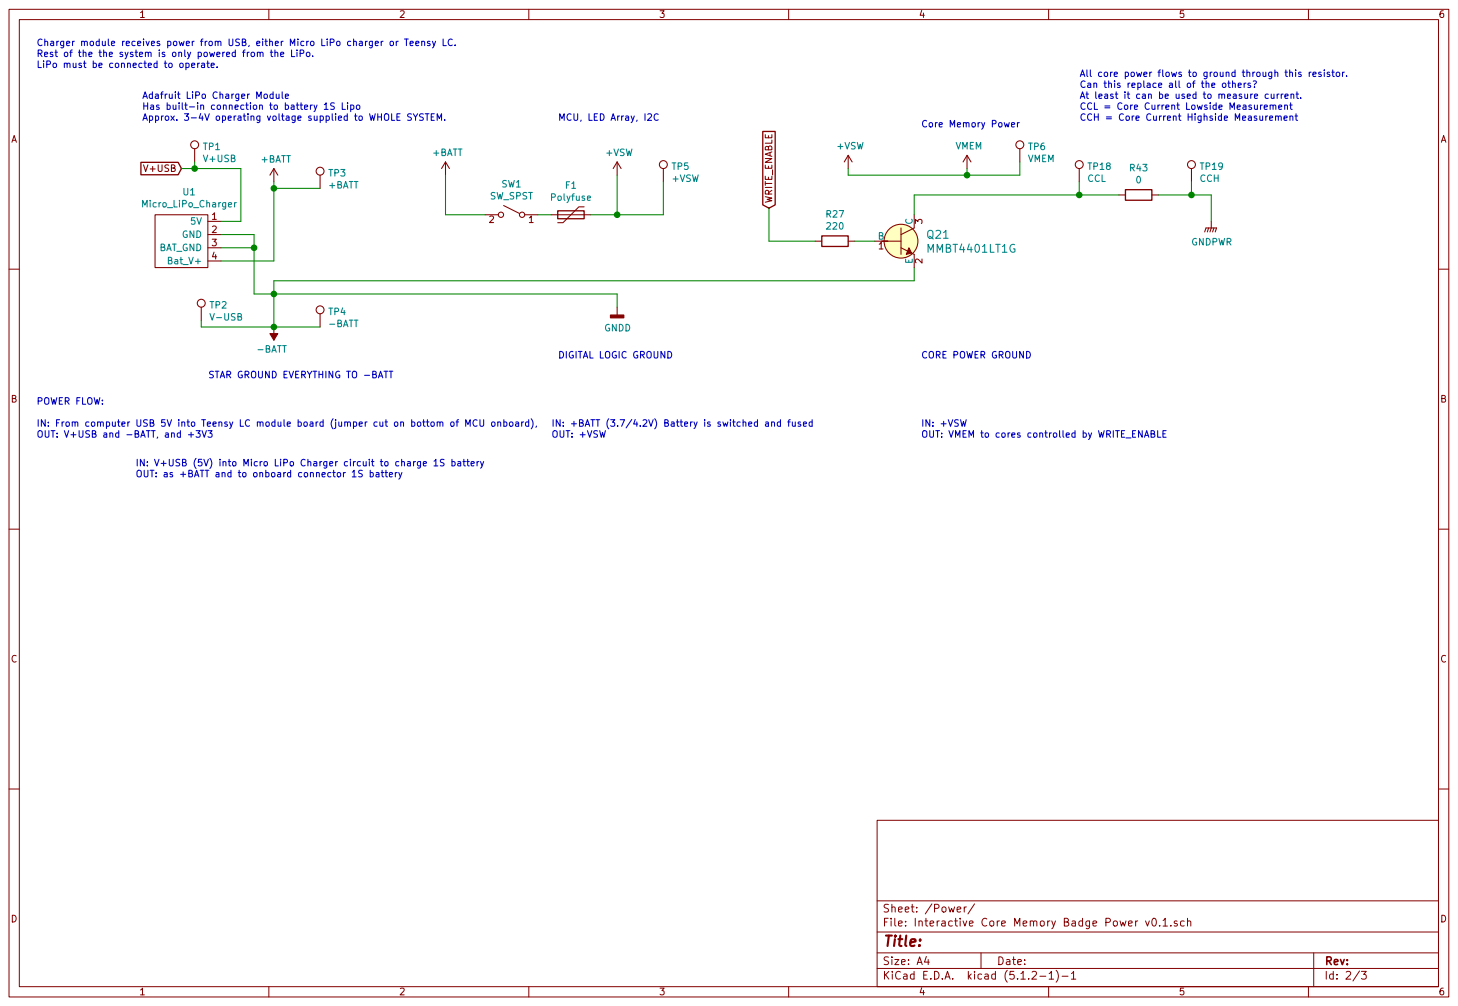
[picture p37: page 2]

Charger module receives power from USB, either Micro LiPo charger or Teensy LC.
Rest of the the system is only powered from the LiPo.

0 All core power flows to ground through this resistor.

Adafruit LiPo Charger Module
Has built-in connection to battery 1S Lipo
Approx. 3-4V operating voltage supplied to WHOLE SYSTEM.

Core Memory Power MCU, LED Array, I2C

OUT: as +BATT and to onboard connector 1S battery POWER FLOW:

IN: From computer USB 5V into Teensy LC module board (jumper cut on bottom of MCU onboard), OUT: V+USB and -BATT, and +3V3

IN: +BATT (3.7/4.2V) Battery is switched and fused OUT: +VSW

IN: V+USB (5V) into Micro LiPo Charger circuit to charge 1S battery

File: Interactive Core Memory Badge Power v0.1.sch Sheet: /Power/
Id: 2/3 Title:

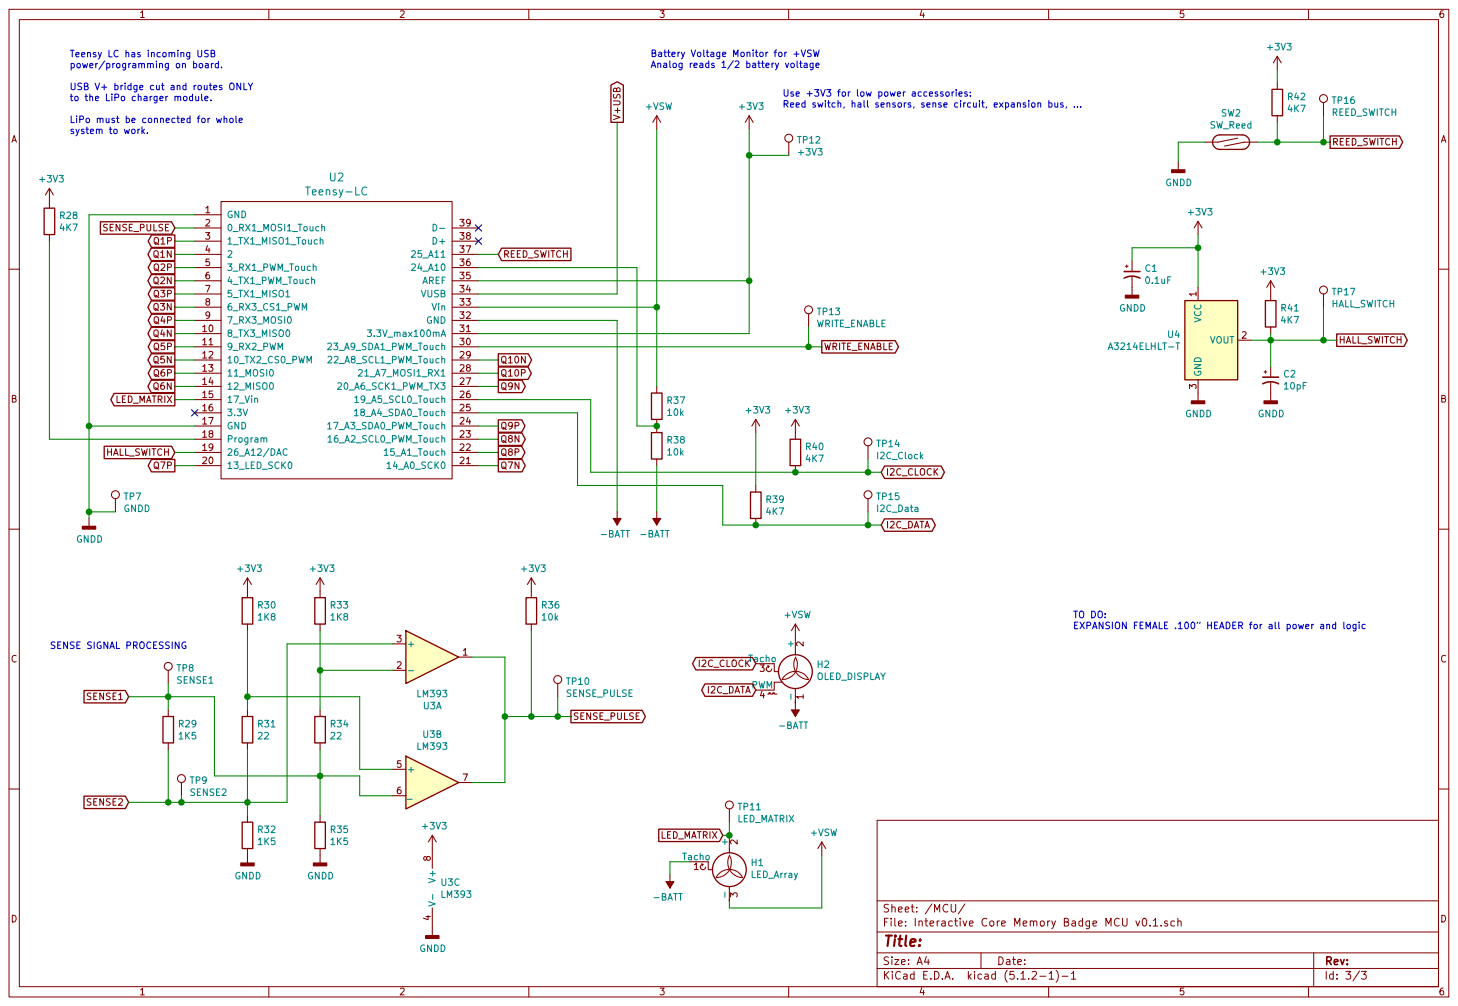
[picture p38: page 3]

Teensy LC has incoming USB
power/programming on board.

10k Battery Voltage Monitor for +VSW
Analog reads 1/2 battery voltage
TP12 +3V3TP13 WRITE_ENABLE

USB V+ bridge cut and routes ONLY
to the LiPo charger module. LiPo must be connected for whole
Reed switch, hall sensors, sense circuit, expansion bus, SENSE SIGNAL PROCESSING

TO DO: EXPANSION FEMALE .100 HEADER for all power and logic 1

File: Interactive Core Memory Badge MCU v0.1.sch Sheet: /MCU/
Id: 3/3 Title:

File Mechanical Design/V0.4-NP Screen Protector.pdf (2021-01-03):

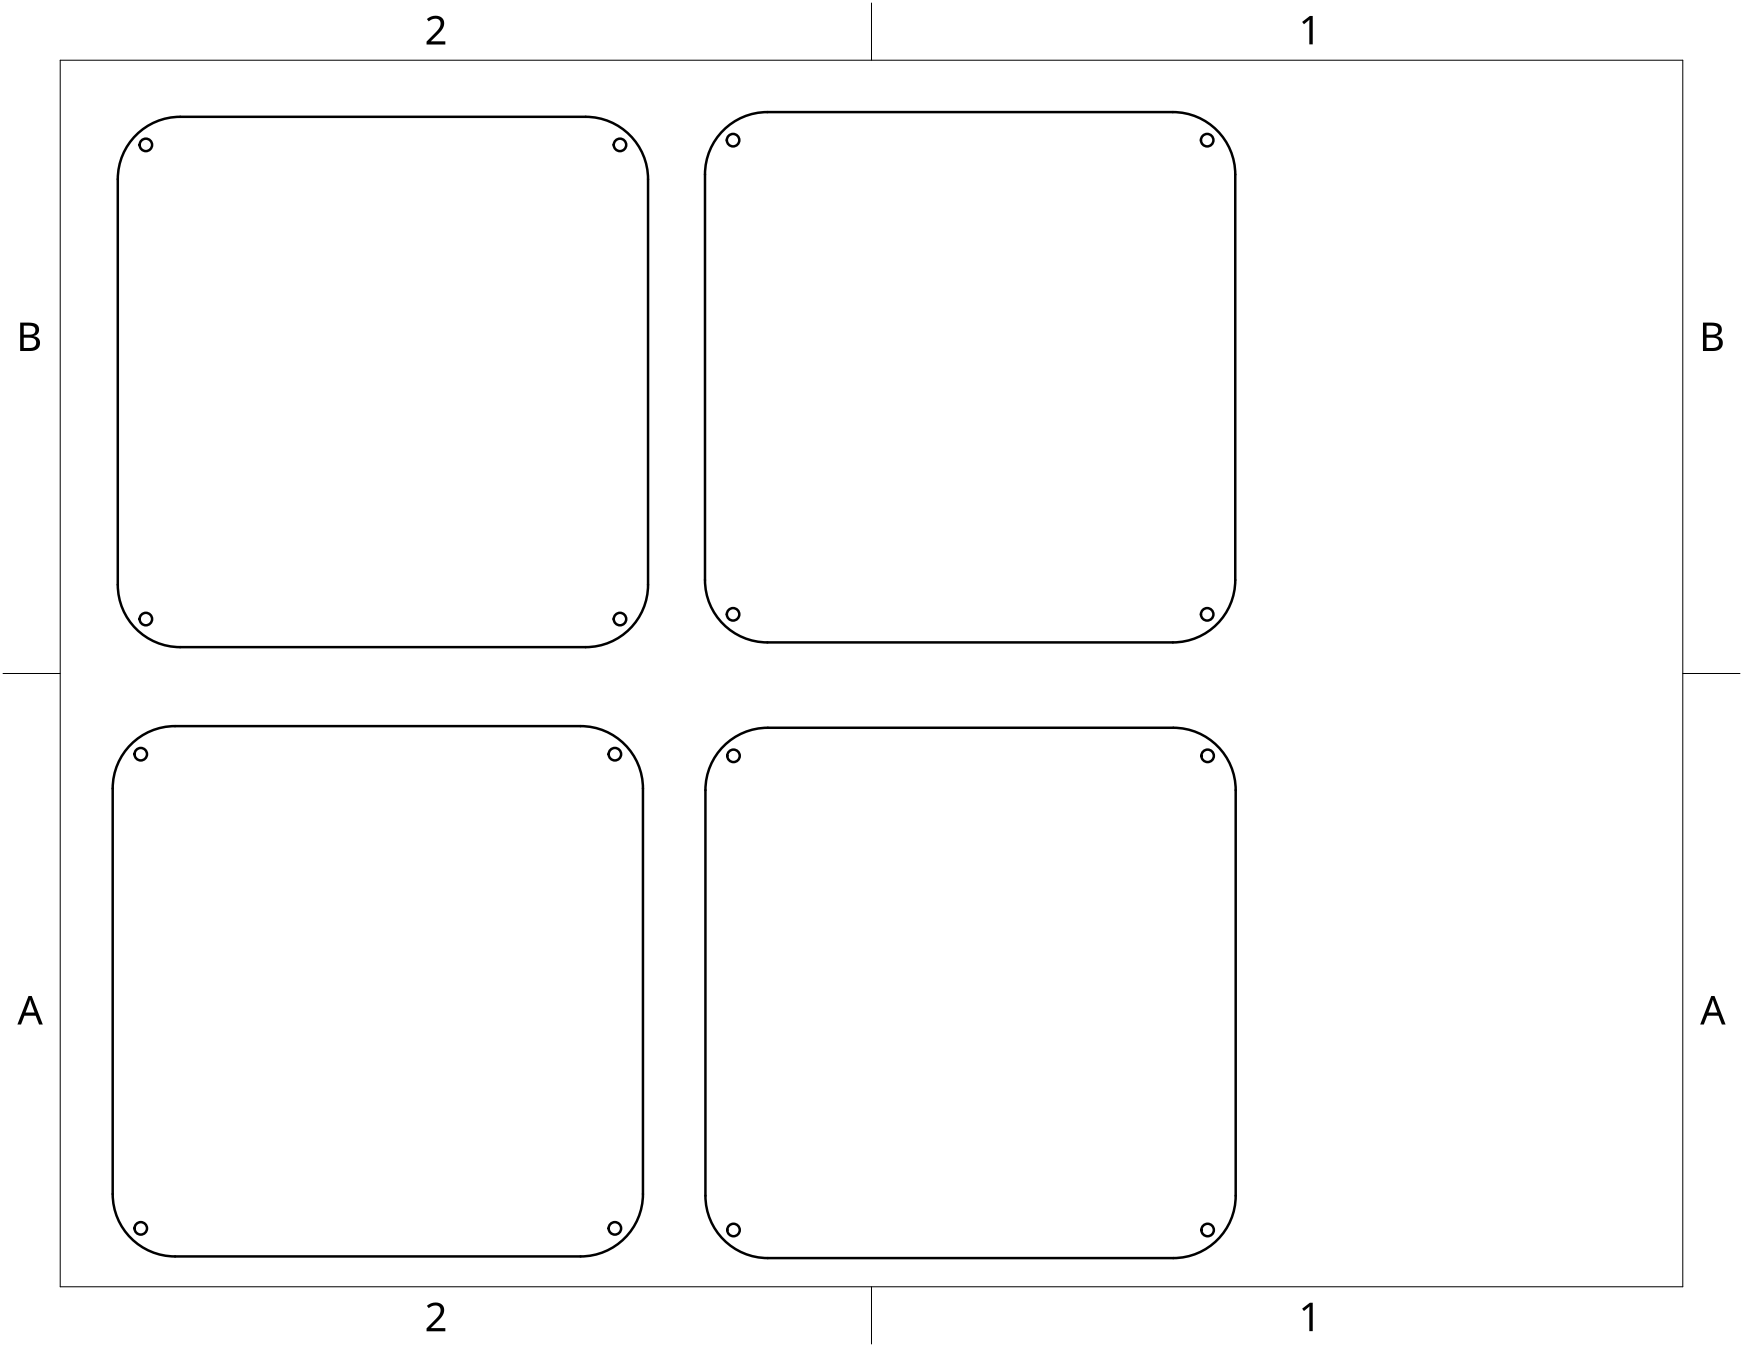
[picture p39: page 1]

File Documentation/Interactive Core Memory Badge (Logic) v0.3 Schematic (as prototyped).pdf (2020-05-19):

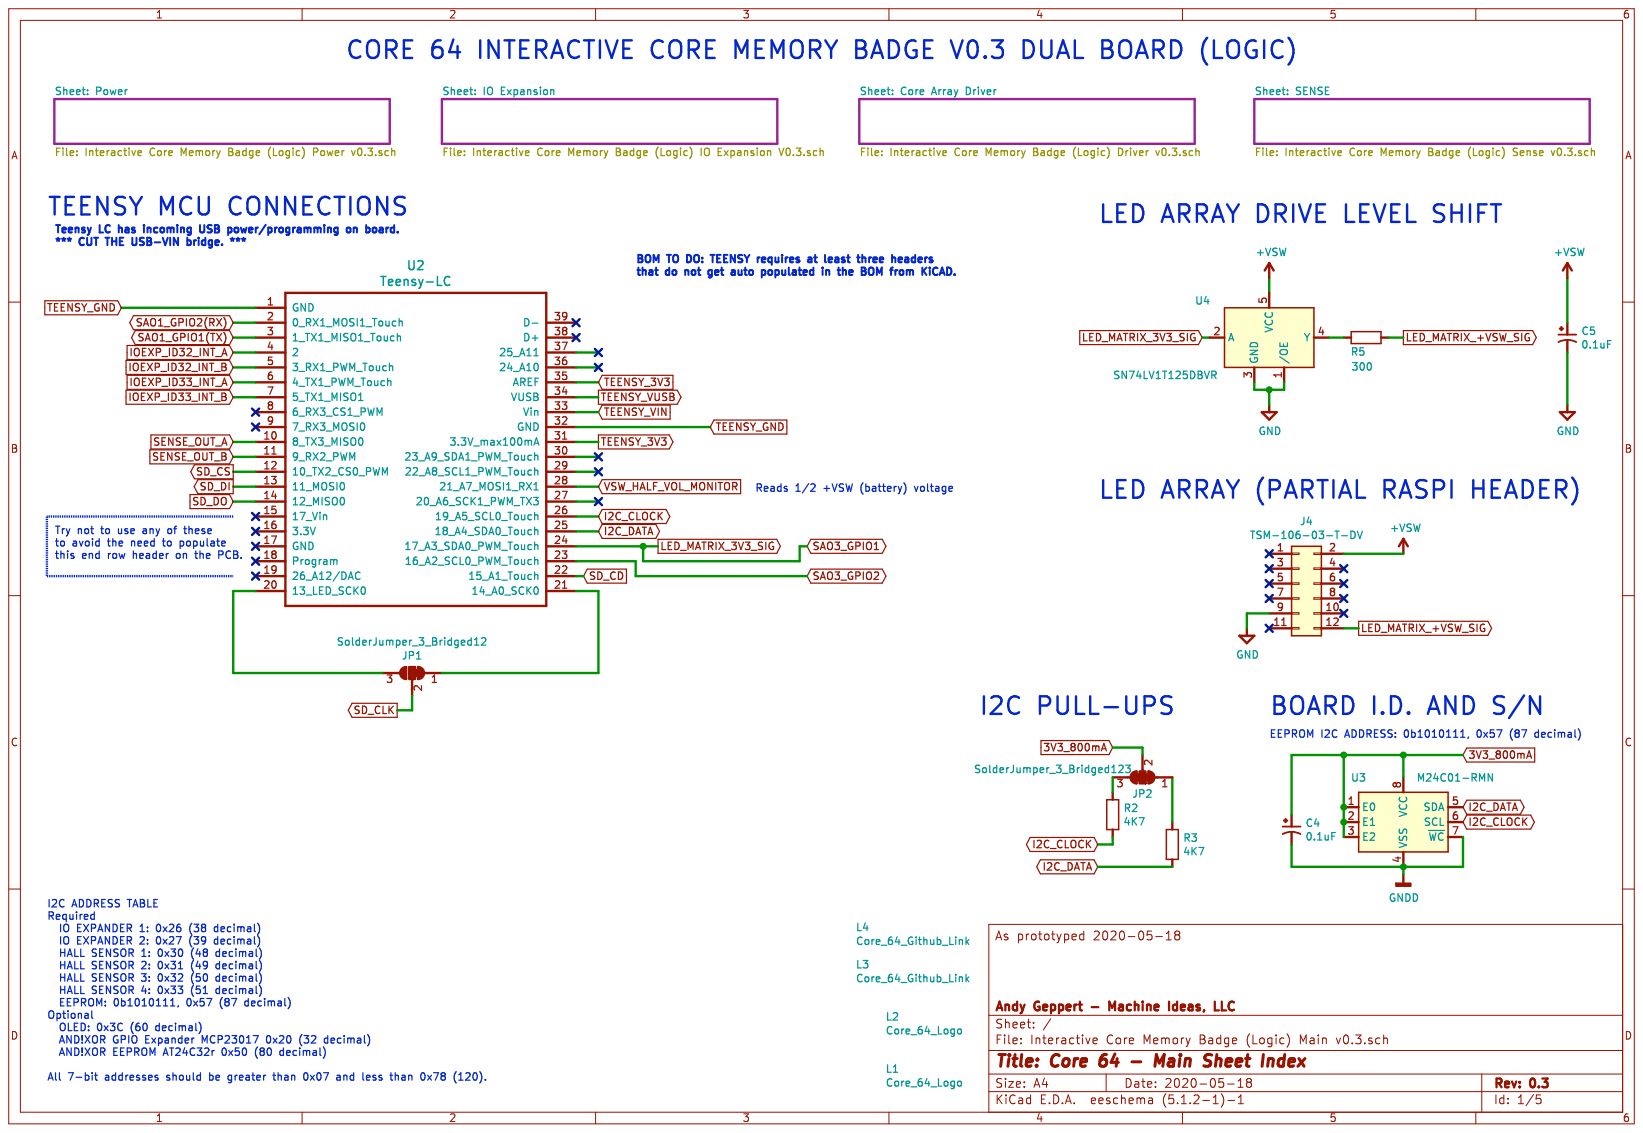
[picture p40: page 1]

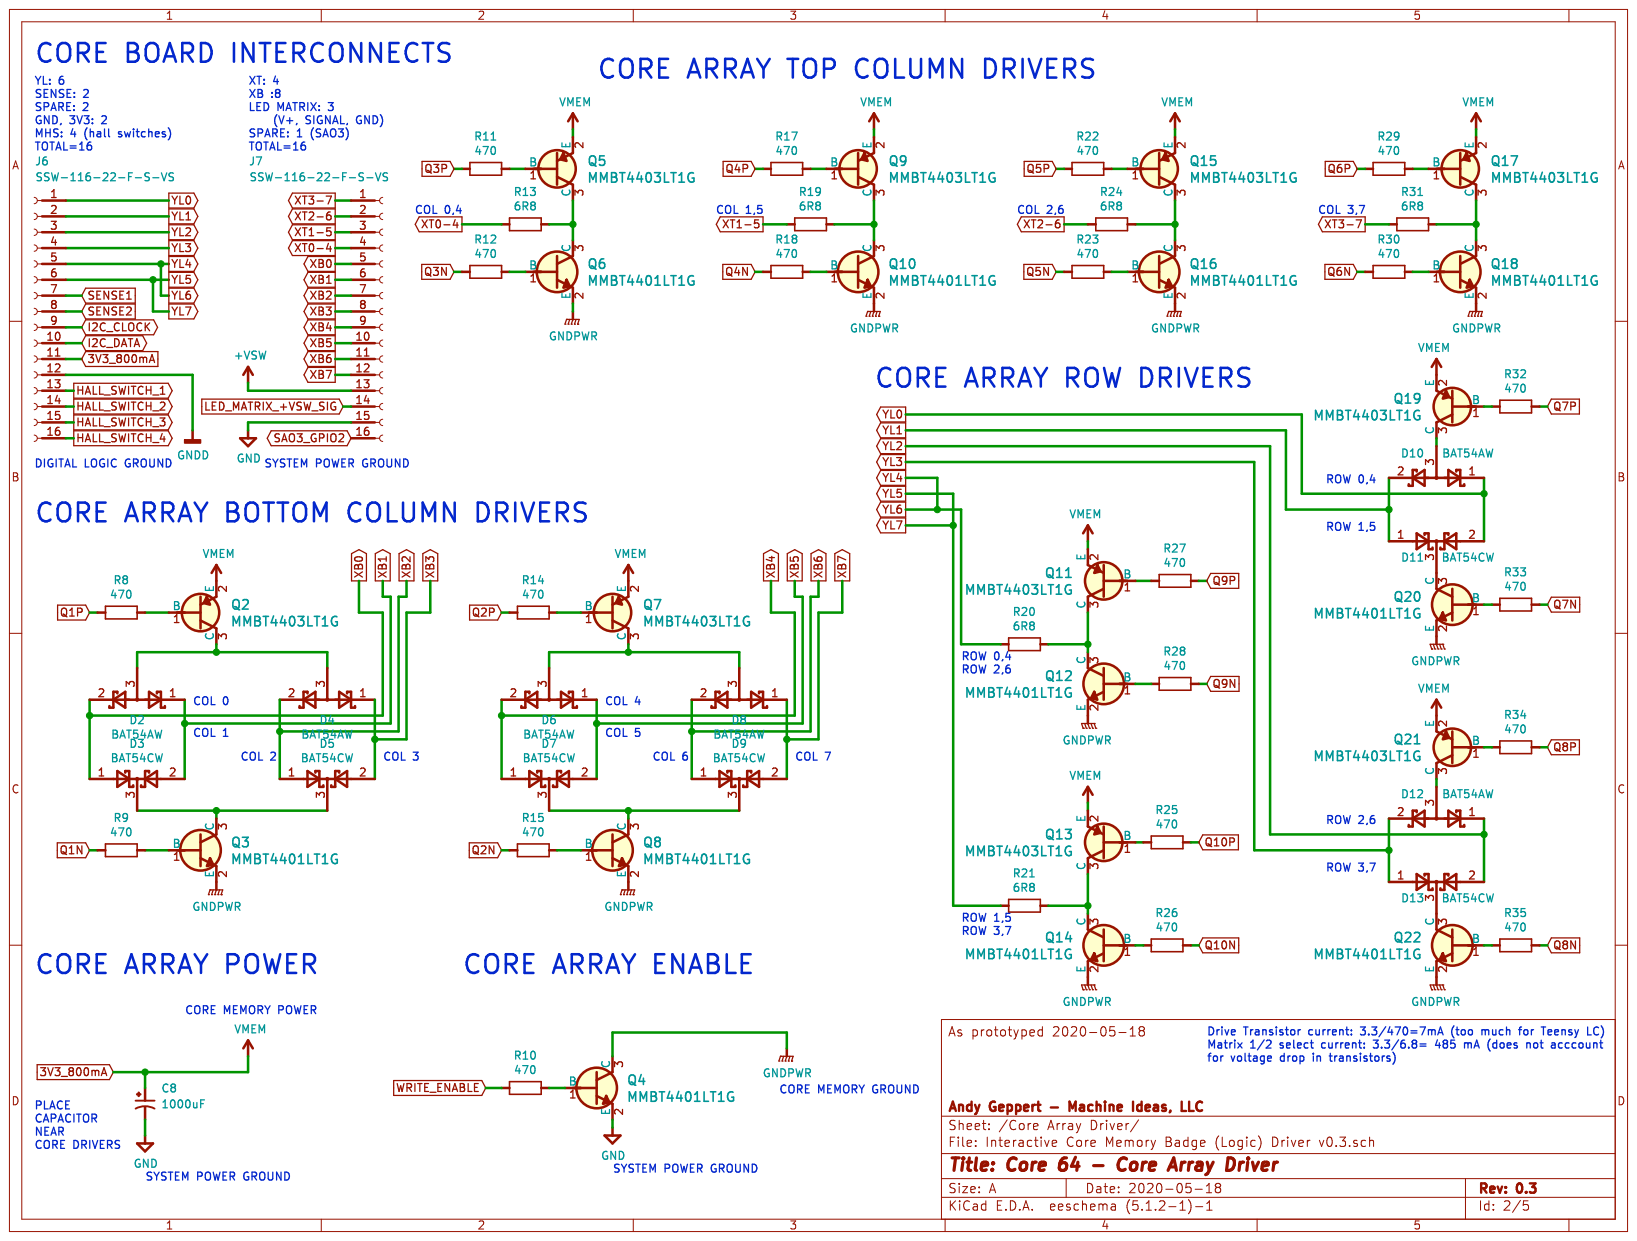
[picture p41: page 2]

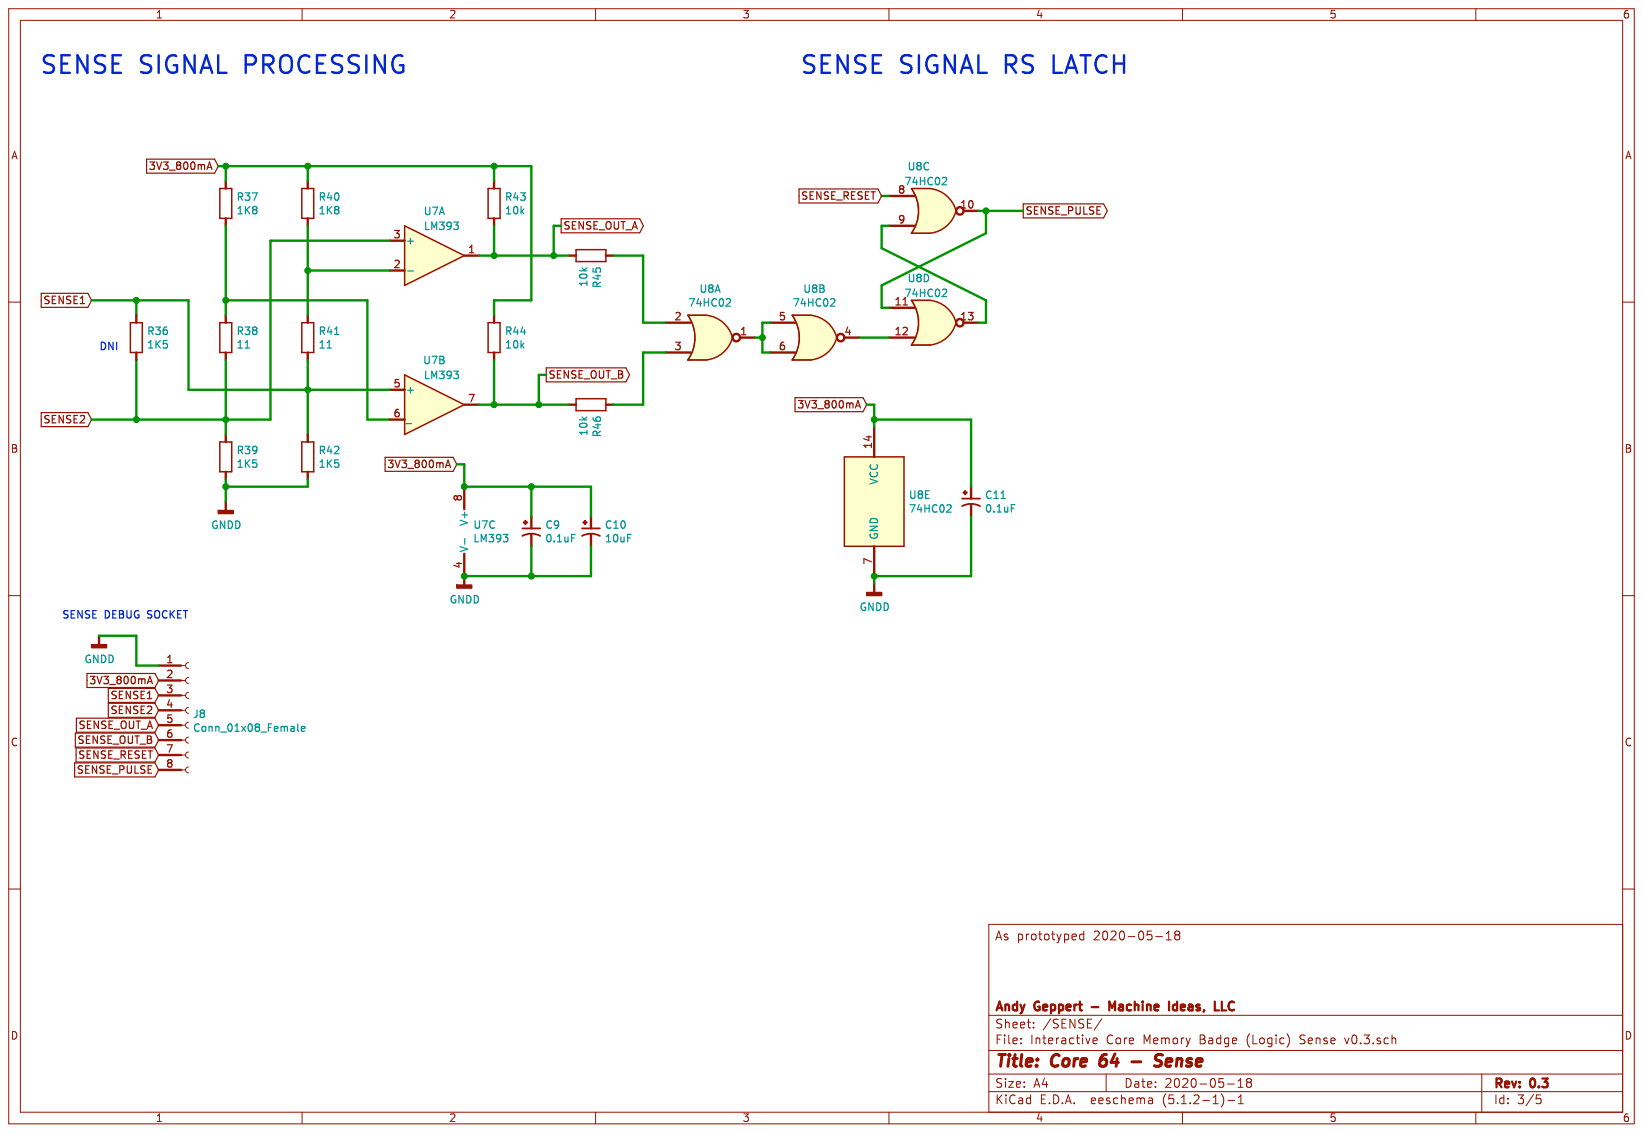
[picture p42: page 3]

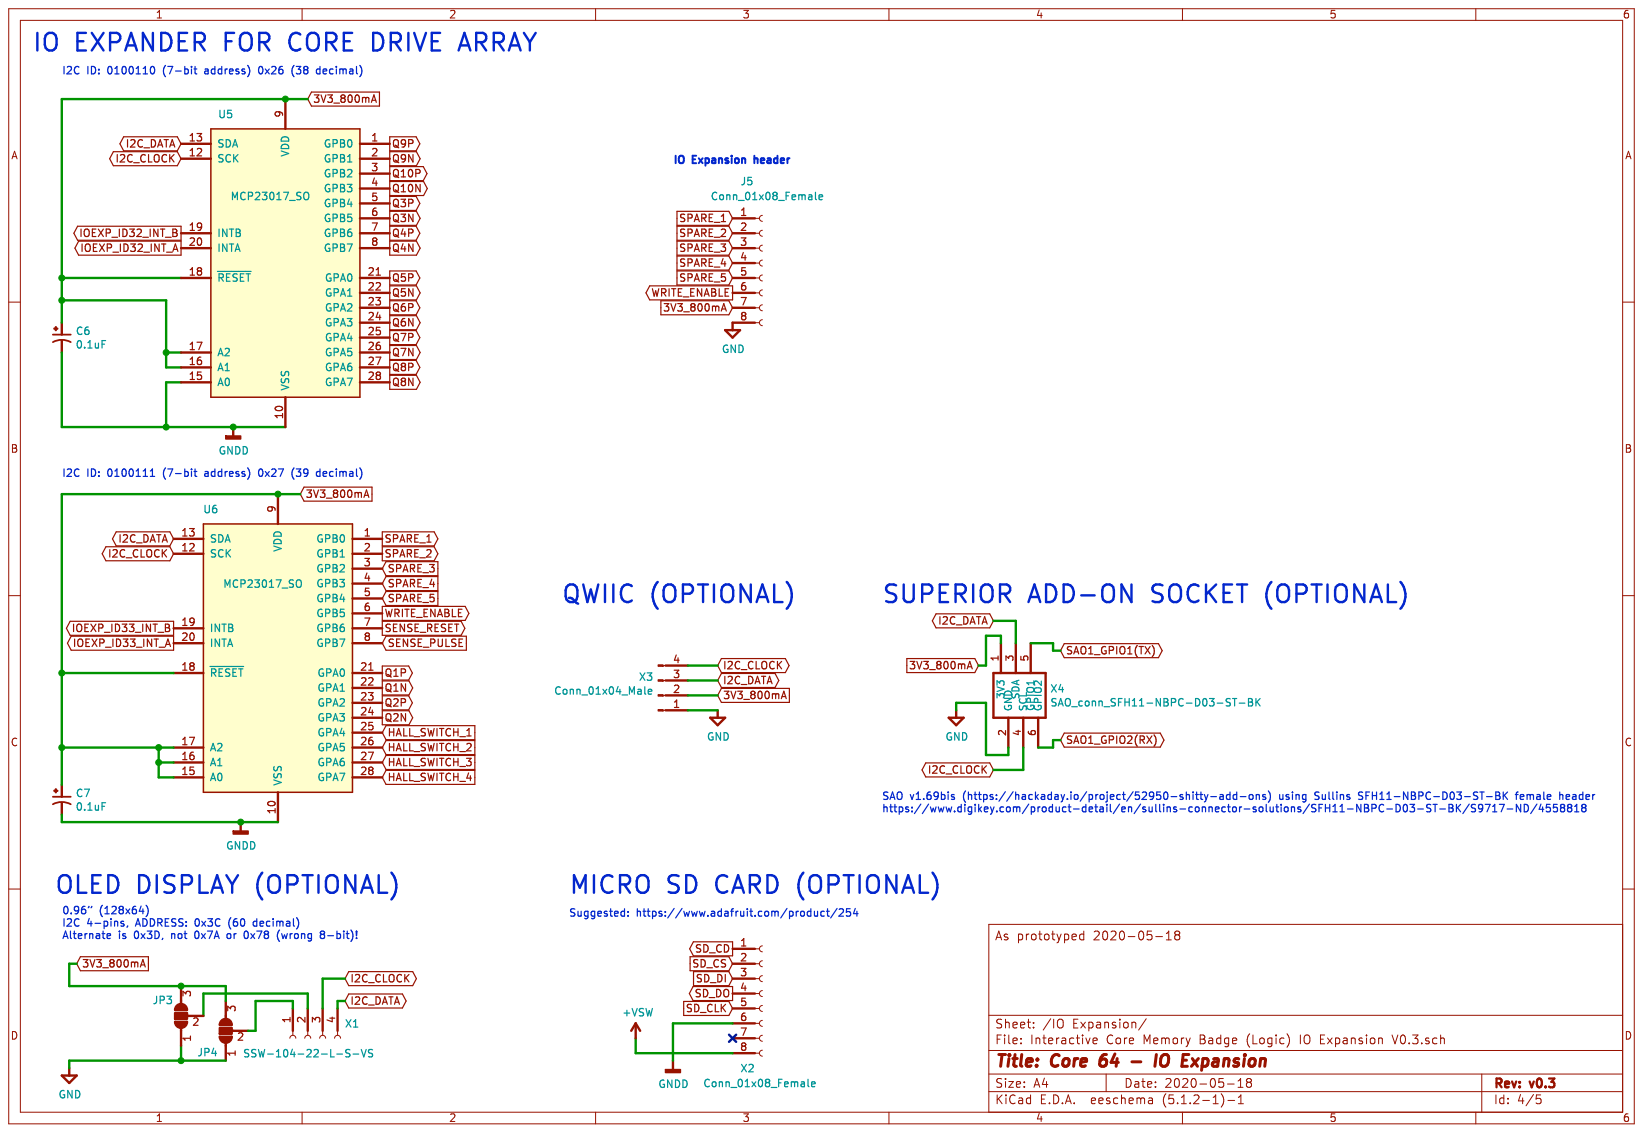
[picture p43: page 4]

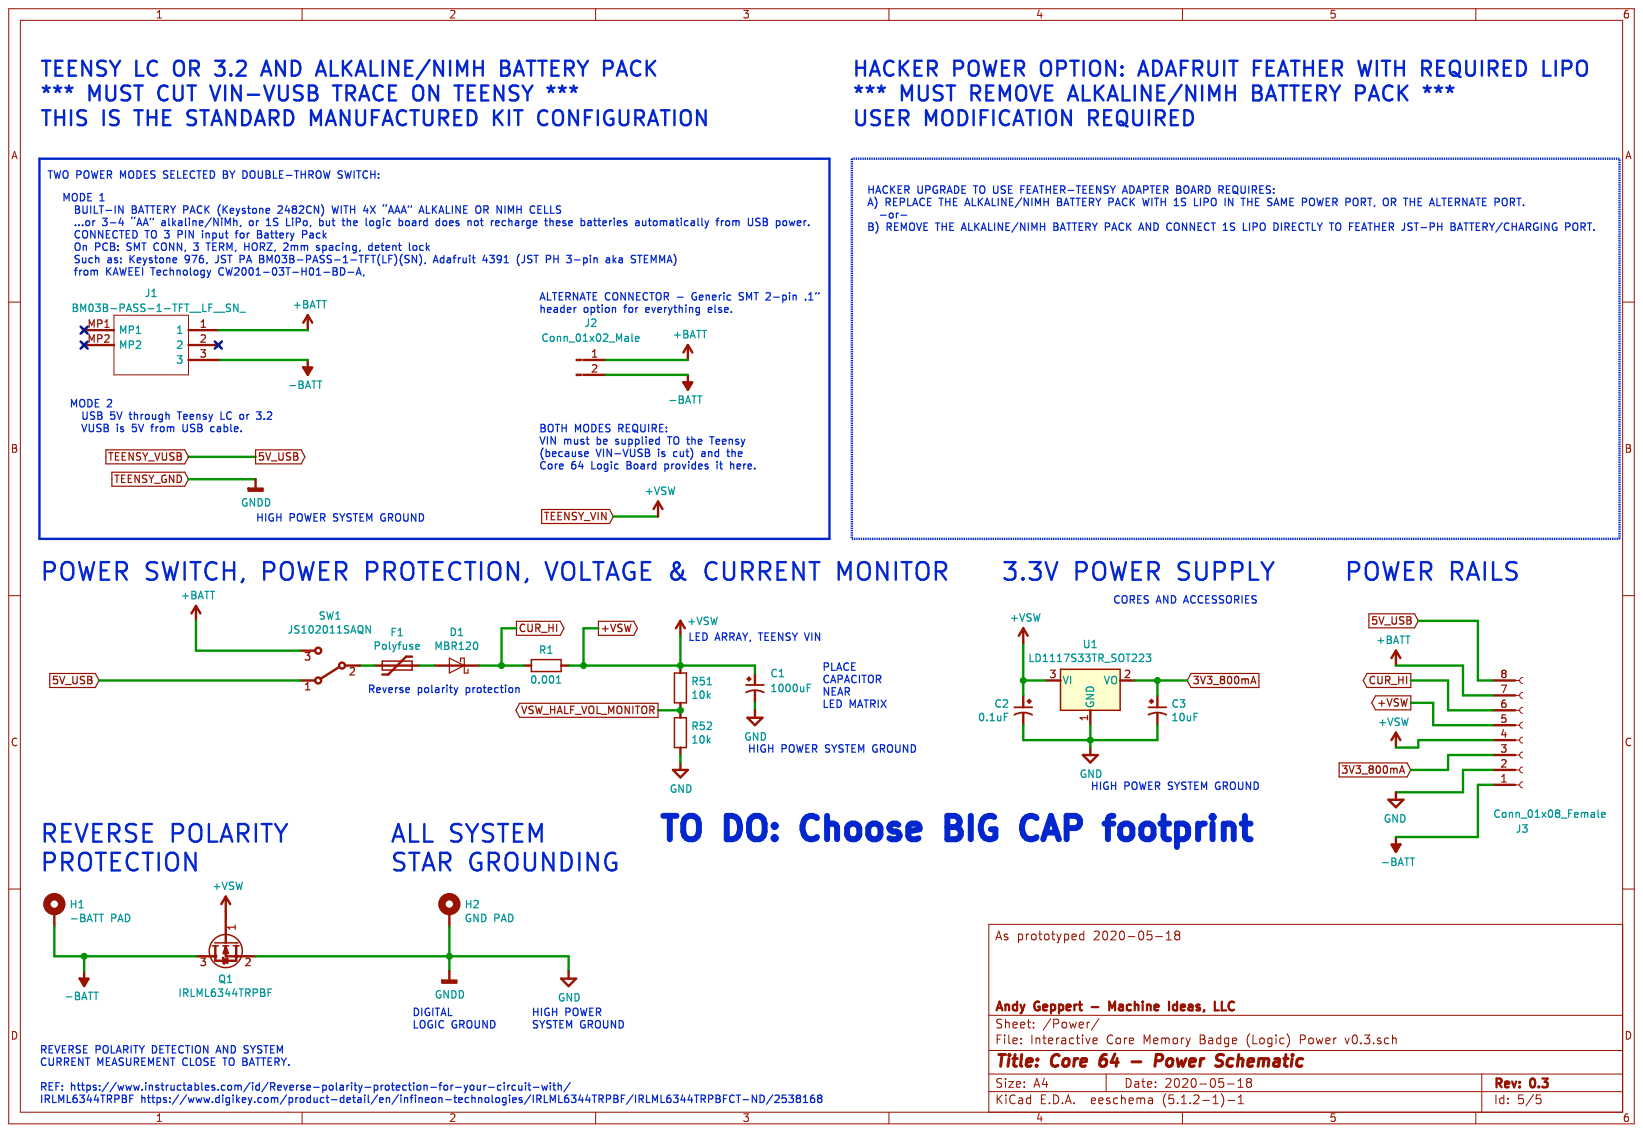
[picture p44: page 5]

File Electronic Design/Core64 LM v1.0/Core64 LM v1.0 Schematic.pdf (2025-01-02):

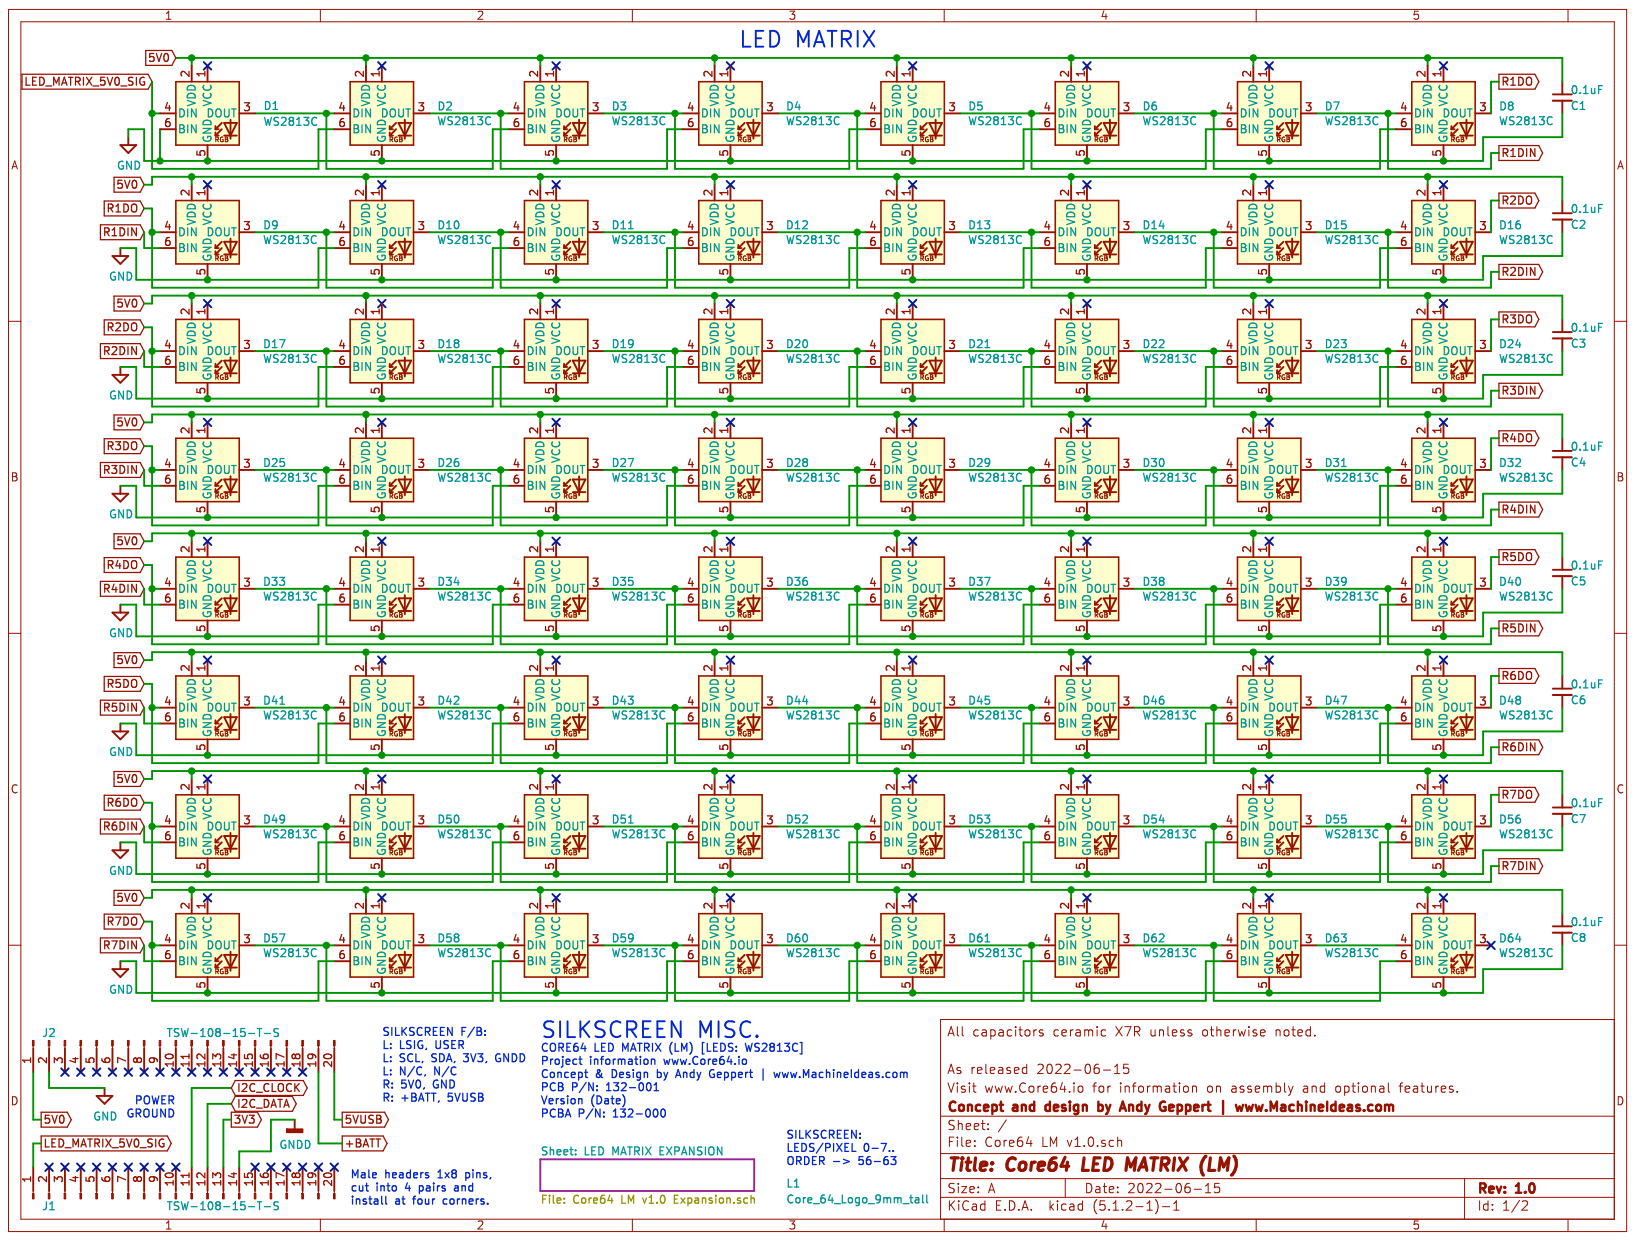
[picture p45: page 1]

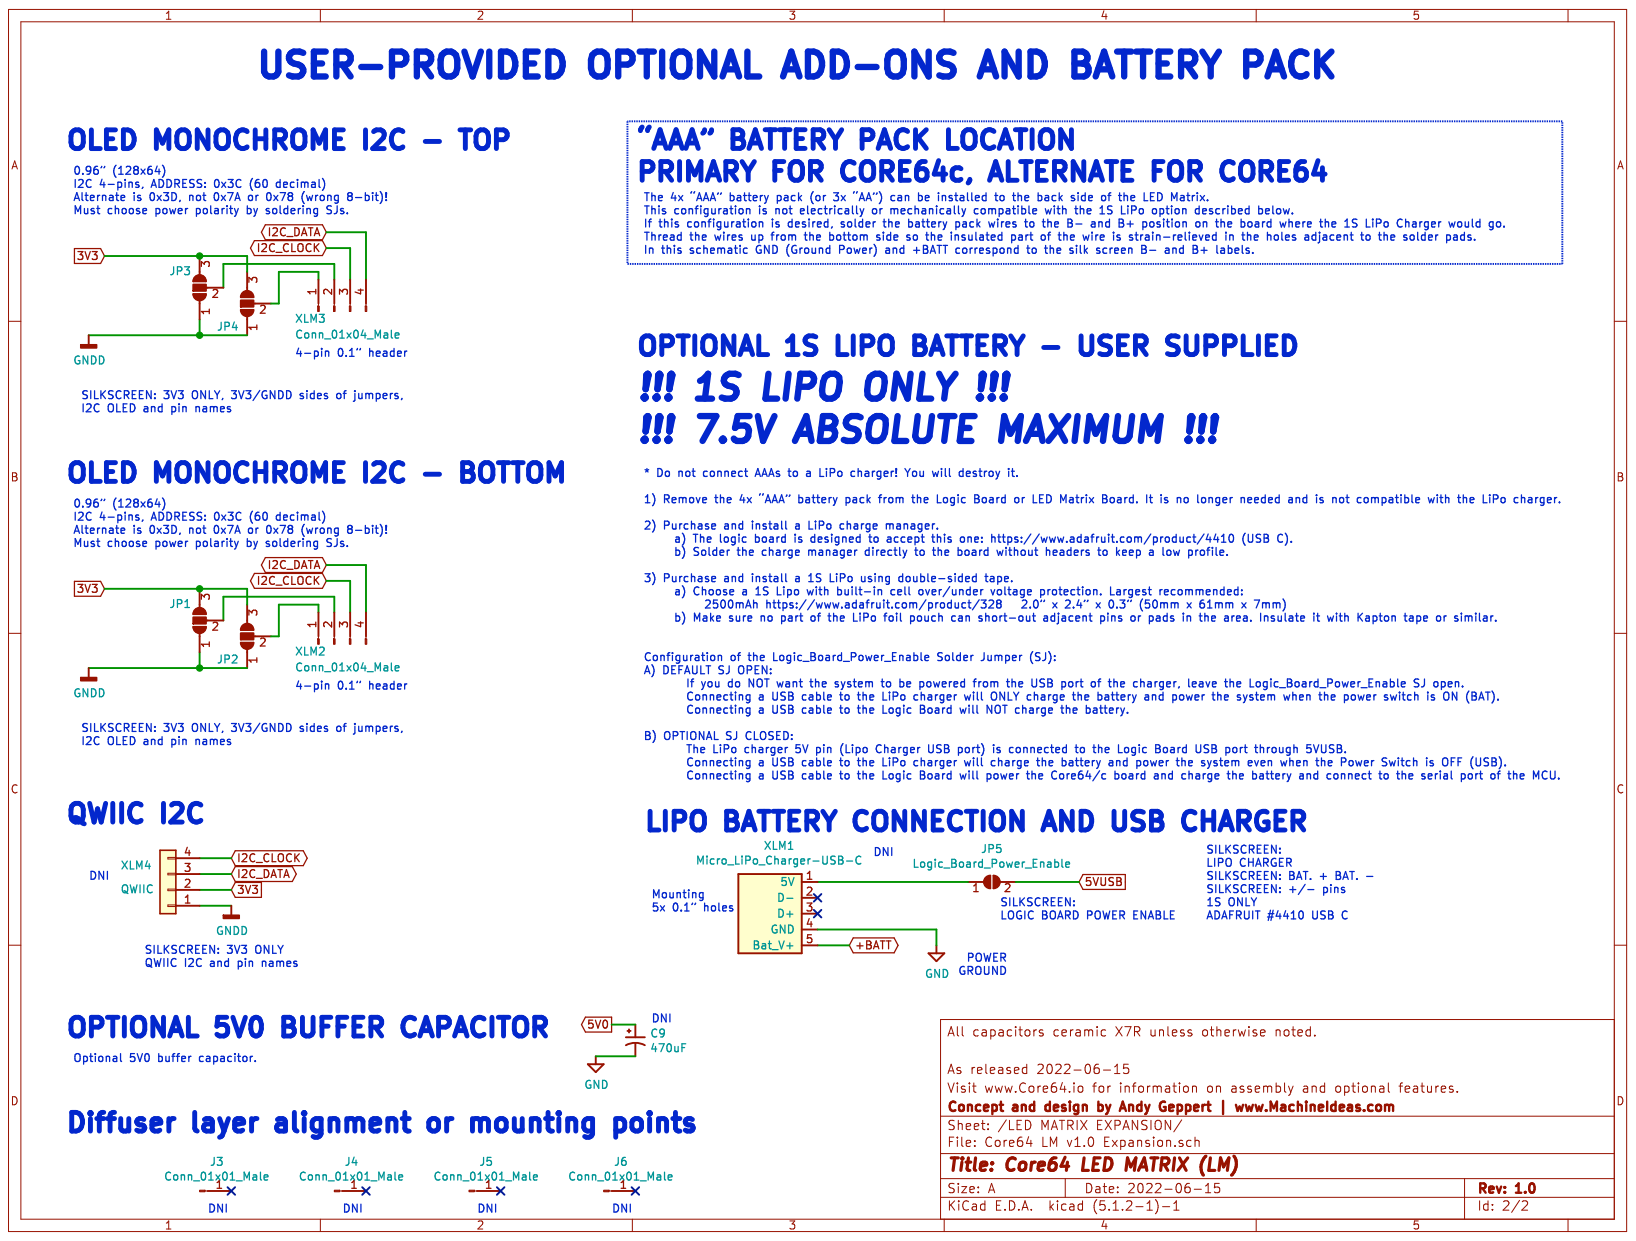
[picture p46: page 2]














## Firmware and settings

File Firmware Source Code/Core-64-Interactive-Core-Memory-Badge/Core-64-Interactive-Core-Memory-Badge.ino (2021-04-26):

/*
    ____                __   _  _   
   / ___|___  _ __ ___ / /_ | || |  
  | |   / _ \| '__/ _ \ '_ \| || |_ 
  | |__| (_) | | |  __/ (_) |__   _|
   \____\___/|_|  \___|\___/   |_|  
                                  
  Core64 Interactive Core Memory - Project website: www.Core64.io
  2019-2021 Concept and Design by Andy Geppert of www.MachineIdeas.com
  Microcontroller Board is Teensy 3.2 with hardware version and details in HardwareIOMap.h
  This source code: https://www.github.com/ageppert/Core64
  
  DEVELOPMENT ENVIRONMENT
    Arduino IDE 1.8.9               https://www.arduino.cc/en/Main/Software
    TEENSYDUINO LOADER 1.53         https://www.pjrc.com/teensy/td_download.html
      Select ALL additional libraries during installation of Teensyduino Loader and associate with the Arduino 1.8.9 installation.

  LIBRARY DEPENDENCIES
    USER MUST INSTALL MANUALLY IN ARDUINO
      Arduino > Tools > Manage Libraries > Install
      The libraries should end up being in your "Libraries" folder in your default Arduino Sketchbook location.
      Adafruit_SSD1306                              2.2.0   by Adafruit for Monochrome OLED 128x64 and 128x32
      Adafruit_GFX_Library                          1.10.6  by Adafruit
      Adafruit_BusIO                                1.3.1   by Adafruit
    TEENSYDUINO LOADER 1.53 INSTALLED THESE
      Wire                                          1.0     in Arduino1.8.9.app/Contents/Java/hardware/teensy/avr/libraries/Wire/
      EEPROM                                        2.0     in Arduino1.8.9.app/Contents/Java/hardware/teensy/avr/libraries/EEPROM/
      FastLED                                       3.3.3   in Arduino1.8.9.app/Contents/Java/hardware/teensy/avr/libraries/FastLED by Daniel Garcia
      SPI                                           1.0     in Arduino1.8.9.app/Contents/Java/hardware/teensy/avr/libraries/SPI/
    INCLUDED IN THIS PROJECT'S SRC DIRECTORY
      Si7210
      LTR329
      NeonPixel
    OPTIONAL STUFF IF YOU ADD THIS HARDWARE
      Adafruit ILI9341 Library                      1.5.6   by Adafruit
      Adafruit_SSD1327                              1.0.0   by Adafruit for Monochrome OLED 128x128
      Adafruit_SSD1351                              1.2.7   by Adafruit for Color OLED 1.27" and 1.5" in the Adafruit shop
      SdFat - Adafruit Fork                         1.2.3   by Bill Greiman (fork of SdFat)
      SparkFun Ambient Light Sensor Arduino Library 1.0.3   by Ellas Santistevan
      TeensyView                                    1.1.0   by Sparkfun for monochrome OLED 128x32 in the Sparkfun store
 */

#include <stdint.h>
#include <stdbool.h>

#include "HardwareIOMap.h"
#include "Heart_Beat.h"
#include "Serial_Debug.h"
#include "LED_Array_HAL.h"
#include "Neon_Pixel_HAL.h"
#include "OLED_Screen.h"
#include "Analog_Input_Test.h"
#include "Buttons_HAL.h"
#include "Core_HAL.h"
#include "EEPROM_HAL.h"
#include "I2C_Manager.h"
#include "SD_Card_Manager.h"
#include "Ambient_Light_Sensor.h"

#include "Core_Driver.h"
// #define DEBUG 1

uint32_t SerialNumber = 0;          // Default value is 0 and should be non-zero if the Serial Number is valid.
bool TopLevelStateChanged = false;
enum TopLevelState                  // Master State Machine
{
  STATE_STARTUP = 0,                //   0 Start-up
  STATE_SCROLLING_TEXT,             //   1 Scrolling text at power on
  STATE_CORE_FLUX_DETECTOR,         //   2 Testing all cores and displaying core state
  STATE_MONOCHROME_DRAW,            //   3 Test LED Driver with binary values
  STATE_LED_TEST_ALL_BINARY,        //   4 Test LED Driver with binary values
  STATE_LED_TEST_ONE_STRING,        //   5 Testing LED Driver
  STATE_LED_TEST_ONE_MATRIX_MONO,   //   6 Testing LED Driver with matrix array and monochrome color
  STATE_LED_TEST_ONE_MATRIX_COLOR,  //   7 Testing LED Driver with matrix array and multi-color symbols
  STATE_TEST_EEPROM,                //   8
  STATE_LED_TEST_ALL_COLOR,         //   9 Test LED Driver with all pixels and all colors
  STATE_CORE_TOGGLE_BIT,            //  10 Test one core with one function
  STATE_CORE_TEST_ONE,              //  11 Testing core #coreToTest and displaying core state
  STATE_CORE_TEST_MANY,             //  12 Testing multiple cores and displaying core state
  STATE_HALL_TEST,                  //  13 Testing hall switch and sensor response
  STATE_LAST,                       //  14 last one, return to 0.
} ;
static uint8_t TopLevelStateDefault = STATE_STARTUP;
static uint8_t TopLevelState = TopLevelStateDefault;
uint8_t value = 0;
uint8_t a = 0;

/*                      
                          *********************
                          ***     Setup     ***
                          *********************
*/
void setup() {
  HeartBeatSetup();
  LED_Array_Init();
  SerialDebugSetup();
    Serial.begin(SERIAL_PORT_SPEED);  // Need to move this serial stuff into the Serial_Debug.c file out of here!
    LED_Array_Test_Pixel_Matrix_Color();
  EEPROM_Setup();
  delay(1500); // Wait a little bit for the serial port to connect if it's there.
    Serial.println("  ____                __   _  _   ");
    Serial.println(" / ___|___  _ __ ___ / /_ | || |  ");
    Serial.println("| |   / _ \\| '__/ _ \\ '_ \\| || |_ ");
    Serial.println("| |__| (_) | | |  __/ (_) |__   _|");
    Serial.println(" \\____\\___/|_|  \\___|\\___/   |_|  ");
    Serial.println();
    Serial.println("Core64 Interactive Core Memory - Project website: www.Core64.io");
    Serial.println("2019-2021 Concept and Design by Andy Geppert of www.MachineIdeas.com");
    Serial.println("Microcontroller Board is Teensy 3.2 with hardware version and details in HardwareIOMap.h");
    Serial.println("This source code: https://www.github.com/ageppert/Core64");
    Serial.println();
    Serial.println("Serial Debug Port Started at 115200"); // TO DO: automatically update speed
  OLEDScreenSetup();
  I2CManagerSetup();
    delay(1000);
  I2CManagerBusScan();
  DetectHardwareVersion();
  SerialNumber = EEPROMExtReadSerialNumber();
    Serial.print("Hardware Version: ");
    Serial.print(HardwareVersionMajor);
    Serial.print(".");
    Serial.print(HardwareVersionMinor);
    Serial.print(".");
    Serial.println(HardwareVersionPatch);
    Serial.print("Serial Number: ");
    Serial.println(SerialNumber);
    Serial.print("Born on: 20");
    Serial.print(EEPROMExtReadBornOnYear());
    Serial.print("-");
    Serial.print(EEPROMExtReadBornOnMonth());
    Serial.print("-");
    Serial.println(EEPROMExtReadBornOnDay());    
    Serial.print("Firmware Version: ");
    Serial.println(FIRMWAREVERSION);
    Serial.println();
  // TO DO: Most of this setup should occur after the hardware version is determined, so setup is configured appropriately
  delay(250);     // Wait a little bit to print all that serial data from above.
  AnalogSetup();
  Buttons_Setup();
  CoreSetup();
  SDCardSetup();
  AmbientLightSetup();
  Neon_Pixel_Array_Init();
}

/*                      
                          *********************
                          ***   MAIN LOOP   ***
                          *********************
*/

void loop() {
  static uint8_t ColorFontSymbolToDisplay = 2;
  static bool ButtonReleased = true;
  static uint32_t Button1HoldTime = 0;
  static uint8_t coreToTest = 0;

  /*                      *********************
                          *** Housekeepting ***
                          *********************
  */
  HeartBeat(); 
  AnalogUpdate();
  AmbientLightUpdate();
  SDCardVoltageLog(1000);
  CheckForSerialCommand();        // Press "c" to test core write and read
  #ifdef DEBUG
    Serial.println("DEBUG enabled."); // Need to abstract this debug stuff
  #endif

  /*                      ************************
                          *** User Interaction ***
                          ************************
  */

  // MODE SWITCHING
  // If button is pressed, go to next mode.
  // Must be released and pressed again for subsequent action.

  Button1HoldTime = ButtonState(1,0);
  if ( (ButtonReleased == true) && (Button1HoldTime >= 500) ){
    ButtonState(1,1); // Force a "release" after press by clearing the button hold down timer
    ButtonReleased = false;
    ColorFontSymbolToDisplay++;
    if(ColorFontSymbolToDisplay>3) { ColorFontSymbolToDisplay = 0; }
    TopLevelState++;
    TopLevelStateChanged = true; // User application has one time to use this before it is reset.

  }
  else {
    if (Button1HoldTime == 0) {
      ButtonReleased = true;
      TopLevelStateChanged = false;
    }
  }

  switch(TopLevelState)
  {
  case STATE_STARTUP:
    TopLevelState++;
    break;

  case STATE_SCROLLING_TEXT:
    LED_Array_Monochrome_Set_Color(140,255,255);
    ScrollTextToCoreMemory();   // This writes directly to the RAM core memory array and bypasses reading it.
    Core_Mem_Array_Write();     // Transfer from RAM Core Memory Array to physical core memory
    Core_Mem_Array_Read();      // Transfer from physical core memory to RAM Core Memory Array
    CopyCoreMemoryToMonochromeLEDArrayMemory();
    LED_Array_Matrix_Mono_Display();
    delay(25);
    OLEDSetTopLevelState(TopLevelState);
    OLEDScreenUpdate();
    #ifdef NEON_PIXEL_ARRAY
      Neon_Pixel_Array_Matrix_Mono_Display();
      CopyCoreMemoryToMonochromeNeonPixelArrayMemory();
    #endif
    TopLevelStateChanged = false;
    break;

  case STATE_CORE_FLUX_DETECTOR:                         // Read 64 cores 10ms (110us 3x core write, with 40us delay 64 times), update LEDs 2ms
    LED_Array_Monochrome_Set_Color(50,255,255);
    LED_Array_Memory_Clear();
    for (coreToTest = 0; coreToTest < 64 ; coreToTest++) {   
      Core_Mem_Bit_Write(coreToTest,1);                     // default to bit set
      if (Core_Mem_Bit_Read(coreToTest)==true) {
        LED_Array_String_Write(coreToTest, 1);
        #ifdef NEON_PIXEL_ARRAY
          Neon_Pixel_Array_String_Write(coreToTest, 1);
        #endif
        }
      else { 
        LED_Array_String_Write(coreToTest, 0); 
        #ifdef NEON_PIXEL_ARRAY
          Neon_Pixel_Array_String_Write(coreToTest, 0);
        #endif
        }
      delayMicroseconds(40); // This 40us delay is required or LED array, first 3-4 pixels in the electronic string, get weird! RF?!??
    }
    LED_Array_String_Display();
    #ifdef NEON_PIXEL_ARRAY
      Neon_Pixel_Array_Matrix_String_Display();
    #endif
    OLEDSetTopLevelState(TopLevelState);
    OLEDScreenUpdate();
    TopLevelStateChanged = false;
    break;

  case STATE_MONOCHROME_DRAW:       // Simple drawing mode
    // Monitor cores for changes. 
      Core_Mem_Monitor();
    // Which cores changed state?
    // Add selected color to that pixel in the LED Array.
    for (uint8_t y=0; y<8; y++)
    {
      for (uint8_t x=0; x<8; x++)
      {
        if (CoreArrayMemory [y][x]) { 
          LED_Array_Matrix_Mono_Write(y, x, 1);
          #ifdef NEON_PIXEL_ARRAY
            Neon_Pixel_Array_Matrix_Mono_Write(y, x, 1);
          #endif
        }
      }
    }
    // Quick touch of the hall sensor clears the screen.
    if ( (ButtonReleased) && (ButtonState(1,0) > 50 ) ) { 
      LED_Array_Memory_Clear(); 
      #ifdef NEON_PIXEL_ARRAY
        Neon_Pixel_Array_Memory_Clear();
      #endif
    }
    // If this was the first time into this state, set default screen to be 0xDEADBEEF and 0xC0D3C4FE
    if (TopLevelStateChanged)
    {
      LED_Array_Monochrome_Set_Color(0,255,255);      // Hue 0 = RED
      LED_Array_Binary_Write_Default();
      LED_Array_Binary_To_Matrix_Mono();
      #ifdef NEON_PIXEL_ARRAY
        Neon_Pixel_Array_Binary_Write_Default();
        Neon_Pixel_Array_Binary_To_Matrix_Mono();
      #endif
      OLEDScreenClear();
    }
    LED_Array_Matrix_Mono_Display();                  // Show the updated LED array.
    LED_Array_Matrix_Mono_to_Binary();                // Convert whatever is in the LED Matrix Array to a 64-bit binary value...
    OLEDSetTopLevelState(TopLevelState);
    OLED_Show_Matrix_Mono_Hex();                      // ...and display it on the OLED.
    #ifdef NEON_PIXEL_ARRAY
      Neon_Pixel_Array_Matrix_Mono_Display();
    #endif
    TopLevelStateChanged = false;
    break;

  case STATE_LED_TEST_ALL_BINARY: // Counts from lower right and left/up in binary.
    LED_Array_Test_Count_Binary();
    OLEDSetTopLevelState(TopLevelState);
    OLEDScreenUpdate();
    // Uncomment next line to skip out of this test state immediately
    // TopLevelState = STATE_LAST;
    break;

  case STATE_LED_TEST_ONE_STRING: // Turns on 1 pixel, sequentially, from left to right, top to bottom using 1D string addressing
    LED_Array_Test_Pixel_String();
    OLEDSetTopLevelState(TopLevelState);
    OLEDScreenUpdate();
    break;

  case STATE_LED_TEST_ONE_MATRIX_MONO: // Turns on 1 pixel, sequentially, from left to right, top to bottom using 2D matrix addressing
    LED_Array_Test_Pixel_Matrix_Mono();
    OLEDSetTopLevelState(TopLevelState);
    OLEDScreenUpdate();
    break;

  case STATE_LED_TEST_ONE_MATRIX_COLOR: // Multi-color symbols
    LED_Array_Test_Pixel_Matrix_Color();
    OLEDSetTopLevelState(TopLevelState);
    OLEDScreenUpdate();
    break;

  case STATE_TEST_EEPROM: // 
    value = EEPROM_Hardware_Version_Read(a);
    Serial.print(a);
    Serial.print("\t");
    Serial.print(value);
    Serial.println();
    a = a + 1;
    if (a == 128) {
      a = 0;
    }
    delay(100);
    break;
    
  case STATE_LED_TEST_ALL_COLOR: // FastLED Demo of all color
    LED_Array_Test_Rainbow_Demo();
    OLEDSetTopLevelState(TopLevelState);
    OLEDScreenUpdate();
    break;

  case STATE_CORE_TOGGLE_BIT:     // Just toggle a single bit on and off. Or just pulse on.
    coreToTest=0;
    LED_Array_Monochrome_Set_Color(50,255,255);
    for (uint8_t bit = coreToTest; bit<(coreToTest+1); bit++)
      {
        // IOESpare1_On();
        Core_Mem_Bit_Write(bit,0);
        LED_Array_String_Write(bit,0);
        LED_Array_String_Display();
        // IOESpare1_Off();
        // delay(5);

        // IOESpare1_On();
        Core_Mem_Bit_Write(bit,1);
        LED_Array_String_Write(bit,1);
        LED_Array_String_Display();
        // IOESpare1_Off();
        // delay(50);
      }

    OLEDSetTopLevelState(TopLevelState);
    OLEDScreenUpdate();
    break;

  case STATE_CORE_TEST_ONE:
    coreToTest=0;
    LED_Array_Monochrome_Set_Color(100,255,255);
    LED_Array_Memory_Clear();
    //LED_Array_String_Write(coreToTest,1);               // Default to pixel on
    //  TracingPulses(1);
    // Core_Mem_Bit_Write(coreToTest,0);                     // default to bit set
    Core_Mem_Bit_Write(coreToTest,1);                     // default to bit set
    //  TracingPulses(2);
    if (Core_Mem_Bit_Read(coreToTest)==true) {LED_Array_String_Write(coreToTest, 1);}
    else { LED_Array_String_Write(coreToTest, 0); }
    //  TracingPulses(1);
    // delay(10);
    LED_Array_String_Display();
    OLEDSetTopLevelState(TopLevelState);
    OLEDScreenUpdate();
    delay(10);
    break;

  case STATE_CORE_TEST_MANY:
    coreToTest=0;
    for (uint8_t bit = coreToTest; bit<(64); bit++)
      {
      LED_Array_Monochrome_Set_Color(100,255,255);
      LED_Array_Memory_Clear();
      //LED_Array_String_Write(coreToTest,1);               // Default to pixel on
      //  TracingPulses(1);
      // Core_Mem_Bit_Write(coreToTest,0);                     // default to bit set
      Core_Mem_Bit_Write(bit,1);                     // default to bit set
      //  TracingPulses(2);
      if (Core_Mem_Bit_Read(bit)==true) {LED_Array_String_Write(bit, 1);}
      else { LED_Array_String_Write(bit, 0); }
      //  TracingPulses(1);
      // delay(10);
      LED_Array_String_Display();
      }
    OLEDSetTopLevelState(TopLevelState);
    OLEDScreenUpdate();
    break;

  case STATE_HALL_TEST:
    LED_Array_Monochrome_Set_Color(25,255,255);
    LED_Array_Memory_Clear();

    // IOESpare1_On();
    if(ButtonState(1,0)) { LED_Array_String_Write(57,1); Serial.println(ButtonState(1,0)); }
    if(ButtonState(2,0)) { LED_Array_String_Write(59,1); Serial.println(ButtonState(2,0)); }
    if(ButtonState(3,0)) { LED_Array_String_Write(61,1); Serial.println(ButtonState(3,0)); }
    if(ButtonState(4,0)) { LED_Array_String_Write(63,1); Serial.println(ButtonState(4,0)); }
    // IOESpare1_Off();

    LED_Array_String_Display();
    OLEDSetTopLevelState(TopLevelState);
    OLEDScreenUpdate();
  
    break;

  case STATE_LAST:
    LED_Array_Memory_Clear();
    LED_Array_Matrix_Mono_Display();
    LED_Array_Monochrome_Set_Color(125,255,255);
    OLEDSetTopLevelState(TopLevelState);
    OLEDScreenUpdate();
    TopLevelState = STATE_STARTUP;   
    break;

  default:
    Serial.println("Invalid TopLevelState");
    break;
  }

}

void coreTesting() {
  static uint8_t BitToTest = 63;
  /*
  static uint8_t c = 0;
  for (uint8_t i = 1; i <=2; i++)
  {
    CoreWriteBit(c,0); CoreWriteBit(c,1);
  }
  c++;
  if (c == 64) {c=0;}
  */
  // Read testing
  Core_Mem_Bit_Write(BitToTest,1);
  LED_Array_String_Write(BitToTest,1);
  LED_Array_String_Display();
  delay(1000);
  Core_Mem_Bit_Write(BitToTest,0);
  LED_Array_String_Write(BitToTest,0);
  LED_Array_String_Display();
  // CoreArrayMemory [0][3] = CoreReadBit(3);
  // Whole Array Testing
  //  for (uint8_t i = 0; i <= 63; i++ ) { CoreWriteBit(i,1); }
  //  for (uint8_t i = 0; i <= 63; i++ ) { CoreWriteBit(i,0); }
  // Column Testing
  // for (uint8_t i = 1; i <= 63; i=i+8 ) { CoreWriteBit(i,0); CoreWriteBit(i,1); }
  //for (uint8_t i = 0; i <= 7; i++ ) { CoreWriteBit(i,1); }
  // Row Testing
  // for (uint8_t i = 0; i <= 63; i=i+8 ) { CoreWriteBit(i,1); }
  // for (uint8_t i = 0; i <= 63; i=i+8 ) { CoreWriteBit(i,0); }
  /*
  CoreWriteBit(0,1);
  CoreWriteBit(0,1);
  CoreWriteBit(0,0);
  CoreWriteBit(7,1);
  CoreWriteBit(7,1);
  CoreWriteBit(0,0);
  //CoreReadBit(0);
  //CoreClearAll();
  */
}

void CheckForSerialCommand() {
  char c;
  if(Serial.available() > 0)
  {
    c = Serial.read();
    Serial.write(c);
    Serial.println();
    switch(c)
    {
    case 'c':
      Serial.println();
      Serial.println("coreTest");
      coreTesting();
      break;

    default:
      Serial.print("Ignoring unknown command: ");
      Serial.println(c);
    }
  }
}

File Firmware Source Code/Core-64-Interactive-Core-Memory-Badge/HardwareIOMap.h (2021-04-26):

/*
	PURPOSE: Define/assign/log the version scheme and number.
				Map out all of the IO for each version of the Core 64 hardware.
         		The Hardware_IO_Map.cpp file detects and sets the hardware version.
         		Specify firmware version manually in this file as a string.
	SETUP: Manually update the field assigned as VERSION


  	HARDWARE VERSION SCHEME (see https://semver.org/)
		Given a version number MAJOR.MINOR.PATCH, increment the:
			MAJOR version when you make incompatible API changes,
			MINOR version when you add functionality in a backwards compatible manner, and
			PATCH version when you make backwards compatible bug fixes.
	
	FIRMWARE VERSION SCHEME 
	    Same as hardware version scheme, with additional metadata extensions:
		    -DATE 		Example: -200101
						Two digit month, two digit day of the month
			.TIME 	    Example: |0800
						Time increments from build to build to clearly denote each unqiue iteration
*/

#ifndef HARDWARE_IO_MAP_H
#define HARDWARE_IO_MAP_H

#if (ARDUINO >= 100)
#include <Arduino.h>
#else
#include <WProgram.h>
#endif

#include <stdint.h>

#ifdef __cplusplus
extern "C" {
#endif

// #define SDCARD_ENABLE                  			// 
#define AMBIENT_LIGHT_SENSOR_LTR329_ENABLE   		// 
#define HALL_SENSOR_ENABLE							// 
// #define HALL_SWITCH_ENABLE
#define NEON_PIXEL_ARRAY							// Serpentine, like Pimoroni Unicorn Hat
#define CORE64_LED_MATRIX							// Row Major, Progressive layout. Just like an array in C.
#define OLED_64X128
// #define OLED_128X128


void DetectHardwareVersion ();		// Use once to detect and set the hardware version variables.
/*
	****************************************** HARDWARE VERSION TABLE ******************************************
	| VERSION |  DATE      | DESCRIPTION                                                                       |
	------------------------------------------------------------------------------------------------------------
	| v0.1.0  | 2019-08-09 | Single board prototype development
	| v0.1.5  | 2020-02-22 | Single board, reworked board fixes, prototype development
	| v0.2.0  | 2020-03-16 | Single board, design updated to match v0.1.5, theoretically (not produced)
	| v0.3.0  | 2020-05-30 | Dual board, hardware version detection for 0.2.x (includes v0.1.x) and v0.3.x
	| v0.3.1  | 2020-05-30 | Two voltage regulators, 5V0 and 3V3, powered from common switch point
	| v0.4.0  | 2020-11-28 | Blue LB, Yellow CB with Plane 4 set, as-built bring-up
	| v0.5.0  | 2021-03-20 | Triple-board, Black LB/CB/CM
	------------------------------------------------------------------------------------------------------------
*/
	#define FIRMWAREVERSION "210425.2003"	// TO DO: Expand to be "0.4.0-210530.1340"
/*
	****************************************** FIRMWARE VERSION TABLE ******************************************
	| VERSION |  DATE      | DESCRIPTION                                                                       |
	------------------------------------------------------------------------------------------------------------
	| v0.1.0  | 2019-      | 
	| v0.1.5  | 2020-      | 
	| v0.2.0  | 2020-      | 
	| v0.3.x  | 2020-      | 
	| v0.4.x  | 2020-11-28 | 
	| v0.5.x  | 2021-03-20 | Accept V0.5.x hardware, manual default to the custom-fit LED Matrix.
	| v0.5.x  | 2021-04-25 | Beta Kit Release
	------------------------------------------------------------------------------------------------------------
*/
	extern uint8_t HardwareVersionMajor  ;
	extern uint8_t HardwareVersionMinor  ;
	extern uint8_t HardwareVersionPatch  ;
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

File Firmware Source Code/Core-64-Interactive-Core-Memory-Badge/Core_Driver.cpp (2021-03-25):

#include <stdint.h>
#include <stdbool.h>
#if (ARDUINO >= 100)
#include <Arduino.h>
#else
#include <WProgram.h>
#endif

#include "Core_Driver.h"
#include "HardwareIOMap.h"
#include "I2C_Manager.h"

// Array from 1-20 with MCU pin # associated to verbose transitor drive line name. Ex: PIN_MATRIX_DRIVE_Q1P
// Array position number 0 is not used in the matrix pin numbering
// Matrix Drive Line array position :         0, 1, 2, 3, 4, 5, 6, 7, 8, 9,10,11,12,13,14,15,16,17,18,19,20,21,22,23,24,25,26,27,28,29,30,31,32,33
// Look out for these!              :                                                               *  *  *
// V0.3 MCU PIN #                   :       N/A, 1, 2, 3, 4, 5, 6, 7, 8, 9,10,11,12,13,14,15,16,17, -, -,20,21,22
// V0.4 MCU PIN #                   :       N/A, -, 1, 2, 3, 4, 5, 6, 7, 8, -, -, -, -, -, -, 9,10, -, -, -, -, -, -,11,12,13,14,15,16,17,20,21,22
static uint8_t MatrixDrivePinNumber[34] = {
  0,
  0,
  PIN_MATRIX_DRIVE_Q1P ,
  PIN_MATRIX_DRIVE_Q1N ,
  PIN_MATRIX_DRIVE_Q2P ,
  PIN_MATRIX_DRIVE_Q2N ,
  PIN_MATRIX_DRIVE_Q3P ,
  PIN_MATRIX_DRIVE_Q3N ,
  PIN_MATRIX_DRIVE_Q4P ,
  PIN_MATRIX_DRIVE_Q4N ,
  0,
  0,
  0,
  0,
  0,
  0,
  PIN_MATRIX_DRIVE_Q5P ,
  PIN_MATRIX_DRIVE_Q5N ,
  0,
  0,
  0,
  0,
  0,
  0,
  PIN_MATRIX_DRIVE_Q6P ,
  PIN_MATRIX_DRIVE_Q6N ,
  PIN_MATRIX_DRIVE_Q7P ,
  PIN_MATRIX_DRIVE_Q7N ,
  PIN_MATRIX_DRIVE_Q8P ,
  PIN_MATRIX_DRIVE_Q8N ,
  PIN_MATRIX_DRIVE_Q9P ,
  PIN_MATRIX_DRIVE_Q9N ,
  PIN_MATRIX_DRIVE_Q10P,
  PIN_MATRIX_DRIVE_Q10N
};

// All QxN transistors are Active High.
// All QxP transistors are Active Low.

// V0.4 hardware (direct MCU pin control)
// Look up the drive line number by knowing where it is in the array by it's own number.
// In other words, the pin # has to be the same as the array position.
// Array needs to be as big as the largest used pin number.
// Ex:
//                             array position:  0, 1, 2, 3, 4, 5, 6, 7, 8, 9,10,11,12,13,14,15,16,17,18,19,20,21,22,23,24,25,26,27,28,29,30,31,32,33
// V0.4 MCU PIN #              usable pins   :  x, x, 1, 2, 3, 4, 5, 6, 7, 8, x, x, x, x, x, x, 9,10, x, x, x, x, x, x,11,12,13,14,15,16,17,20,21,22
// MCU output pins are set to these states to correspond to activation of the transistor needed to achieve on/off state.
const bool MatrixDrivePinInactiveState[34] =  { 0, 0, 1, 0, 1, 0, 1, 0, 1, 0, 0, 0, 0, 0, 0, 0, 1, 0, 0, 0, 0, 0, 0, 0, 1, 0, 1, 0, 1, 0, 1, 0, 1, 0}; // logic level to turn off transistor
const bool MatrixDrivePinActiveState[34]   =  { 0, 0, 0, 1, 0, 1, 0, 1, 0, 1, 0, 0, 0, 0, 0, 0, 0, 1, 0, 0, 0, 0, 0, 0, 0, 1, 0, 1, 0, 1, 0, 1, 0, 1}; // logic level to turn on transistor


// MCU output pin is set to these states to correspond to activation of the transistor needed to achieve active/inactive state.
#define WRITE_ENABLE_ACTIVE   1 // logic level to turn on transistor
#define WRITE_ENABLE_INACTIVE 0 // logic level to turn off transistor

static uint8_t CorePlane = 1;           // Default Core Plane if it is not specified by the user application.
const bool CorePlaneAddr[9][3] = {
  { 0,0,0 },  // not used
  { 0,0,0 },  // Plane 1 (MSB to LSB)
  { 0,0,1 },  // Plane 2
  { 0,1,0 },  // Plane 3
  { 0,1,1 },  // Plane 4
  { 1,0,0 },  // Plane 5
  { 1,0,1 },  // Plane 6
  { 1,1,0 },  // Plane 7
  { 1,1,1 }   // Plane 8     
};

void Core_Driver_Setup() {
    pinMode(Pin_Sense_Pulse, INPUT_PULLUP);
    pinMode(Pin_Sense_Reset, OUTPUT);
    pinMode(PIN_MATRIX_DRIVE_Q1P,  OUTPUT);
    pinMode(PIN_MATRIX_DRIVE_Q1N,  OUTPUT);
    pinMode(PIN_MATRIX_DRIVE_Q2P,  OUTPUT);
    pinMode(PIN_MATRIX_DRIVE_Q2N,  OUTPUT);
    pinMode(PIN_MATRIX_DRIVE_Q3P,  OUTPUT);
    pinMode(PIN_MATRIX_DRIVE_Q3N,  OUTPUT);
    pinMode(PIN_MATRIX_DRIVE_Q4P,  OUTPUT);
    pinMode(PIN_MATRIX_DRIVE_Q4N,  OUTPUT);
    pinMode(PIN_MATRIX_DRIVE_Q5P,  OUTPUT);
    pinMode(PIN_MATRIX_DRIVE_Q5N,  OUTPUT);
    pinMode(PIN_MATRIX_DRIVE_Q6P,  OUTPUT);
    pinMode(PIN_MATRIX_DRIVE_Q6N,  OUTPUT);
    pinMode(PIN_MATRIX_DRIVE_Q7P,  OUTPUT); // Shared pin 13. Onboard LED, Hearbeat. Return to previous state when finished using.
    pinMode(PIN_MATRIX_DRIVE_Q7N,  OUTPUT);
    pinMode(PIN_MATRIX_DRIVE_Q8P,  OUTPUT);
    pinMode(PIN_MATRIX_DRIVE_Q8N,  OUTPUT);
    pinMode(PIN_MATRIX_DRIVE_Q9P,  OUTPUT); // Shared pin 17. LED Array. Return to previous state when finished using.
    pinMode(PIN_MATRIX_DRIVE_Q9N,  OUTPUT);
    pinMode(PIN_MATRIX_DRIVE_Q10P, OUTPUT);
    pinMode(PIN_MATRIX_DRIVE_Q10N, OUTPUT);
    pinMode(PIN_WRITE_ENABLE, OUTPUT);
    pinMode(Pin_SAO_G1_SPARE_1_CP_ADDR_0, OUTPUT);
    pinMode(Pin_SAO_G2_SPARE_2_CP_ADDR_1, OUTPUT);
    #ifdef Pin_SPARE_3_Assigned_To_Spare_3_Output
      pinMode(Pin_SPARE_3_CP_ADDR_2, OUTPUT);
    #endif
    #ifdef Pin_SPARE_5_Assigned_To_Spare_5_Output
      pinMode(Pin_SPI_Reset_Spare_5, OUTPUT);
    #endif
    #ifdef Pin_Spare_4_IR_IN_Assigned_To_Spare_4_Output
      pinMode(Pin_Spare_4_IR_IN, OUTPUT);
    #endif

    #ifdef Pin_SAO_G1_SPARE_1_CP_ADDR_0_Assigned_To_CP_ADDR_0_Output
     pinMode(Pin_SAO_G1_SPARE_1_CP_ADDR_0, OUTPUT);
     #define CORE_PLANE_SELECT_ACTIVE
    #endif
    #ifdef Pin_SAO_G2_SPARE_2_CP_ADDR_1_Assigned_To_CP_ADDR_1_Output
     pinMode(Pin_SAO_G2_SPARE_2_CP_ADDR_1, OUTPUT);
     #define CORE_PLANE_SELECT_ACTIVE
    #endif
    #ifdef Pin_SPARE_3_CP_ADDR_2_Assigned_To_CP_ADDR_2_Output
      pinMode(Pin_SPARE_3_CP_ADDR_2, OUTPUT);
     #define CORE_PLANE_SELECT_ACTIVE
    #endif
}

// CMMD = Core Memory Matrix Drive
// Given a Core Memory Matrix Column 0 to 7 the array below specifies which 2 pins connected to transistors are required to set the column.
// CMM front (user) view is with Column 0 on left, 7 on right.
// Each row of the array corresponds to columns 0 to 7 of the CMM.
// Each row is sequence of 2 transitors, first one is at the top and second one is at the bottom.

// Set is given the arbitrary definition of current flow upward in that column.
// Top of column connected to VMEM and bottom of column connected to GNDPWR.
uint8_t CMMDSetCol[8][2] = {
  { PIN_MATRIX_DRIVE_Q3P, PIN_MATRIX_DRIVE_Q1N },  // Column 0
  { PIN_MATRIX_DRIVE_Q4P, PIN_MATRIX_DRIVE_Q1N },  // Column 1
  { PIN_MATRIX_DRIVE_Q5P, PIN_MATRIX_DRIVE_Q1N },  // Column 2
  { PIN_MATRIX_DRIVE_Q6P, PIN_MATRIX_DRIVE_Q1N },  // Column 3
  { PIN_MATRIX_DRIVE_Q3P, PIN_MATRIX_DRIVE_Q2N },  // Column 4
  { PIN_MATRIX_DRIVE_Q4P, PIN_MATRIX_DRIVE_Q2N },  // Column 5
  { PIN_MATRIX_DRIVE_Q5P, PIN_MATRIX_DRIVE_Q2N },  // Column 6
  { PIN_MATRIX_DRIVE_Q6P, PIN_MATRIX_DRIVE_Q2N }   // Column 7      
};
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

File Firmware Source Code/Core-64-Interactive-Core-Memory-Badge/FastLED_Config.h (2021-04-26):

/*
PURPOSE: Configure the NeoPixel Style LED Array for the FastLED library
Pimoroni Unicorn Hat: https://shop.pimoroni.com/products/unicorn-hat 
*/
 
#ifndef FASTLED_CONFIG_H
#define OFASTLED_CONFIG_H

#if (ARDUINO >= 100)
#include <Arduino.h>
#else
#include <WProgram.h>
#endif

#include <stdint.h>
#include "HardwareIOMap.h"

#ifdef __cplusplus
extern "C" {
#endif

#define COLOR_ORDER GRB
#ifdef CORE64_LED_MATRIX
	#define CHIPSET     WS2813			// Used in Core64 LED MATRIX
#else
	#define CHIPSET     WS2812B			// Used in Pimoroni Unicorn Hat. Limited to a data rate of about 800Kbps, hard coded in FastLED library. 
#endif
#define BRIGHTNESS       75			// Initial brightness level
#define BRIGHTNESS_MIN	  5			// Lowest useable brightness
#define BRIGHTNESS_MAX	255			// Highest useable brightness

// 100 = GREEN
// 135,255,255 = OLED aqua
#define DEFAULTLEDArrayMonochromeColorH		135
#define DEFAULTLEDArrayMonochromeColorS		255
#define DEFAULTLEDArrayMonochromeColorV 	255


const uint8_t kMatrixWidth = 8;
const uint8_t kMatrixHeight = 8;
#ifdef CORE64_LED_MATRIX
	const bool    kMatrixSerpentineLayout = false;	
#else
	const bool    kMatrixSerpentineLayout = true;
#endif

#define NUM_LEDS (kMatrixWidth * kMatrixHeight)
CRGB leds_plus_safety_pixel[ NUM_LEDS + 1];
CRGB* const leds( leds_plus_safety_pixel + 1);

#ifdef __cplusplus
} // extern "C"
#endif

#endif

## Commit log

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2019-08-25 Added lots of documentation
    BOM, Code plan, Dev plan, Electrical Block Diagram, Licensing analysis, Manufacturing considerations, schematic.
    [BOM Core 64 v0.1.xls, Core 64 Teensy LC Pin Usage Mapping.xlsx, Interactive Core Memory Badge v0.1 BOM.xlsx]
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2020-02-17 Testing core matrix row and column activation
    Row 0 has loose connection. Row 1 works in columns 0-3. Row 2 work entirely. Column 0-3 work. Column 4-7 only works for CLEAR, but SET does not show current flow.
    [core flip sense voltage threshold.xlsx]
2020-02-18 Core 0-31 in first four rows confirmed working together in sequence.
    Core_Mem_Bit_Write rewrite and decrease duration 3us, most FETs replaced with transistors.
    [Core-64-Interactive-Core-Memory-Badge.ino, Core_Driver.cpp]
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2020-02-22 Added ReturnMatrixQ9NtoLowForLEDArray() to not interfere with LED Array data pin.
    And added 40us delay between core read/write to prevent Q9N from looking like LED Data!
    [Core-64-Interactive-Core-Memory-Badge.ino, Core_Driver.cpp, HardwareIOMap.h]
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2020-02-25 Updated flip sense resistors 22 to 11 Ohm
    [core flip sense voltage threshold.xlsx]
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2020-03-01 BOM V0.1 math errors corrected
    [BOM Core 64 v0.1.xls]
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2020-03-01 It's working! But now the OLED display is more unstable, scrolling.
    [Core-64-Interactive-Core-Memory-Badge.ino, OLED_Screen.cpp]
2020-03-01 Trying to stabilize the OLED display contents...
    [Core-64-Interactive-Core-Memory-Badge.ino, OLED_Screen.cpp]
2020-03-02 OLED Display Stability Fixed!
    Added invert/revert to OLED screen buffer to force a clean refresh. Display is stable now.
    [OLED_Screen.cpp]
2020-03-04 BOM correct LED Array cost
    [BOM Core 64 v0.1.1.xls, BOM Core 64 v0.1.xls]
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2020-03-19 Update v0.2 with correct Pimoroni footprint
    [Interactive Core Memory Badge v0.2.kicad_pcb, Interactive Core Memory Badge v0.2.sch]
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2020-03-21 Core logic board split to 5 sheets, power/driver sheet draft, pcb draft.
    [Interactive Core Memory Badge (Logic) Driver v0.3.sch, Interactive Core Memory Badge (Logic) MCU v0.3.sch, Interactive Core Memory Badge (Logic) Main v0.3.sch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]
2020-03-22 Add hall data sheets and update reverse polarity protection screen grab.
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2020-04-07 Update SMD-TO pad sizes, add EEPROM, add RasPI header to LED array
    [Interactive Core Memory Badge (Cores) v0.3.kicad_pcb, Interactive Core Memory Badge (Logic) Driver v0.3.sch, Interactive Core Memory Badge (Logic) IO Expansion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]
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2020-05-28 Hall sensor P/N corrected in I2C Scanner
    [I2C_Manager.cpp]
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2020-05-29 Add Teensy LC cut Vin-Vusb instructions, BOM assembly tracking Board ID section.
    [BOM Core 64 v0.3.0 Red Dual Boards.xlsx]
2020-05-30 Hardware detection working. Removed src/libraries conflicts to rely on Arduino Library Manager.
    [BOM Core 64 v0.3.0 Red Dual Boards.xlsx]
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2020-06-07 Repair hall switch operation with v0.2 hardware
    Clean-up changes in hall switch operation of v0.3 hardware broke v0.2 operation.
    Had to move Buttons_Setup AFTER hardware version detection.
    Clarified buttons operation comments in Buttons_HAL.h and Core-64.ino.
    Clarified hardware and firmware version comments in HardwareIOMap.h.
    [Core-64-Interactive-Core-Memory-Badge.ino, HardwareIOMap.h]
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2020-06-13 Remove I2CIOESetup() to allow set-up in each driver independently
    Pin usage mapping updated with 17 for LED array (was wrong at 14) and 14 is SD Card Clock.
    Clean-up #define pin definitions in HardwareIOMap.h for all hardware versions through v0.3.0.
    [Core 64 Pin Usage Mapping.xlsx]
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2020-07-05 Add reverse polarity N-CH 6344 MOSFET Datasheet
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2020-07-19 Fix V0.2 core operation by not activating interfering SPI bus pins
    [SD_Card_Manager.cpp]
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2020-08-02 Correct hall sensor sample code format and typos
    [Buttons_HAL.cpp, HardwareIOMap.h]
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2020-08-05 Update Pin Usage, drop hall switches, add IR TX pin, clean-up power names
    [Core 64 Pin Usage Mapping.xlsx]
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2020-08-09 Wrap SD write cases in {braces} to correct compiler warnings about variables crossing boundaries
    [Core-64-Interactive-Core-Memory-Badge.ino, SD_Card_Manager.cpp]
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2020-08-22 Add Mode - + Set button in Commodore font, clean-up silk screen, solder mask between 16x T.H. and pads
    [Core64 CB v0.4.kicad_pcb, Core64 CB v0.4.sch]
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2020-08-28 Correct Logic Board filenames to LB from CB
    [Core64 LB v0.4 Driver.sch, Core64 LB v0.4 Expansion.sch, Core64 LB v0.4 Power.sch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]
2020-08-28 Swap in Teensy 3.2 from LC, set schematic sheet sizes to A, update power schematic
    [Core64 LB v0.4 Expansion.sch, Core64 LB v0.4 Power.sch, Core64 LB v0.4 Sense.sch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]
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2020-09-23 Correct LTR scalar variable typo
    [Ambient_Light_Sensor.cpp]
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2020-10-25 Complete Adafruit 3.2" TFT symbol and foot print and placement on LB
    [Core64 LB v0.4 Expansion.sch, Core64 LB v0.4.kicad_pcb]
2020-10-26 Update footprint mounting holes TFT, LED array, battery packs, lipo charger, arrange components to fit on the board
    [Core 64 Pin Usage Mapping.xlsx, Core64 LB v0.4 Driver.sch, Core64 LB v0.4 Expansion.sch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]
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2020-11-11 Complete LB Schematic red-line updates, update RPP and Matrix FETs with reduced RDSon.
    [Core64 LB v0.4 Driver.sch, Core64 LB v0.4 Power.sch, Core64 LB v0.4.kicad_pcb]
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2020-11-15 Review and test SPI pins with Teensy 3.2
    Move Q5P/N, BACKLIGHT to PWM, Sense Reset by Sense Pulse and Enable, move SPI CS/DC pins that didn't work with ILI9341_t3n
    [Core 64 Pin Usage Mapping.xlsx, Core64 LB v0.4 Driver.sch, Core64 LB v0.4 Expansion.sch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]
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2020-11-17 Route all Teensy pins and most of the bottom half of the LB
    [Core64 LB v0.4 Expansion.sch, Core64 LB v0.4.kicad_pcb, Core64 LB v0.4.sch]
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2020-11-24 Clean-up BOM for LB V0.4 parts order - and order 1 set of prototype parts!
    [BOM Core 64 v0.4.0 CB Yellow LB Blue.xlsx]
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2020-11-29 Begin V0.4 firmware branch, monochrome OLED works, working on Unicorn Hat control
    [BOM Core 64 v0.4.0 CB Yellow LB Blue.xlsx]
2020-11-29 Make MODE hall sensor "button" work correctly
    [Buttons_HAL.cpp, Core-64-Interactive-Core-Memory-Badge.ino, Core_Driver.cpp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]
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2020-12-01 Fix core_driver and now it works! Added leading zero to align Matrix Drive Pin Number array. Swapped top four and bottom four CMMDSet/ClearRowByBit rows in array to get cores and LEDs matched up.
    [Core-64-Interactive-Core-Memory-Badge.ino, Core_Driver.cpp, HardwareIOMap.h]
2020-12-01 Fix accidental immediate clearing upon entering draw mode
    [Core-64-Interactive-Core-Memory-Badge.ino, HardwareIOMap.h]
2020-12-02 Make ALS kinda-working Needs more work for some glitchy behavior. Details in top of LTR329_Driver.cpp file.
    [Ambient_Light_Sensor.cpp, HardwareIOMap.h, LTR329_Driver.cpp]
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2020-12-09 Troubleshoot LCD chip select for Neon Pixel byte order glitches
    [HardwareIOMap.h, NeonPixelMatrix.cpp]
2020-12-10 Correct Neon Pixels to use OLED CS instead of LCD CS port Why are first two SPI bytes showing up on Neon Pixel array as pixel 8 and 16? And why is last SPI byte showing up as pixel 0?
    [HardwareIOMap.h, NeonPixelMatrix.cpp]
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2021-01-16 Update v0.4 BOM.xlsx, move to Google Sheet, deprecated xlsx version - for history only
    [BOM Core 64 v0.4.0 CB Yellow LB Blue.xlsx]
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2021-02-03 Update docs and to-dos, add 7th analog option Create test folder and move test files in to it. Pin mapping.xlsx deprecated after v0.4. Disable #define SDCard. Add analog input setup #7. TPS 3V3 Reg d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
    [Core 64 Pin Usage Mapping v0.1-v0.4.xlsx, Core 64 Pin Usage Mapping.xlsx, V0.2 Battery Calibration and Runtime Test.xlsx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]
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2021-02-05 Create CB v0.5 KiCAD project, swap S1 and S2 labels
    [Core64 CB v0.5.kicad_pcb, Core64 CB v0.5.sch]
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2021-02-13 Add optional LiPo charger, QWIIC, OLED I2C to LED Matrix, change to start with V0.1
    [Core64 LM v0.1 Expansion.sch, Core64 LM v0.1.kicad_pcb, Core64 LM v0.1.sch]
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2021-02-26 Move LiPo Charger to top edge, increase LCD footprint top header edge up 1mm
    [Core64 LB v0.5 Power.sch, Core64 LB v0.5.kicad_pcb]
2021-02-27 Update schematic battery and LiPo charger notes, move SD_CD from ANA_6 to SPARE_3, schematic red lines
    [Core64 LB v0.5 Driver.sch, Core64 LB v0.5 Expansion.sch, Core64 LB v0.5 Power.sch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]
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2021-03-09 Swap LiPo charger USB Micro to C, remove Pimoroni 3pin, add second OLED at top
    [Core64 LM v0.2 Expansion.sch, Core64 LM v0.2.kicad_pcb, Core64 LM v0.2.sch]
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2021-03-21 Update U1 and U7 silkscreen placement to be ready for next revision, V0.5 assembly BOM reviewed during first assembly
    [Core64 LB v0.5 BOM.xlsx, Core64 LB v0.5.kicad_pcb]
2021-03-21 Update schematic and BOM hardware ID EEPROM from 128 to 256 Byte
    [Core64 LB v0.5 BOM.xlsx, Core64 LB v0.5 Sense_LEDs_ID.sch]
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2021-04-03 Correct mistake, extend trace to pad 14 on J1 from bottom GNND of QWIIC and XLM2
    [Core64 LM v0.2.kicad_pcb]
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2021-04-11 Attempt to stabilize ALS behavior
    [Ambient_Light_Sensor.cpp, HardwareIOMap.h]
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2021-05-18 Create Led Matrix V0.3 EDA files, add opt. 5V0 cap, refine schematic notes
    [Core64 LM v0.3 Expansion.sch, Core64 LM v0.3.kicad_pcb, Core64 LM v0.3.sch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]
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2021-08-07 Add opt. 5V0 buffer cap SMD and T.H., add PCB P/N, move corner holes to 37.7mm, move diffuser alignment mount points out and disconnect from GND, silkscreen cleanup
    [Core64 LM v0.3 Expansion.sch, Core64 LM v0.3.kicad_pcb, Core64 LM v0.3.sch]
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2021-08-09 CB refine silkscreen, change center ALS BH1730 opening to drill hole and remove center solder pad, clean-up ref. des. numbers
    [Core64 CB v0.6 Optional.sch, Core64 CB v0.6.kicad_pcb, Core64 CB v0.6.sch]
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2021-10-15 CB V0.6 added ALS and PROX, removed bottom ALS, complete BOM, PNP, and Gerbers for fabrication
    [BOM_Core64_CB_V0.6_2021-10-14.xlsx, Core64 CB v0.6 Optional.sch, Core64 CB v0.6.kicad_pcb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]
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2021-11-08 APPLY LOGIC BOARD V0.5 FIXES NEEDED TO BE V0.6 U1 silk screen should be placed by pin 1 not pin 7 Check J1 and J2 labels so J1 is on the left, like it is for the Core Board Remove Header for old LED 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
    [Core64 LB v0.6 Driver.sch, Core64 LB v0.6 Expansion.sch, Core64 LB v0.6 Power.sch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]
2021-11-09 Revise LB V0.6, part substitutions, data sheet updates, clean up Ref. Des. to be in order and easier to find on the board in groups
    [Core64 LB v0.6 Driver.sch, Core64 LB v0.6 Expansion.sch, Core64 LB v0.6 Power.sch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]
2021-11-09 Refine LB v0.6 layout, KiCAD BOM updates, review schematic and PCB for release
    [Core64 LB v0.6 Driver.sch, Core64 LB v0.6 Expansion.sch, Core64 LB v0.6 Power.sch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]
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2022-06-13 Core Board v1.0 created from v0.6 and released.
    Remove Hall switch SM353LT from the schematic because it's pole alignment does not work with the stylus.
    Add note to schematic "if hall switches are used, they default to being connected to Plane5-8 wiring, without requiring any Solder Jumpers to be soldered."
    Update silkscreen P1G1 and P2G2 to CP1G1 and CP2G2.
    Update V1.0 silk screen, schematic notes, PCBA and PCB P/N.
    Production to use ALS329.
    [BOM_Core64_CB_V1.0_2022-06-02.xlsx, Core64 CB v1.0 Optional.sch, Core64 CB v1.0.kicad_pcb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]
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2023-05-22 Fixed LED Array Manufacturing Instructions (A) conflicted copy
2024-10-10 Remove LED Array Manufacturing Instructions Rev A to be replaced with Rev B
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
